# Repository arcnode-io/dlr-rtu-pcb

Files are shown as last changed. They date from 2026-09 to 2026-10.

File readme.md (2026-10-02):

# DLR RTU PCB 🌡️⚡







> Single-PCB CM4 carrier for a solar-powered, cellular-connected RTU — mounts to a transmission tower cross-arm, integrates SoM + cellular modem + IEEE 738 sensor suite + solar/LiFePO4 power management. Feeds [`dlr-rtu-firmware`](https://gitlab.com/arcnode-io/dlr-rtu-firmware).

Solar-powered remote terminal unit (RTU) deployed unattended on transmission tower cross-arms. A ~20W solar panel and ~50Wh LiFePO4 battery keep the CM4 running indefinitely with cellular PSM idle. A soldered Quectel BG770A (LTE Cat-M1) publishes sensor data and dynamic ratings to the MQTT broker — no site WiFi or wired backhaul required. The unit is designed for 30-year conductor-adjacent deployment with no scheduled maintenance.

~100x80mm 4-layer industrial carrier. Raspberry Pi CM4 (DF40 dual-connector) + Quectel BG770A LCC + FLIR Lepton 3.5 (SPI) + DHT22 (GPIO) + SI1145 (I2C) + YL-83 (analog via ADS1115). MPPT charger from PV input, LiFePO4 BMS, buck for 5V SoM rail, AP2112K LDO for 3.3V analog front-end. Conformal coated, IP55 when potted in field enclosure.

## System Context

```plantuml
rectangle transmission_tower {
  rectangle field_enclosure {
    rectangle dlr_carrier {
      rectangle cm4_som
      rectangle cellular_module
      rectangle sensors
      rectangle power_mgmt
    }
  }
  rectangle solar_panel
  rectangle lifepo4_battery
  rectangle conductor
}

queue mqtt_broker
rectangle dispatch_api

solar_panel -d- power_mgmt: PV input
power_mgmt -l- lifepo4_battery: charge / discharge
power_mgmt -d- cm4_som: 5V / 3V3
conductor -u- sensors: thermal view\n(FLIR Lepton)
sensors -r- cm4_som: SPI / I2C / GPIO
cm4_som -r- cellular_module: UART + USB2
cellular_module -r- mqtt_broker: LTE Cat-M1
mqtt_broker -r- dispatch_api: dynamic line rating\n(utility/dlr/...)
```

The carrier is the physical sensing + edge-compute layer of the DLR feedback loop. Every measurement flows through the IEEE 738 calculation in [`dlr-rtu-firmware`](https://gitlab.com/arcnode-io/dlr-rtu-firmware), which publishes the resulting dynamic line rating for `mock-derms-dispatch-api`'s DER curtailment trigger.

## Board Spec

```mermaid
graph LR
    SOLAR["Solar Panel<br/>~20W 12V"] --> MPPT["BQ24650 MPPT<br/>+ 2x DMN4035L"]
    MPPT --> BAT["LiFePO4 4S<br/>~50Wh + BMS"]
    BAT --> BUCK["Buck<br/>5V 3A"]
    BUCK --> CM4["CM4 SoM<br/>DF40 x2"]
    BUCK --> BG["Quectel BG770A<br/>Cat-M1 LCC"]
    BUCK --> LDO["AP2112K<br/>3.3V LDO"]
    LDO --> ADC["ADS1115<br/>I2C 0x48"]
    LDO --> UV["SI1145<br/>I2C 0x60"]
    CM4 --> FLIR["FLIR Lepton 3.5<br/>SPI0 + GPIO25"]
    CM4 --> DHT["DHT22<br/>GPIO4"]
    CM4 --> ADC
    CM4 --> UV
    ADC --> RAIN["YL-83<br/>Analog 0-3.3V"]

    style SOLAR fill:#dc4,stroke:#333
    style MPPT fill:#a94,stroke:#333
    style BAT fill:#a94,stroke:#333
    style BUCK fill:#a94,stroke:#333
    style LDO fill:#a94,stroke:#333
    style CM4 fill:#4a9,stroke:#333,color:#fff
    style BG fill:#49a,stroke:#333,color:#fff
    style FLIR fill:#49a,stroke:#333,color:#fff
    style DHT fill:#94a,stroke:#333,color:#fff
    style ADC fill:#94a,stroke:#333,color:#fff
    style UV fill:#94a,stroke:#333,color:#fff
    style RAIN fill:#669,stroke:#333,color:#fff
```

## CM4 Pinout

```mermaid
flowchart LR
classDef default fill:transparent,stroke:#333
classDef pwr fill:#4a9,stroke:#333,color:#fff
classDef spi fill:#49a,stroke:#333,color:#fff
classDef i2c fill:#94a,stroke:#333,color:#fff
classDef gpio fill:#a94,stroke:#333,color:#fff
classDef uart fill:#a49,stroke:#333,color:#fff
classDef usb fill:#669,stroke:#333,color:#fff

subgraph cm4 ["CM4 (DF40-100)"]
  p_5v["5V_IN"]
  p_sda["GPIO2 SDA1"]
  p_scl["GPIO3 SCL1"]
  p_g4["GPIO4"]
  p_g25["GPIO25"]
  p_mosi["GPIO10 MOSI"]
  p_miso["GPIO9 MISO"]
  p_sck["GPIO11 SCLK"]
  p_ce0["GPIO8 CE0"]
  p_txd["GPIO14 TXD"]
  p_rxd["GPIO15 RXD"]
  p_usb["USB2 D+/D-"]
end

subgraph onboard ["Carrier Components"]
  flir["FLIR Lepton 3.5"]
  dht["DHT22"]
  si["SI1145"]
  ads["ADS1115"]
  yl["YL-83"]
  bg["BG770A"]
end

p_mosi --> flir
p_miso --> flir
p_sck --> flir
p_ce0 --> flir
p_g25 --> flir
p_g4 --> dht
p_sda --> si
p_scl --> si
p_sda --> ads
p_scl --> ads
ads --> yl
p_txd --> bg
p_rxd --> bg
p_usb --> bg

class p_5v pwr
class p_mosi,p_miso,p_sck,p_ce0 spi
class p_sda,p_scl i2c
class p_g4,p_g25 gpio
class p_txd,p_rxd uart
class p_usb usb
```

## Sensor Interfaces

| Sensor | Interface | CM4 Pins | Sample Rate | Measurement | Feeds IEEE 738 Variable |
|---|---|---|---|---|---|
| FLIR Lepton 3.5 | SPI0 + VSYNC | GPIO 8, 9, 10, 11, 25 | 8.6 Hz (frame) | Conductor surface temp | $R_{thermal}$ |
| DHT22 | GPIO4 (1-Wire) | GPIO 4 | 0.5 Hz | Ambient temp + humidity | $T_{amb}$ |
| SI1145 | I2C (0x60) | GPIO 2, 3 | 10 Hz | UV / Visible / IR irradiance | $\Delta T_{solar}$ |
| YL-83 → ADS1115 | I2C (0x48) ch0 | GPIO 2, 3 | 860 SPS | Rain intensity (0–3.3V analog) | $\Delta T_{rain}$ |

Every sensor reading on this board maps to exactly one term in the IEEE 738 dynamic rating equation:

$$ I_{max} = \sqrt{\frac{q_c + q_r - q_s}{R_{ac}}} $$

## Anemometer Variants

Single PCB + single firmware binary. Variant lives in the **kit BOM** — sensor,
cable harness, PV panel, and battery differ per SKU. Both sensors speak
NMEA 0183 (`$..MWV`) over RS-485, so the firmware driver is talker-agnostic.

### Kit BOM

| Component | High-wind kit (`DLR-CRN-HW`) | Low-wind kit (`DLR-CRN-LW`) |
|---|---|---|
| PCB | `dlr-rtu-pcb-v1` (same) | `dlr-rtu-pcb-v1` (same) |
| Firmware | `dlr-rtu-firmware` (same binary) | `dlr-rtu-firmware` (same binary) |
| Sensor | Calypso ULP STD | Vaisala WMT702 |
| Sensor wire protocol | NMEA `$IIMWV` over RS-485 | NMEA `$WIMWV` over RS-485 |
| Sensor accuracy (V<2 m/s) | ±5 % + 0.2 m/s offset (1 m/s threshold) | **±0.1 m/s** (0.01 m/s threshold) |
| Sensor op temp | unspecified (consumer-grade) | -10 to +60 °C |
| Cable harness | 5 m bare-wire to M12-5P | 5 m Cannon Trident 19-way to M12-5P |
| PV panel | 20 W | **30 W** |
| Battery | 50 Wh LiFePO4 | **100 Wh LiFePO4** |
| Sticker | `HW-1.0` | `LW-1.0` |
| Kit cost (approx) | ~$650 | ~$2350 |

### When to deploy which variant

Per-site SKU pick uses NREL WIND Toolkit climatology (or customer SCADA wx
history when available). Threshold: fraction-of-year with V_w < 1 m/s
perpendicular to conductor.

| Climatology | Variant | Why |
|---|---|---|
| ≤ 15 % yr V_w < 1 m/s (ridge / coastal / open plain w/ mean ≥ 6 m/s) | high-wind | uplift slice below 1 m/s is marginal; static fallback below threshold is fine |
| > 15 % yr V_w < 1 m/s (valley / sheltered / open plain w/ mean ≤ 5 m/s) | low-wind | uplift slice is material; pay $1.7 k premium to capture it |

### Fallback policy (both variants)

When the sensor reports `void` status, times out, or has a checksum/parse
error, the driver returns `None`. The IEEE 738 layer collapses None →
`V_w = 0.0` → natural-convection-only ampacity = the conductor's static
rating. Same conservative fallback used for the icing-fallback policy.

### Variant power budget

| | High-wind | Low-wind |
|---|---|---|
| Sensor continuous draw | 1 mW | 480 mW |
| System daily energy | 29.1 Wh | 40.6 Wh |
| Winter PV harvest (worst) | 45 Wh | 67.5 Wh |
| Winter margin | 1.55× | **1.66×** |
| Battery autonomy at 0 PV | 1.58 d | **2.22 d** |

Low-wind variant's 30 W / 100 Wh upgrade absorbs the WMT702's higher draw and
restores both winter margin and 2-day autonomy.

## Power Budget

| Rail | Source | Consumer | Idle (PSM) | Typical | Peak |
|---|---|---|---|---|---|
| 5V | Buck | CM4 | 80 mA | 1400 mA | 3000 mA (boot) |
| 5V | Buck | Quectel BG770A | <1 mA | 100 mA | 250 mA (TX) |
| 5V | Buck | FLIR Lepton 3.5 | 150 mA | 150 mA | 650 mA (shutter) |
| 5V | Buck | DHT22 | 1.5 mA | 1.5 mA | 2.5 mA |
| 3.3V | AP2112K LDO | ADS1115 + SI1145 + YL-83 | 9 mA | 9 mA | 14 mA |
| | | **Total @ 5V equiv** | **240 mA** | **1660 mA** | **3920 mA** |

The 3920 mA peak is a worst-case *sum*, not a supported operating point. The LMR33630 delivers 3.375 A with worst-case silicon, so a coincident CM4-boot + Lepton-shutter + modem-TX peak browns the rail out below the CM4's 4.75 V floor — firmware sequences those loads apart (**ADR-017**, derived in `theory.ipynb` §7 and asserted in `sim/test_spice.py`). The CM4 boot peak on its own holds the rail at ~4.95 V.

Daily energy with CM4-always-on idle + 1/min sensor wake + 1/15 min cellular TX: **~29 Wh/day** (derived in `theory.ipynb`). A 50 Wh battery (90% DoD) gives ~1.6 days autonomy with no PV. A 20W panel at 2.5 sun-hours/day (winter Northeast US worst case) delivers ~45 Wh/day after MPPT η — **1.55x winter margin**, 2.5x annual avg.

That margin assumes a 120 mA CM4 idle (tuned Pi OS Lite, headless). The CM4 datasheet §5.3 quotes ~400 mA typical idle; at that figure the budget is 62.6 Wh/day and the 20 W panel does **not** carry winter (0.72x). Idle current is the single measurement that most needs a bench check before committing to the panel size.

## Environmental

| Parameter | Spec | Notes |
|---|---|---|
| Operating temp | -20°C to +85°C | CM4 commercial spec; cold-start heater required below -20°C |
| Conformal coat | Dow Corning 1-2577 | Applied post-assembly, mask connectors |
| Enclosure rating | IP55 (with field enclosure) | Board alone is not rated |
| Vibration | IEC 60068-2-6 (5–500 Hz, 2g) | Transmission tower wind loading |
| Expected service life | 30 years | Matches conductor replacement cycle |
| MTBF | >200,000 hours | Derated per MIL-HDBK-217F |
| Mounting | M3 standoffs, 4-corner | Single rigid PCB — no stack |

## Fabrication Pipeline

Fully scripted — no GUI step. KiCad's "Update PCB from Schematic" is GUI-only, so `cad/drawing/sync_pcb.py` does the same job from the SKiDL netlist: it rebuilds every footprint from the library and reassigns every pad net, which is what keeps the board honest about what the schematic says.

```
 1. uv run poe notebook         → theory.ipynb: power, signal integrity, 5V transients
 2. uv run poe build            → SKiDL netlist
 3. uv run poe schematic        → hierarchical .kicad_sch (one sheet per block)
 4. uv run poe validate-model   → ERC, 0 violations (exits non-zero otherwise)
 5. uv run poe sim / cover      → pytest: hand calcs + ngspice transients

 6. uv run poe layout-asm       → the whole board flow, in order:
      build       netlist from SKiDL
      sync-asm    footprints + pad nets  <- replaces the GUI "Update PCB from Schematic"
      place-asm   positions from cad/pcb_placement.yaml
      setup-asm   4-layer stack, design rules, net classes, GND + 5V planes
      fanout-asm  escape vias for the 0.4 mm connector, assigned before routing
      route-asm   Specctra DSN -> Freerouting -> SES import -> zone fill
      stitch-asm  vias from surface pads to their plane
      validate-asm DRC, 0 violations

    ┌──────────────────────────────────────────────────────┐
    │  HUMAN: review the render, adjust pcb_placement.yaml │
    └──────────────────────────────────────────────────────┘

 7. uv run poe generate-asm     → gerbers + drill + STEP + BOM + CPL
```

### Board status

ERC is 0. DRC is clean of clearance, short, annular-ring, hole and courtyard errors —
what is left is 7 silkscreen-overlap warnings and **2 open connections** out of 457
pads, both of them ground pins on J5 (Hirose DF40, 0.4 mm pitch):

| Net | Pad | At (mm) |
|---|---|---|
| GND | J5.20 | 197.80, 94.46 |
| GND | J5.25 | 199.00, 97.54 |

Both are redundant pins — the CM4 bonds its grounds internally — so what is missing is
return-path quality at that corner of the connector, not a broken net. It is still a
DRC error, so the gerbers in `output/` stay a preview until it closes.

**Why they are open.** It is a fanout-capacity limit, not a search failure. A row of
0.6 mm escape vias needs 0.75 mm centre to centre, so on a 0.4 mm pad pitch only every
other pin gets a via in the first row. The pins that miss out have to reach a second,
deeper row — but two 0.6 mm vias 0.75 mm apart leave a 0.15 mm slot, and a 0.2 mm trace
with 0.15 mm clearance needs 0.5 mm. **Once the first row is populated the second row is
unreachable.** Via rows have to be assigned before any routing happens; a router that
picks the nearest free site per pin always finishes one slot short.

`cad/drawing/fanout.py` does that assignment: it clears the connector's fanout band and
alternates along each pad row, one pin into the inter-row gap, the next out the back, so
same-side vias land 0.8 mm apart. It places all 39 escapes on J5 with zero clearance,
short or drill violations — the geometry works.

What is *not* done is the rebuild. Run on a board that is already routed, the pass has
to clear 223 tracks and vias to own its band, and `escape_pins` rebuilds only 23 of the
35 connections that leaves open — a net regression against the 2 here. Its place is
before Freerouting, where a full-strength router does the reconnection, which is where
`poe layout-asm` now calls it. **That path has not been run end to end yet**, so the
board in this repo is still the pre-fanout one. Closing the last two means either that
full regeneration, or 0.45 / 0.25 mm vias (JLCPCB advanced tier, and the 0.13 mm
annular-ring rule would have to come down with them), or six layers.

### Toolchain

**KiCad 10 required.** The board is KiCad 10 format (`20260206`); on KiCad 9
`poe validate-asm` says DRC could not run rather than passing silently. The CI
runner gets 10.x from Flatpak. The schematic is format `20250114`, which both
versions read.

ERC is a blocking gate in CI. DRC runs and reports but does not gate yet — the two
open ground pins above are real errors; the `|| echo` comes off once they are closed.

## Layer Stack

4-layer, 1.6 mm FR4, controlled impedance (ADR-016). Applied by `cad/drawing/board_setup.py`, so a regenerated board always has the same stack.

| Layer | Use |
|---|-----|
| F.Cu | Signal — high-speed (SPI 20MHz, USB2.0 to BG770A) |
| In1.Cu | GND plane, unbroken (reference for the USB pair and the Lepton SPI) |
| In2.Cu | 5V_RAIL plane — CM4, both LDOs and the Lepton feed off it via drops |
| B.Cu | Signal — low-speed (I2C, GPIO, UART) |

Signals are confined to F.Cu / B.Cu: the router is told the inner layers are `power` type, so nothing slices a plane. VBAT, 3V3 and 3V8 run as 0.6 mm traces (`power` net class), necked to 0.25/0.2 mm where an escape has to squeeze past a 0.4 mm-pitch pad. Every via is 0.6/0.3 mm: a 0.5/0.25 mm via would ease the DF40 fanout but leaves a 0.125 mm annular ring, under the 0.13 mm rule.

Unbroken ground plane under the Lepton is critical — SPI runs at 20 MHz and the thermal imager is noise-sensitive. USB2.0 to the BG770A is differential-routed at 90Ω matched impedance with GND directly below. Analog traces from YL-83 to ADS1115 are guard-ringed on F.Cu. Cellular antenna is 50Ω microstrip to a u.FL connector.

## Project Structure

```
├── pyproject.toml              # Dependencies and build config
├── theory.ipynb                # Power, signal integrity, 5V transient derivations
├── sim/
│   ├── constants.py            # Sourced part parameters (datasheet + edition cited)
│   ├── model.py                # Closed-form: buck current, energy, I2C/SPI/USB
│   ├── spice_bank.py           # Shared 5V output capacitor bank
│   ├── spice_ripple.py         # ngspice: open-loop switching ripple (Eq 7)
│   ├── spice_load_step.py      # ngspice: averaged current-mode boot-peak droop
│   ├── test_run.py             # Assert closed-form results match theory.ipynb
│   └── test_spice.py           # Assert ngspice results match theory.ipynb §7
├── cad/
│   ├── netlist/
│   │   ├── model.py            # Top-level SKiDL circuit (main carrier)
│   │   ├── charger.py          # Solar input + BQ24650 MPPT charger (ADR-015)
│   │   ├── power.py            # LMR33630 5V buck + AP2112K / LP5907 LDOs
│   │   ├── som.py              # CM4 DF40 connector + decoupling
│   │   ├── cellular.py         # BG770A + SIM holder + u.FL
│   │   ├── sensors.py          # FLIR (FFC), DHT22, SI1145, ADS1115, YL-83
│   │   ├── anemometer.py       # RS-485 wind sensor port (SKU-agnostic)
│   │   ├── connectors.py       # Battery + debug + USB-C commissioning
│   │   └── lepton_daughter.py  # Daughterboard SKiDL (Molex socket + FFC)
│   ├── schematic/              # Hierarchical .kicad_sch generator
│   │   ├── schematic.py        # Netlist parse, block classification, placement
│   │   ├── multi_sheet.py      # Per-block child sheets, power symbols, PWR_FLAG
│   │   ├── root_sheet.py       # Root sheet + cross-net sheet pins
│   │   └── sch_guard.py        # Fails the build on cross-net wire/pin collisions
│   ├── drawing/                # Board pipeline (system python3 — pcbnew)
│   │   ├── sync_pcb.py         # Footprints + pad nets from the netlist
│   │   ├── place_pcb.py        # Positions from pcb_placement.yaml
│   │   ├── board_setup.py      # 4-layer stack, rules, net classes, planes
│   │   ├── route_pcb.py        # DSN -> Freerouting -> SES -> fill
│   │   ├── fanout.py           # Pre-assigned escape vias for fine-pitch connectors
│   │   ├── stitch_planes.py    # Surface-pad vias into the planes
│   │   ├── close_gaps.py       # L-shaped hops across the autorouter's leftovers
│   │   ├── maze_grid.py        # Grid window shared by the escape router
│   │   ├── maze_field.py       # Analytic clearance fields (foreign copper only)
│   │   ├── maze_search.py      # Grid A*, 8-way, with via layer changes
│   │   ├── maze_escape.py      # Route + verify one connection, or tear it out again
│   │   ├── escape_pins.py      # Drives the escape router off the DRC report
│   │   ├── rip_targets.py      # Finds a stranded pin's blockers; performs the rip
│   │   └── rip_up.py           # Rip / re-route / keep-only-if-better loop
│   ├── lepton_daughter/        # Second PCB (per ADR-013) — Lepton + bracket
│   ├── assembly/               # CadQuery → GLB pipeline (build_assembly.py)
│   ├── layout_spec.yaml        # Schematic block layout
│   ├── pcb_placement.yaml      # Main-PCB component positions
│   └── drawing-sheet.kicad_wks # Title block
├── output/
│   ├── drawings/               # Schematic SVG + PDF
│   ├── gerbers/                # Fabrication files
│   └── fab/                    # BOM + CPL for assembly
└── readme.md                   # This file
```

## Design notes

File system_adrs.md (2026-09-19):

# DLR Carrier Board — Architecture Decision Records

Captures architectural and component decisions for the DLR PCB. New decisions append as ADR-NNN; supersedes are explicit. Date format ISO 8601.

## Index

| # | Decision | Class |
|---|---|---|
| 001 | Single-PCB CM4 carrier | Architecture |
| 002 | Battery — LiFePO4 4S | Architecture |
| 003 | Cellular bands — NA-only | Architecture |
| 004 | Solar panel — 20W | Architecture |
| 005 | I2C clock — 400 kHz | Architecture |
| 006 | Antenna form — u.FL + external blade | Architecture |
| 007 | 5V buck — TI LMR33630 | Component |
| 008 | MPPT charger — TI BQ24650 | Component |
| 009 | BMS — JBD-SP04S013 (on-pack) | Component |
| 010 | BG770A 3.8V LDO — TI LP5907 | Component |
| 011 | Level shifter — TI TXS0108E | Component |
| 012 | u.FL connector — Hirose U.FL-R-SMT-1(10) | Component |
| 013 | Lepton daughterboard for aim flexibility | Architecture |
| 014 | 5V buck inductor — Bourns SRN8040TA-100M | Component |
| 015 | MPPT charger support network — BQ24650 per SLUSA75B | Architecture |
| 016 | Layer stack — 4-layer SIG / GND / 5V / SIG | Architecture |
| 017 | 5V rail load sequencing — firmware constraint | Architecture |

---

## ADR-001: Single-PCB CM4 Carrier (vs Pi HAT)

**Status:** Accepted **Date:** 2026-05-08

### Context
30-yr maintenance-free transmission tower deployment, IP55 potted enclosure, IEC 60068-2-6 vibration (5–500 Hz, 2g), −20 to +85°C operating temp, solar+LiFePO4 budget. Initial readme proposed a Pi 5 HAT stack.

### Decision
Single-PCB ~100×80mm 4-layer carrier with Raspberry Pi CM4 mounted via DF40 connector pair. All cellular, sensor, and power-management circuitry on the same board.

### Rationale
- Pi 5 is consumer-grade (0–50°C) and won't survive spec'd environment
- 40-pin HAT stack is a vibration failure mode (connector fretting + lever arm)
- Stock Pi has unused HDMI/audio/USB hub circuitry burning solar budget for 30 yrs
- USB-A cellular dongles are the worst industrial connector
- Conformal-coating a Pi is messy (HDMI/USB ports = giant openings)

### Alternatives Considered
| Option | Tradeoff |
|---|---|
| Pi HAT stack | Faster iteration, fails environment spec |
| iMX6ULL or STM32MP1 SoM | More industrial pedigree, worse software ecosystem, longer integration |
| STM32H7 + PSRAM (no Linux) | Lowest power, ~6 mo firmware vs ~3 wk Python |

### Consequences
- 4-layer 1.6mm board with controlled impedance (50Ω microstrip + 90Ω diff)
- Operating temp pinned at −20 to +85°C (CM4 commercial spec)
- Cold-start heater needed below −20°C
- All schematic + layout effort owned by us

---

## ADR-002: Battery — LiFePO4 4S

**Status:** Accepted **Date:** 2026-05-08

### Context
Outdoor solar-powered RTU with 30-yr cycle life. Battery range must be compatible with downstream buck Vin.

### Decision
4S LiFePO4 pack: V_min = 10.0V, V_nom = 12.8V, V_max = 14.6V. 4 Ah cell → ~50 Wh nominal.

### Rationale
4S sits in the Vin range of common 12V-class bucks with transient margin. LiFePO4 has 90% DoD tolerance, 3000+ cycle life, and cold-temp safety (no thermal runaway risk in a sealed enclosure).

### Alternatives Considered
| Option | Tradeoff |
|---|---|
| LiFePO4 3S (9.6V nom) | Cheaper, but 7.5V cutoff below most buck Vin specs |
| Li-ion 3S | Higher energy density, worse thermal safety |
| Lead-acid | Cheap, heavy, low cycle life, poor cold-temp |

### Consequences
- Buck must accept 10.0–14.6V continuously (1.46x ratio)
- BMS must handle 4-cell balancing + 0°C low-temp charge cutoff
- 50 Wh autonomy = 1.58 days at zero PV → flagged for upgrade to 100 Wh

---

## ADR-003: Cellular Bands — NA-Only

**Status:** Accepted **Date:** 2026-05-08

### Context
Cat-M1 RTU deployment scoped to North American utility customers initially. Module SKU + antenna selection depend on band targets.

### Decision
NA-only Cat-M1 bands: B12/B13/B71/B85 (600–960 MHz LB).

### Rationale
NA-only narrows BG770A SKU choice (BG770A-NA), reduces antenna BOM (single LB element vs multiband), avoids global certification cost (FCC/IC only).

### Alternatives Considered
| Option | Tradeoff |
|---|---|
| Global multiband | Larger antenna, dual-band cert, higher cost, premature for utility scope |
| EU + NA | Splits cert effort, no current customer pull |

### Consequences
- BG770A-NA SKU only
- Antenna spec: 600–960 MHz, ~3 dBi, single-band blade
- Future global expansion = new SKU + new antenna (acceptable)

---

## ADR-004: Solar Panel — 20W

**Status:** Accepted **Date:** 2026-05-08

### Context
Daily energy budget at 1/min sampling + 1/15-min cellular TX = 29.1 Wh/day (theory.ipynb). Need PV sizing for ≥1.5x winter margin.

### Decision
20W mono panel, ~17V Vmp, ~21V Voc.

### Rationale
20W × 2.5 sun-hours × 0.90 MPPT η = 45 Wh/day winter worst case = 1.55x margin over 29 Wh/day budget. Annual avg = 2.5x. Panel envelope (~30×40 cm, ~2 kg) is mechanically reasonable for a tower cross-arm.

### Alternatives Considered
| Option | Tradeoff |
|---|---|
| 10W panel | Insufficient — winter margin <1x |
| 30–40W panel | Larger envelope, unnecessary for IEEE 738 sample rate |

### Consequences
- MPPT charger Vin range must cover 17V Vmp comfortably (5–28V is fine)
- Panel mounting hardware sized for ~2 kg + wind/ice loading
- If sample rate ever bumps to 1Hz, panel must scale to ~125W (separate ADR)

---

## ADR-005: I2C Clock — 400 kHz

**Status:** Accepted **Date:** 2026-05-08

### Context
On-board I2C bus carries ADS1115 (0x48) + SI1145 (0x60) + 2 spare slots. Pull-up sizing depends on clock rate.

### Decision
400 kHz fast mode (UM10204 Rev 7.0).

### Rationale
ADS1115 supports up to 3.4 MHz, SI1145 up to 400 kHz. Fast mode is the highest rate the slowest device supports. With 75 pF estimated C_bus and 2.2 kΩ pull-ups, rise time = 140 ns vs 300 ns spec (53% margin).

### Alternatives Considered
| Option | Tradeoff |
|---|---|
| 100 kHz standard mode | Larger pull-ups OK, but slower readings limit sensor poll rate headroom |
| 1 MHz fast-mode-plus | SI1145 exceeded; would force discrete buffer per device |

### Consequences
- 2.2 kΩ pull-ups on SDA/SCL (E24, in 967Ω–4.72kΩ range)
- C_bus budget: 75 pF (verify after layout)

---

## ADR-006: Antenna Form — u.FL + External Blade

**Status:** Accepted **Date:** 2026-05-08

### Context
Tower-top deployment needs reliable RF link to a Cat-M1 base station. Antenna choice trades cost vs gain vs durability.

### Decision
On-board u.FL connector → external pigtail (RG316) → N-female bulkhead → external blade antenna.

### Rationale
u.FL is the canonical cellular module connector; pigtail to N-female bulkhead gives mechanical robustness at the enclosure wall. External blade provides ~3 dBi at 600–960 MHz vs negative gain for an internal PCB trace antenna.

### Alternatives Considered
| Option | Tradeoff |
|---|---|
| On-board PCB trace antenna (Taoglas FXUB63) | No external connector, but gain too low for tower-top |
| MMCX/SMA on-board (no pigtail) | More robust mechanically, 10× footprint, overkill inside potted enclosure |
| Whip with magnetic base | Won't work on transmission tower (lattice, not steel) |

### Consequences
- 50Ω microstrip from BG770A ANT to u.FL (≤30 mm preferred per theory section 5)
- External antenna + pigtail are accessories, specified at integration time
- Pi-network footprint provisioned on-board for VSWR tuning during EVT

---

## ADR-007: 5V Buck — TI LMR33630ADDAR

**Status:** Accepted **Date:** 2026-05-08

### Context
Battery 10–14.6V → 5V/3A continuous + 3.92A boot inrush. Sits upstream of CM4 + BG770A LDO + sensors.

### Decision
TI LMR33630ADDAR, HSOIC-8, programmable Fsw=400 kHz, paired with 470 µF aluminum polymer bulk cap on 5V to absorb CM4 boot inrush.

### Rationale
3.8–36V Vin = huge headroom over 14.6V max. 3A integrated synchronous FETs, ~92% peak η, industrial −40 to +125°C, hand-solderable, ~$1.50.

### Alternatives Considered
| Option | Tradeoff |
|---|---|
| TI TPS62133 | Smaller QFN, but Vin tops at 15V — only 0.4V margin over V_BAT_MAX |
| TI TPS54331 | Asynchronous → ~80% light-load η, hurts PSM idle budget |
| LM2596 (legacy) | Cheap + ubiquitous, ~75% η wastes 25% of solar budget |
| MPS MP2459 | Undersized at <1A |

### Consequences
- Bulk cap on 5V rail is mandatory (boot inrush mitigation)
- Programmable Fsw lets us trade efficiency vs component size at layout time
- 92% efficiency vs 90% theory assumption gives small headroom in derivation

---

## ADR-008: MPPT Charger — TI BQ24650RVAR

**Status:** Accepted **Date:** 2026-05-08

### Context
20W panel input → 4S LiFePO4 charge. Needs true MPPT (not just input-voltage regulation) and adjustable charge profile.

### Decision
TI BQ24650RVAR, VQFN-16. R_SR = 20 mΩ for 2A charge (0.5C of 4 Ah cell). VINREG set to 16.8V (~80% of Voc). VFB divider gives 14.6V V_charge.

### Rationale
True MPPT buck charger via VINREG pin (not just CV input regulation). 5–28V Vin covers 17V Vmp + transients. Programmable charge V/I via resistor dividers. Industrial −40 to +85.

### Alternatives Considered
| Option | Tradeoff |
|---|---|
| LTC4015 | LiFePO4-aware + I²C telemetry, but 2× cost + 38-pin QFN, overkill |
| MP2731 | Cheap, designed for 1S phone use case — won't drive 4S/14.6V |
| CN3791 | Asian-market chip, sparse docs, max 8.4V output (2S only) |
| Discrete LT3652 + LTC4054 | Most flexible, but 2 ICs + more passives, harder to debug |

### Consequences
- Cell balancing + low-temp cutoff are NOT in BQ24650 → handled by separate BMS (ADR-009)
- TS pin can monitor pack NTC; partially overlaps with BMS — leave NC unless needed
- R_SR = 20 mΩ ±1% sense resistor required

---

## ADR-009: BMS — JBD-SP04S013 (On-Pack)

**Status:** Accepted **Date:** 2026-05-08

### Context
LiFePO4 4S pack needs cell balancing + per-cell over/undervoltage cutoff + low-temp charge inhibit (charging below 0°C destroys LiFePO4 cells permanently).

### Decision
JBD-SP04S013 (or equivalent commoditized 4S LiFePO4 BMS PCB), mounted **physically on the battery pack**, NOT on the carrier PCB. 15A continuous discharge, balancing, 0°C low-temp cutoff, ~150 µA quiescent, ~$8.

### Rationale
Designing a discrete BMS on the carrier multiplies layout complexity, MOSFET sourcing risk, and validation effort for a problem that's already commoditized. On-pack mounting means the carrier sees only `BAT+`/`BAT-` — drastically simpler PCB.

### Alternatives Considered
| Option | Tradeoff |
|---|---|
| Discrete on-carrier (TI BQ77216 + dual N-FETs) | ~6 ICs + 8 FETs + 30 passives added; ~3 wks of layout + validation |
| Discrete on-carrier (Analog Devices LTC6804) | Best-in-class, $15 IC, designed for EV/grid storage — massive overkill |
| No BMS | NEVER acceptable — cell imbalance kills LiFePO4 in <100 cycles |
| Bioenno BLF-1204AS (battery + BMS combined) | Zero design effort but 3× cost, locks vendor |

### Consequences
- Carrier PCB has 2-pin battery input only (no cell sense lines, no protection FETs)
- Battery is a swappable assembly serviced separately — better 30-yr maintenance story
- BMS quiescent (150 µA × 12.8V × 24h = 0.046 Wh/day) is negligible vs 29 Wh/day budget

---

## ADR-010: BG770A 3.8V LDO — TI LP5907MFX-3.8

**Status:** Accepted **Date:** 2026-05-08

### Context
BG770A VBAT spec is 3.4–4.3V (Li-ion class). Cannot power directly from 4S battery (10–14.6V) or 5V buck. Cellular RF is sensitive to LDO ripple.

### Decision
TI LP5907MFX-3.8, SOT-23-5. Fixed 3.8V output (no resistor divider), 250 mA, 6.5 µVrms ultra-low-noise, 16 µA quiescent.

### Rationale
LP5907 is the LDO Quectel's BG770A hardware design guide explicitly recommends. Fixed 3.8V SKU exactly matches Quectel's typical, no divider drift. Ultra-low noise prevents desensing the cellular receiver.

### Alternatives Considered
| Option | Tradeoff |
|---|---|
| MPS MP2161 (3.8V buck from 5V) | Higher η, but switching noise into RF chain — needs filtering, not worth it for ~0.18 Wh/day savings |
| TPS73801 (adjustable LDO) | 1A capacity, but higher quiescent + divider drift |
| AP2112-3.3 (re-use 3V3 LDO) | Below BG770A's 3.4V minimum — TX brownouts |
| Adjustable LDO from battery direct | 12V × 250mA peak = 3.6W heat, thermally infeasible |

### Consequences
- Daily energy budget already accounts for BG770A draw at 5V-equivalent (LDO η ~80%)
- LP5907 EN pin wired to a CM4 GPIO → power-cycle option for stuck cellular state
- 250 mA capacity covers TX peaks with margin

---

## ADR-011: Level Shifter — TI TXS0108E

**Status:** Accepted **Date:** 2026-05-08

### Context
CM4 GPIO is 3.3V CMOS, BG770A I/O is 1.8V CMOS. 8 lines need shifting: TXD, RXD, PWRKEY, RESET, DTR, STATUS, NETLIGHT, RING. (USB doesn't need shifting — USB 2.0 spec on both sides.)

### Decision
TI TXS0108E, TSSOP-20. 8-channel auto-direction-sensing, OD-compatible, 1.65–5.5V on either side, ~1.2 Mbps OD / 50 Mbps push-pull.

### Rationale
Mixed signal types on BG770A side (some OD outputs) — TXS0108E handles both. Single-IC vs 16 discrete transistors. Auto-direction means no DIR pin to manage. Quectel reference designs use this part.

### Alternatives Considered
| Option | Tradeoff |
|---|---|
| TI TXB0108 | Stronger push-pull drive, but fails on OD signals — risky if STATUS/NETLIGHT are OD |
| Discrete BSS138 + 10kΩ pulls | Cheapest, but 16 transistors + 16 resistors = 50× layout area |
| 4× SN74LVC1T45 single-channel | Per-channel direction control, but 4 ICs + 4 GPIOs consumed |
| Series resistor only | Will damage BG770A inputs over time via protection diodes |

### Consequences
- VccA = 1.8V (sourced from BG770A VDD_EXT, ~50 mA available)
- VccB = 3.3V (from existing AP2112K)
- OE pin → CM4 GPIO with pull-down for boot-time isolation
- 100 nF decoupling on each Vcc

---

## ADR-012: u.FL Connector — Hirose U.FL-R-SMT-1(10) + Pi-Match

**Status:** Accepted **Date:** 2026-05-08

### Context
On-board RF chain from BG770A ANT pin to external pigtail. Form-factor decision (ADR-006) selected u.FL; this ADR pins the specific connector and matching topology.

### Decision
Hirose U.FL-R-SMT-1(10) connector + 3-pad Pi-network footprint between BG770A ANT and u.FL. Default: 0Ω series jumper, NC/NC shunts. Components populated only if EVT VSWR testing requires.

### Rationale
Hirose is the canonical industry u.FL — every cellular module reference design uses it. Pi-network footprint is free in layout space and preserves tuning option without a respin.

### Alternatives Considered
| Option | Tradeoff |
|---|---|
| Molex 73412-0110 | Functionally equivalent, sometimes better-stocked, but pigtails specced for Hirose may not seat as well |
| Skip Pi-network, direct trace | One less footprint, but no recourse if VSWR is bad at EVT |
| MMCX/SMA on-board | More robust mechanically, but 10× area + 4–5× cost, overkill inside potted enclosure |

### Consequences
- 50Ω microstrip from BG770A ANT → Pi-network → u.FL center pin
- u.FL placed near board edge for pigtail clearance + 10×10mm keepout for cable bend radius
- Off-board accessories (pigtail + N-female bulkhead + blade antenna) specified at integration, not PCB design

---

## ADR-013: Lepton Daughterboard for Aim Flexibility

**Status:** Accepted **Date:** 2026-05-10

### Context
ADR-001 mandated a single-PCB carrier with all sensor, cellular, and power-management circuitry on one board, motivated by stacked-Pi-HAT vibration failures over 30-yr deployments. Cross-arm DLR deployment requires the FLIR Lepton 3.5 lens to aim at a conductor ~1.5 m below the cross-arm; with a sky-facing solar panel constraint and the lens perpendicular to the main PCB, no monolithic-board orientation satisfies both.

### Decision
Split the Lepton onto a small (~25 × 40 mm) daughterboard linked to the main PCB by a 14-pin 0.5 mm-pitch FFC. Daughterboard mounts to a sheet-metal bracket with M3 pivot + M3 arc-slot lock, allowing ±15° aim adjustment at integration time. Sealed industrial USB-C commissioning port on the main carrier provides live thermal preview to a laptop while the integrator sets aim.

### Rationale
ADR-001's spirit was to avoid stacked compute (Pi 5 HAT). A passive sensor daughterboard with no active electronics beyond the Lepton socket and decoupling is not the failure class ADR-001 was guarding against. The daughterboard inherits the 30-yr robustness of the main carrier (same conformal coat, same enclosure, same potting) and adds no compute.

### Alternatives Considered
| Option | Tradeoff |
|---|---|
| Lens out the side via vertical PCB | CM4 + cellular re-layout, vibration cantilever, antenna re-route. Overkill for an optical aim problem. |
| 45° gold folding mirror inside enclosure | Field-degradation: dust, condensation, ice, biofilm. Mirror-axis drift over 30 yrs. |
| Right-angle Lepton breakout (commercial) | Locks us to a specific vendor SKU with EOL risk; still needs a daughterboard or adapter. |
| GroupGets Lepton breakout as the daughterboard | Pre-designed, but vendor EOL risk over 30 yrs and no native FFC connection — adapter board still needed. |

### Consequences
- Two PCBs in the project: `cad/dlr_carrier.*` (main) and `cad/lepton_daughter/*` (new). Two KiCad projects, two BOM/CPL files, two Gerber sets to fab; ~+$15 marginal fab cost per unit at low volume.
- J8 footprint on main PCB changes from a 14-pin 2.54 mm THT header to a Hirose FH12-14S-0.5SH FFC connector. Pin map preserves the GroupGets 14-pin Lepton breakout signal order so the schematic on the daughterboard is reusable.
- Aim is set once at integration with lockwasher + Loctite 243; no field-accessible knob (an external knob would be an IP55 / O-ring / corrosion-over-30-yrs liability).
- Sealed industrial USB-C commissioning port (J12) is mandatory — without it the integrator can't see the live thermal frame to set aim.
- ADR-001 retains force for compute and the bulk of sensor / power circuitry; ADR-013 is a scoped exception covering only the Lepton optical chain.

---

## ADR-014: 5V Buck Inductor — Bourns SRN8040TA-100M

**Status:** Accepted **Date:** 2026-09-08 **Amends:** ADR-007 (passive selection only)

### Context
The LMR33630 datasheet (SNVSAN3F §9.2.2.4) requires the inductor saturation current to be no less than the low-side current limit I_LIMIT (4.1 A max over temperature) and ideally at least the high-side limit I_SC (5.05 A max). theory.ipynb §7 checked the placed Bourns SRN8040-100M against those numbers: Isat 3.4 A, and the peak inductor current at the rated 3 A load is already 3.41 A at V_BAT_MAX. The core saturates before the regulator can limit current.

### Decision
Bourns SRN8040TA-100M: 10 µH ±20 %, Isat 5.0 A, Irms 4.6 A, DCR 33 mΩ, AEC-Q200, same 8 × 8 × 4 mm family; KiCad footprint `Inductor_SMD:L_Bourns_SRN8040TA`.

### Rationale
Same inductance, so the ripple / transient analysis in theory.ipynb §7 is unchanged; lower DCR; Isat clears the hard rule with margin and sits within 1 % of the "ideal" I_SC bound. One footprint swap, no layout topology change.

### Alternatives Considered
| Option | Tradeoff |
|---|---|
| Keep SRN8040-100M | Violates the datasheet rule; saturates at rated load |
| Coilcraft XAL7030-103 / Würth WE-LHMI 10 µH | Higher Isat, but new footprint and vendor; not needed |
| 6.8 µH in the same family | Higher Isat at lower L, but K = 0.44 ripple ratio and a re-run of §7 |

### Consequences
- `sim/constants.py` L_BUCK_* and `sim/test_spice.py::TestInductorRating` encode the rule; the test fails the build if a future BOM change regresses it.
- The 3.92 A coincident boot peak still exceeds the worst-case-silicon I_OUT,max (3.375 A) — that is a load-sequencing requirement on firmware (ADR-017), not an inductor problem.

---

## ADR-015: MPPT Charger Support Network — BQ24650 per SLUSA75B

**Status:** Accepted **Date:** 2026-09-08 **Completes:** ADR-008

### Context
ADR-008 selected the BQ24650, but the netlist stood it up as a generic 16-pin connector symbol on an HVQFN footprint with a bootstrap cap, an inductor and a sense resistor — and nothing else. The BQ24650 is a *controller*, not a converter: it has no internal power FETs. As captured, the part had no switching devices, no feedback divider on VFB, no MPPSET divider, no VCC/VREF/REGN bypass, no bootstrap diode, no TS bias and a floating TERM_EN. It could not have charged a battery, and the pin numbering in the placeholder did not match the real device either.

### Decision
Real `Battery_Management:BQ24650` symbol on the TI VQFN-16 thermal-pad footprint, plus the support network the datasheet requires (`cad/netlist/charger.py`, split out of `power.py`):

| Function | Parts | Datasheet basis |
|---|---|---|
| Power stage | Q1/Q2 DMN4035L-7 (40 V, 4.6 A, SOT-23) | §9.2.2.4 — ≥40 V for a 20–28 V input |
| Bootstrap | C2 100 nF PH→BTST, D4 BAT54W REGN→BTST | pin table, REGN / BTST |
| Charge voltage | R20 297k / R21 49.9k (0.1%) → 14.60 V | Eq 1, V_FB = 2.1 V |
| MPPT set point | R18 130k / R19 10k → 16.8 V (~80% Voc) | Eq 2, V_MPPSET = 1.2 V |
| Charge current | R1 20 mΩ → 2 A; I_PRE = I_TERM = 0.2 A | Eq 3/4/5, 40 mV full-scale |
| Bias / bypass | R17 10 Ω + C31 on VCC, C32 VREF, C33 REGN | pin table |
| TS window | R22 10k / R23 15k from VREF → 0.60·VREF | §7.5 thresholds (V_HTF 47.5%, V_LTF 73.5%) |
| Termination | TERM_EN tied to VREF | pin table — must not float |
| Telemetry | STAT1/STAT2 → 10k pull-ups → CM4 GPIO18 / GPIO7 | §8.3.20 open-drain outputs |
| Output filter | L1 6.8 µH SRN8040TA (Isat 5.6 A) + C3 22 µF | Eq 12/13; §9.2.2.3 wants the LC pole in 12–17 kHz — 6.8 µH / 22 µF = 13.1 kHz |

### Rationale
Every one of these is load-bearing per the datasheet; none is decoration. The 0.1% divider on VFB is the one deliberate upgrade over the datasheet example: a 1% pair puts the LiFePO4 top-of-charge at ±150 mV, and over-voltage on LiFePO4 is a cell-life problem, not a rounding error.

### Alternatives Considered
| Option | Tradeoff |
|---|---|
| Keep the placeholder | Non-functional; hides the missing FETs behind a plausible-looking netlist |
| Integrated-FET charger (e.g. BQ25703) | No external FETs, but I²C-configured and 2× the pin count for no gain here |
| AO3400A (30 V) for Q1/Q2 | Cheaper and in the KiCad library, but under-rated for a 21 V Voc panel |

### Consequences
- Charger moves to its own SKiDL module and its own schematic sheet (`SOLAR MPPT CHARGER`).
- KiCad has no symbol for the DMN4035L-7; the generic `Q_NMOS_GSD` symbol carries the MPN as its value, the same convention already used for the BG770A.
- TS is biased mid-window rather than reading a pack thermistor — ADR-009 leaves low-temperature cutoff to the on-pack BMS. If a pack NTC is ever wired to the carrier, R22/R23 become the 103AT divider from the datasheet.

---

## ADR-016: Layer Stack — 4-Layer SIG / GND / 5V / SIG

**Status:** Accepted **Date:** 2026-09-08 **Formalizes:** the 4-layer intent in ADR-001

### Context
ADR-001 and the readme describe a 4-layer 1.6 mm board with an unbroken GND plane under the Lepton SPI and a 90 Ω USB pair referenced to In1 at 0.20 mm (theory.ipynb §5). The board file that was actually routed was 2-layer with F/B ground pours, so those claims were not true of the artifact, and the 0.4 mm-pitch DF40 CM4 connector left 13 nets unrouted.

### Decision
F.Cu signal / In1.Cu full GND plane / In2.Cu full 5V_RAIL plane / B.Cu signal. 1.6 mm FR4, controlled-impedance order with 0.20 mm F.Cu→In1 prepreg. VBAT, 3V3 and the other supply nets are 0.6 mm traces on the outer layers (`power` net class). `cad/drawing/board_setup.py` applies the stack, rules and planes programmatically so every regeneration produces the same board.

### Rationale
A solid GND plane is what the SPI / USB / RF analyses assume; a 5 V plane makes the highest-current, most-distributed rail (CM4, both LDOs, Lepton) a via-drop instead of a routed trace, and lets Freerouting escape the DF40 with vias to planes rather than traces between 0.4 mm pads.

### Alternatives Considered
| Option | Tradeoff |
|---|---|
| 2-layer with pours | Cheapest fab, but the readme's impedance and plane claims are false and the DF40 does not fully route |
| 4-layer GND / GND | Better for signal integrity, but 5 V distribution reverts to traces at 3–4 A |
| 6-layer | Unnecessary for ~70 parts at this density |

### Consequences
- Fab: 4-layer order with stack-up specified; ~2× bare-board cost at prototype volume.
- DRC is run with `--refill-zones` so plane fills are part of the check.
- Ground pours on F/B are kept for stitching; islands are pruned by KiCad's island removal.

---

## ADR-017: 5V Rail Load Sequencing — Firmware Constraint

**Status:** Accepted **Date:** 2026-09-08

### Context
theory.ipynb §7 and `sim/test_spice.py` (ngspice, averaged current-mode model of the LMR33630 with SNVSAN3F §7.5 current limits and the placed 470 µF polymer bank) show that the readme's coincident 3.92 A peak — CM4 boot + Lepton shutter + modem TX — exceeds the regulator's worst-case I_OUT,max of 3.375 A. The rail falls to ≈ 3.86 V and sits under the CM4's 4.75 V floor (CM4 datasheet §5.1) for ≈ 0.9 ms of every 1 ms of coincidence. The CM4 boot peak alone (3.0 A) holds ≈ 4.95 V.

### Decision
The hardware guarantees 3.0 A transients on the 5 V rail, not 3.92 A. Firmware in `dlr-rtu-firmware` must (1) keep the BG770A disabled (LP5907 EN, GPIO17) and never trigger a Lepton shutter until CM4 boot is complete, and (2) never schedule a Lepton shutter concurrently with a modem TX burst. Handed off to the embedded engineer (`/tmp/handoff_embedded-engineer_load-sequencing.md`).

### Rationale
More output capacitance cannot fix a sustained deficit — the cap only buys time (≈ 0.2 ms per 250 mV at 0.55 A). A larger regulator (4 A-class) or a second stage would add cost and board area for a peak that is entirely avoidable in software.

### Alternatives Considered
| Option | Tradeoff |
|---|---|
| 4 A-class buck (e.g. LMR36540 / TPS5450) | Solves it in hardware; larger inductor, respin of the power block, more idle loss |
| Second bulk stage (≥ 2 mF) | Only stretches the brown-out to ~2 ms; still fails a 5 ms coincidence |
| Reduce Lepton shutter current | Not controllable — FLIR module behaviour |

### Consequences
- The readme power-budget table's "Peak" column is a worst-case sum, not a supported operating point; annotated accordingly.
- The LMR33630 internal loop crossover with ~9× the recommended C_out is unpublished; bench Bode / load-step test before production is a hard requirement (SNVSAN3F §9.2.2.5).

---

## ADR-018: Finish the Routing in Code, Not in pcbnew

**Status:** Accepted **Date:** 2026-09-09

### Context
Freerouting routes ~99% of this board and `close_gaps` closes most of the remainder, but a handful of connections always survive both. Every one of them is the same shape: a pin on a 0.4 mm-pitch DF40 or a 0.5 mm-pitch VQFN/MSOP whose only exit is straight out of its own pad, past a neighbour's 0.6 mm escape via or a 0.6 mm power trace. `close_gaps` can only draw L-shapes, so it cannot express the path even when one exists; and where no path exists, the fix is to move the neighbour, which no amount of searching will do.

Hand-routing those in pcbnew works — the interactive router shoves neighbours out of the way — but it is a GUI step, and the pipeline's whole claim is that the board is regenerated from the netlist with no GUI step. A board finished by hand cannot be rebuilt after a schematic change.

### Decision
Finish the routing in code, in three layers:

* `maze_field` / `maze_search` / `maze_escape` — a windowed A* over a 0.05 mm grid on F.Cu and B.Cu with via layer changes. Clearance comes from analytic distance fields built from the copper shapes; **only copper of other nets is an obstacle**, so a pin may leave through its own pad. Each route is checked against KiCad's own connectivity and torn out again unless the two islands really joined.
* `escape_pins` — drives that off the DRC report, widest trace first (0.25 mm, then 0.2 mm).
* `rip_up` / `rip_targets` — when a pin is boxed in, delete the blocking net's copper (or the whole fanout corner) within 1.3 mm, re-run the escape router over everything that opened up, and keep the result only if DRC comes out strictly better. Every attempt is rolled back byte for byte otherwise.

### Rationale
The stranded pins are a *placement* problem disguised as a routing problem: a 0.4 mm pad pitch only fits an escape via on every other pin, so the middle pin's via has to sit in a second, deeper row. A grid search finds that automatically once the corner is cleared, because the near via sites are already taken. Encoding that as a rip-and-retry loop with DRC as the accept test means the board is never left worse than it was found, and the whole result is reproducible from `poe layout-asm`.

### Alternatives Considered
| Option | Tradeoff |
|---|---|
| Hand-route in pcbnew (shove mode) | Works, and fast for a human; unreproducible, and the next netlist change loses it |
| Re-run Freerouting with narrower net classes | Would relieve congestion globally, but rips up and re-lays 1000+ good segments to fix 3 connections |
| 0.5 / 0.25 mm signal vias to ease the DF40 fanout | Leaves a 0.125 mm annular ring, under the 0.13 mm rule; tried and reverted (see `board_setup.py`) |
| 6-layer stack | Solves the fanout outright; roughly doubles bare-board cost for a 40-pin connector |

### Consequences
- Escapes past a fine-pitch pad neck down to 0.25 / 0.2 mm, below the `power` net class's 0.6 mm. These are millimetre-scale stubs into a pin, so the current rating of the trunk is unaffected; JLCPCB's standard 4-layer process holds 0.1 mm trace and space, so 0.2 mm is well inside it.
- `rip_up` is slow — it re-runs DRC and the escape router for every candidate — but it only runs when the board is otherwise finished.
- `stitch_planes` gained a duplicate-via guard: it used to build its work list up front, so two pads whose outward step landed on the same point each added a via there, and the drill file carried the hole several times. The guard rejects a near miss as well as an exact hit — two 0.3 mm drills 0.03 mm apart break into each other, which is worse than one hole drilled twice.
- `cad/drawing/fanout.py` assigns the escape vias up front, alternating each pad row between the inter-row gap and the back of the connector so same-side vias land 0.8 mm apart. It places all 39 of J5's escapes cleanly. It has to own its band to do that, though, and on an already-routed board the 223 tracks it clears cost more than `escape_pins` can rebuild — so it belongs before Freerouting, which is where `poe layout-asm` calls it, and that path is not yet run end to end.
- Two router defects surfaced while proving it, both now fixed: `clear_band` tested only endpoints, so a trace *crossing* the band survived and blocked four via sites; and via placement used the net-aware clearance fields, which skip same-net copper on purpose — correct for traces, wrong for drills, and it stacked 14 same-net vias. Holes are now checked without regard to net, in `via_site_is_clear` and in the router's own `hole_field`.
- The tooling took the board from 5 open connections to 2, both of them redundant ground pins on the DF40, with no clearance, short, annular-ring or hole error left. The last two are a **fanout-capacity limit, not a search failure**: a row of 0.6 mm escape vias needs 0.75 mm centre to centre, so a 0.4 mm pad pitch only fits a via on every other pin, and the 0.15 mm slot left between two adjacent vias cannot pass the 0.2 mm trace (plus 0.15 mm clearance either side) that a second, deeper row would need. Via rows have to be assigned before routing, alternating gap-side and outward; a greedy per-pin router always finishes one slot short. Closing it needs a fanout pass, 0.45 / 0.25 mm vias, or six layers — see the board-status section of readme.md.

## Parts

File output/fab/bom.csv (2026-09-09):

Designator | Comment | Footprint | Quantity
C1,C3 | 22uF | Capacitor_SMD:C_1206_3216Metric | 2
C2,C6,C9,C14-C17,C19,C20,C23-C28,C30,C34,C35 | 100nF | Capacitor_SMD:C_0402_1005Metric | 18
C4 | 10uF | Capacitor_SMD:C_1206_3216Metric | 1
C5 | 220nF | Capacitor_SMD:C_0402_1005Metric | 1
C7 | 470uF | Capacitor_SMD:CP_Elec_8x10 | 1
C8 | 22uF | Capacitor_SMD:C_0805_2012Metric | 1
C10-C13,C31-C33,C36 | 1uF | Capacitor_SMD:C_0402_1005Metric | 8
C18 | 4.7uF | Capacitor_SMD:C_0402_1005Metric | 1
C21,C22 | DNP | Capacitor_SMD:C_0402_1005Metric | 2
C29 | 10nF | Capacitor_SMD:C_0402_1005Metric | 1
D1 | SS34 | Diode_SMD:D_SMA | 1
D2 | SM712-like | Package_TO_SOT_SMD:SOT-23 | 1
D3 | SMBJ24CA | Diode_SMD:D_SMB | 1
D4 | BAT54W | Package_TO_SOT_SMD:SOT-323_SC-70 | 1
F1 | 250mA | Resistor_SMD:R_1206_3216Metric | 1
J1 | PV_IN | TerminalBlock_Phoenix:TerminalBlock_Phoenix_MKDS-1,5-2-5.08_1x02_P5.08mm_Horizontal | 1
J3 | BAT | TerminalBlock_Phoenix:TerminalBlock_Phoenix_MKDS-1,5-2-5.08_1x02_P5.08mm_Horizontal | 1
J5 | CM4_J2 | Connector_Hirose_DF40:Hirose_DF40HC(3.0)-40DS-0.4V_2x20_P0.4mm | 1
J6 | U.FL | Connector_Coaxial:U.FL_Hirose_U.FL-R-SMT-1_Vertical | 1
J7 | SIM | Connector_Card:microSIM_JAE_SF53S006VCBR2000 | 1
J8 | FLIR_LEPTON_FFC | Connector_FFC-FPC:Hirose_FH12-14S-0.5SH_1x14-1MP_P0.50mm_Horizontal | 1
J9 | SI1145 | Connector_PinHeader_2.54mm:PinHeader_1x05_P2.54mm_Vertical | 1
J10 | YL-83 | Connector_PinHeader_2.54mm:PinHeader_1x04_P2.54mm_Vertical | 1
J11 | DEBUG_UART | Connector_PinHeader_2.54mm:PinHeader_1x04_P2.54mm_Vertical | 1
J12 | USBC_COMMISSIONING | Connector_USB:USB_C_Receptacle_GCT_USB4085 | 1
J13 | ANEMO_M12_5P | Connector_PinHeader_2.54mm:PinHeader_1x05_P2.54mm_Vertical | 1
L1 | 6.8uH | Inductor_SMD:L_Bourns_SRN8040TA | 1
L2 | 10uH | Inductor_SMD:L_Bourns_SRN8040TA | 1
Q1,Q2 | DMN4035L-7 | Package_TO_SOT_SMD:SOT-23 | 2
R1 | 20m | Resistor_SMD:R_1206_3216Metric | 1
R2,R6 | 100k | Resistor_SMD:R_0402_1005Metric | 2
R3 | 24.9k | Resistor_SMD:R_0402_1005Metric | 1
R5 | 0R | Resistor_SMD:R_0402_1005Metric | 1
R7-R9,R19,R22,R24,R25 | 10k | Resistor_SMD:R_0402_1005Metric | 7
R10,R11 | 2.2k | Resistor_SMD:R_0402_1005Metric | 2
R12,R13 | 5.1k | Resistor_SMD:R_0402_1005Metric | 2
R14 | 120 | Resistor_SMD:R_0402_1005Metric | 1
R15,R16 | 680 | Resistor_SMD:R_0402_1005Metric | 2
R17 | 10 | Resistor_SMD:R_0402_1005Metric | 1
R18 | 130k | Resistor_SMD:R_0402_1005Metric | 1
R20 | 297k | Resistor_SMD:R_0402_1005Metric | 1
R21 | 49.9k | Resistor_SMD:R_0402_1005Metric | 1
R23 | 15k | Resistor_SMD:R_0402_1005Metric | 1
U1 | AP2112K-3.3 | Package_TO_SOT_SMD:SOT-23-5 | 1
U2 | LP5907MFX-3.8 | Package_TO_SOT_SMD:SOT-23-5 | 1
U3 | BG770A-NA | RF_GSM:Quectel_BG95 | 1
U4 | TXS0108E | Package_SO:TSSOP-20_4.4x6.5mm_P0.65mm | 1
U5 | DHT22 | Sensor:Aosong_DHT11_5.5x12.0_P2.54mm | 1
U6 | ADS1115 | Package_SO:MSOP-10_3x3mm_P0.5mm | 1
U7 | SP3485EN | Package_SO:SOIC-8_3.9x4.9mm_P1.27mm | 1
U8 | BQ24650RVAR | Package_DFN_QFN:Texas_RVA_VQFN-16-1EP_3.5x3.5mm_P0.5mm_EP2.14x2.14mm_ThermalVias | 1
U9 | LMR33630ADDA | Package_SO:Texas_HSOP-8-1EP_3.9x4.9mm_P1.27mm_ThermalVias | 1

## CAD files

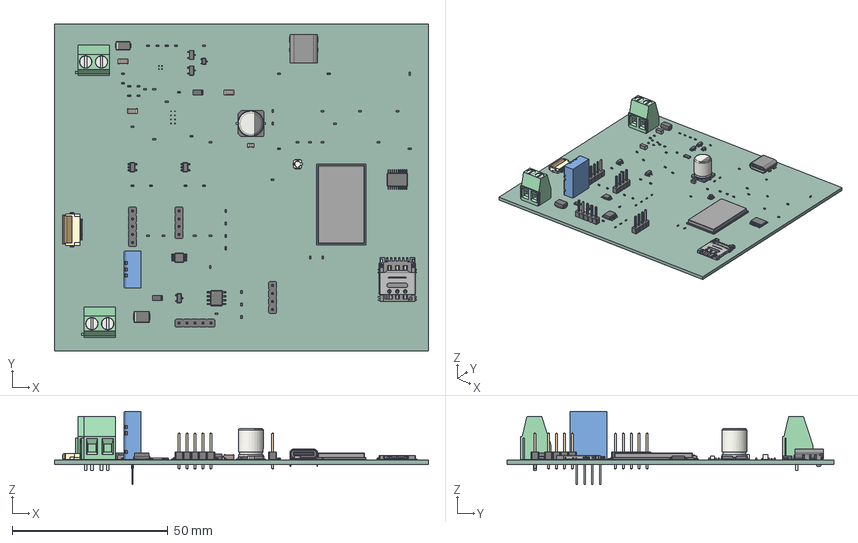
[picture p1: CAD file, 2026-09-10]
output/dlr_carrier_pcb.step
120.0 x 105.0 x 23.5 mm
C_0402_1005Metric x 31
R_0402_1005Metric x 23
C_1206_3216Metric x 3
nanoSIM_Hinged_CUI_NSIM-2-C
U.FL_Hirose_U.FL-R-SMT-1_Vertical
SOT-23-5 x 2
PinHeader_1x04_P254mm_Vertical x 2
lock
pins
SOIC-8_3.9x4.9mm_P1.27mm
C_0805_2012Metric
CP_Elec_8x10
SOT-23 x 3
TSSOP-20_4.4x6.5mm_P0.65mm
TerminalBlock_Phoenix_MKDS-1,5-2-5.08_1x02_P5.08mm_Horizontal x 2
D_SMB
R_1206_3216Metric x 2
D_SMA
USB_C_Receptacle_GCT_USB4085
ublox_SARA_LGA-96
SOT-323_SC-70
PinHeader_1x05_P254mm_Vertical x 2
Aosong_DHT11_5.5x12.0_P2.54mm
MSOP-10_3x3mm_P0.5mm
dlr_carrier_PCB

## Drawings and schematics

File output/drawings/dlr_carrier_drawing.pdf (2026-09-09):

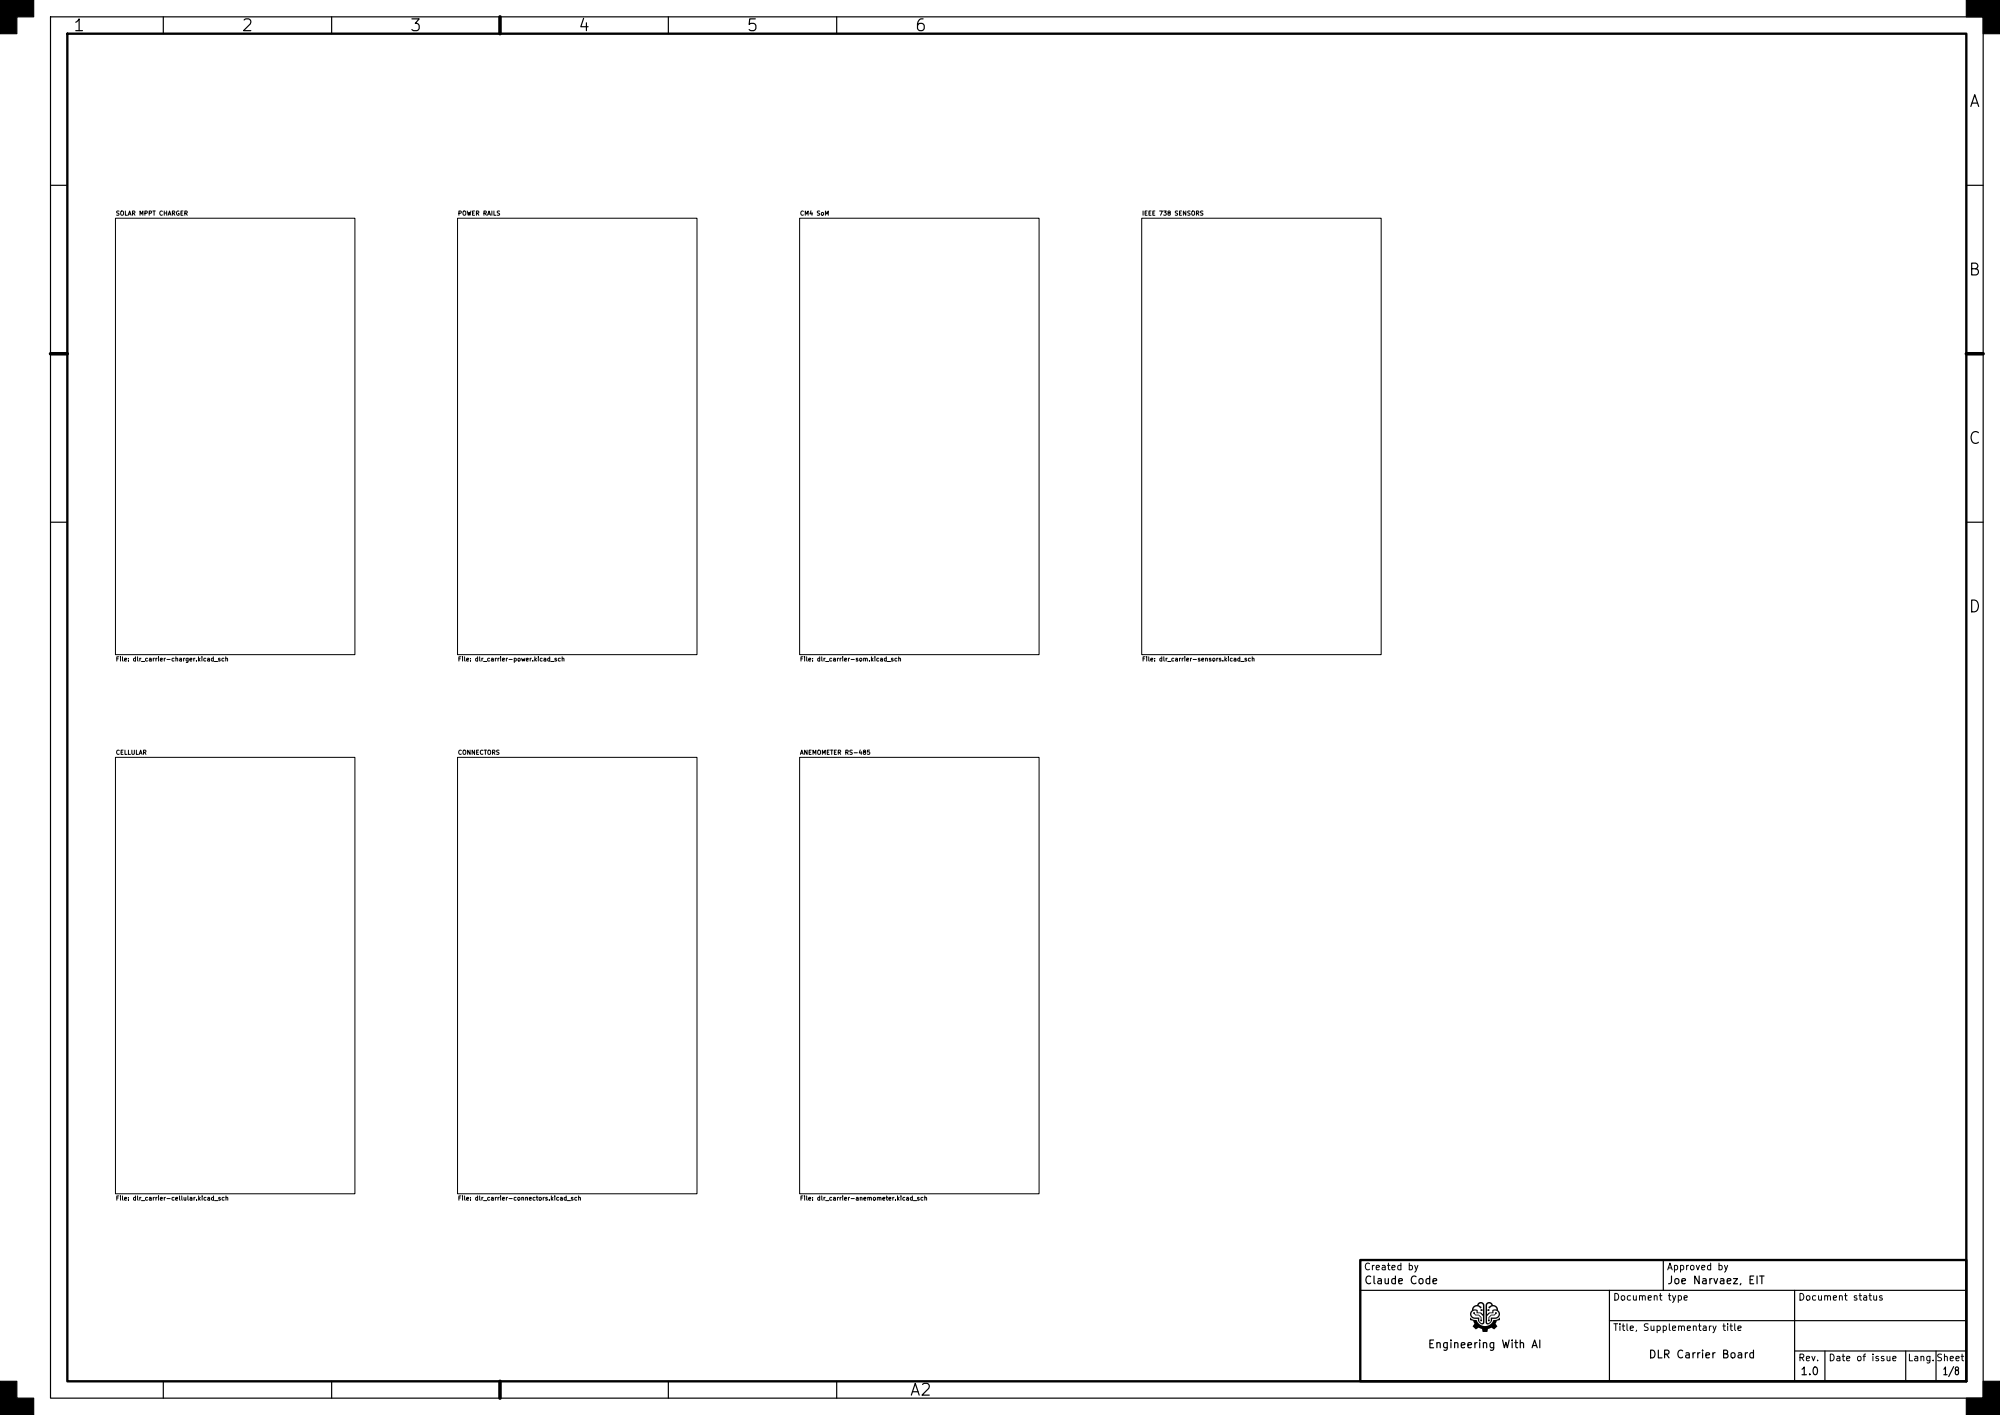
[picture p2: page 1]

Created by Claude Code | Approved by Joe Narvaez, EIT

Engineering With AI | Document type | Document status

Title, Supplementary title DLR Carrier Board

Rev. 1.0 | Date of issue | Lang. Sheet | 1/8

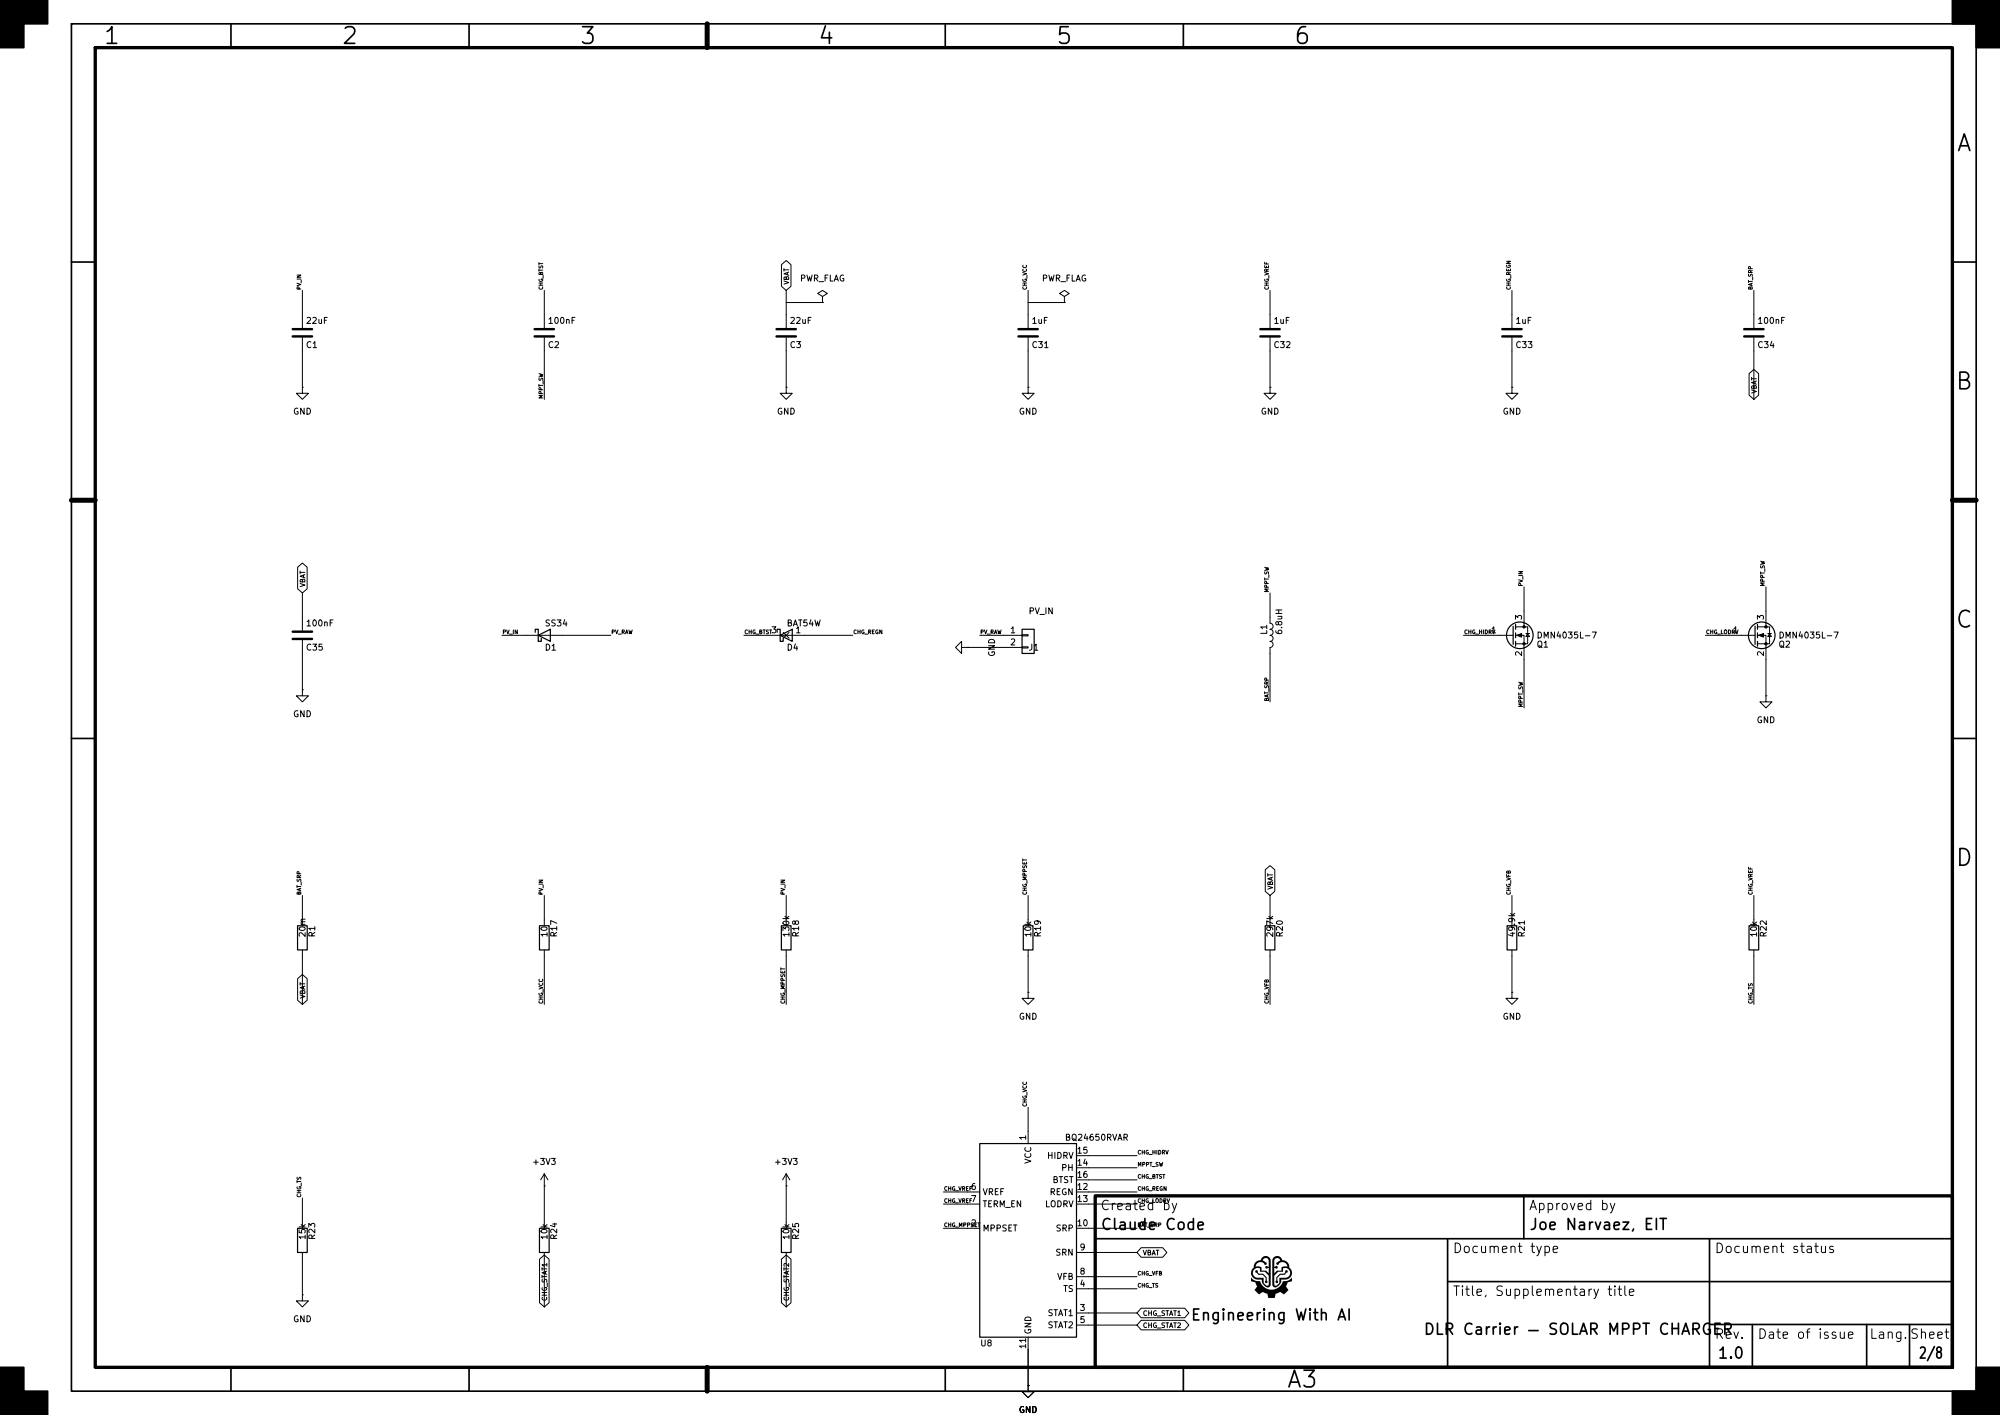
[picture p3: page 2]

Created by Claude Code | Approved by Joe Narvaez, EIT

CHG_STAT2 | Document type | Document status

Title, Supplementary title

DLR Carrier — SOLAR MPPT CHARGER

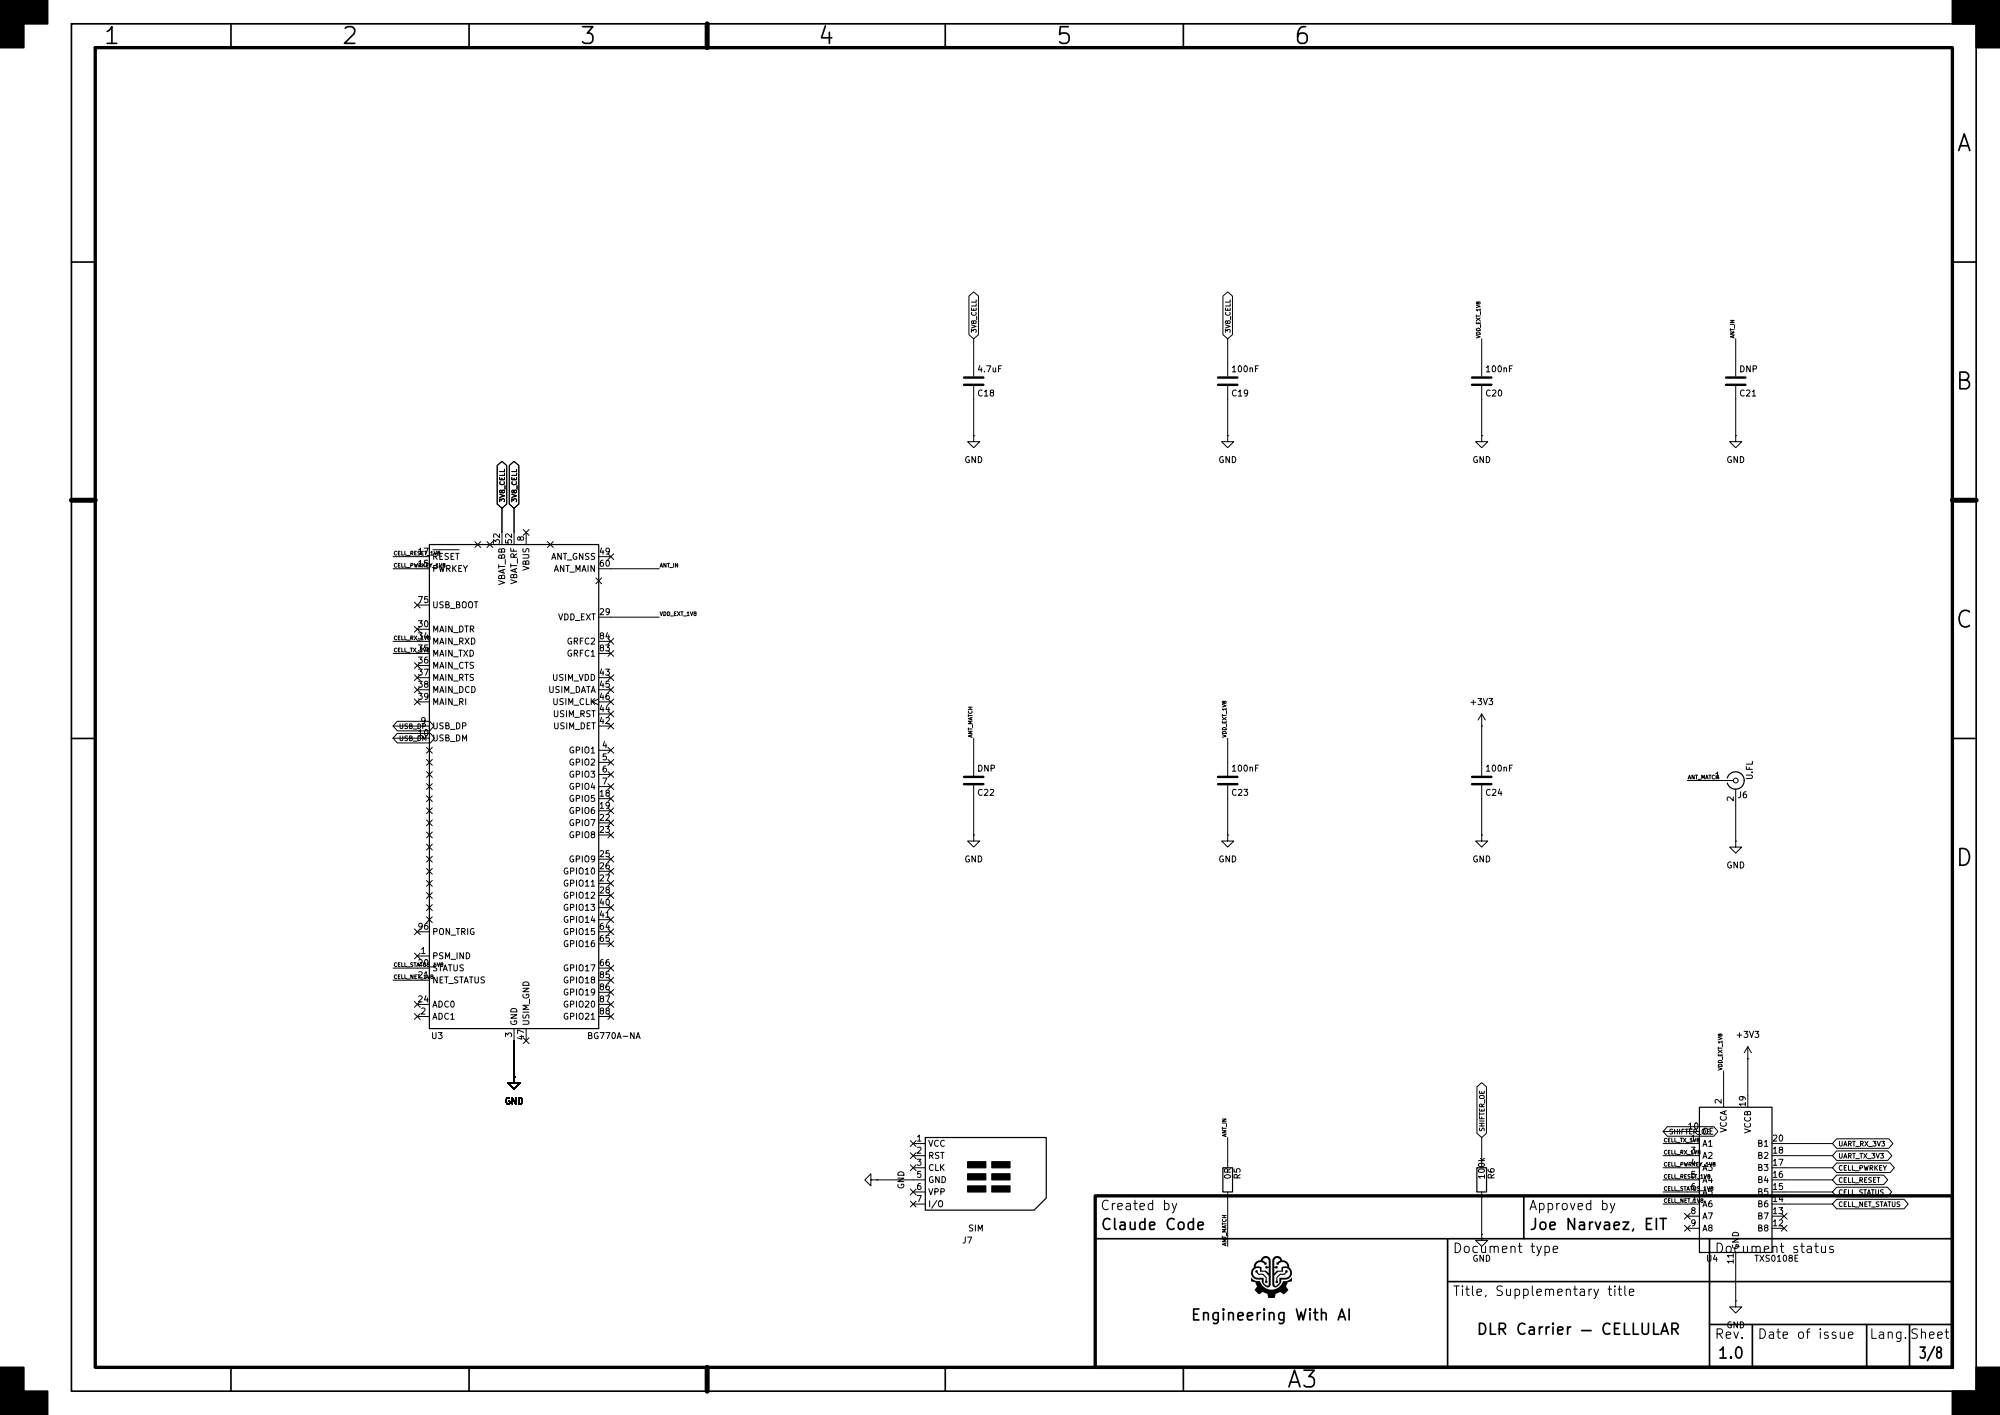
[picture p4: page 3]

VCC 1 RST 2 CLK 3 GND 5

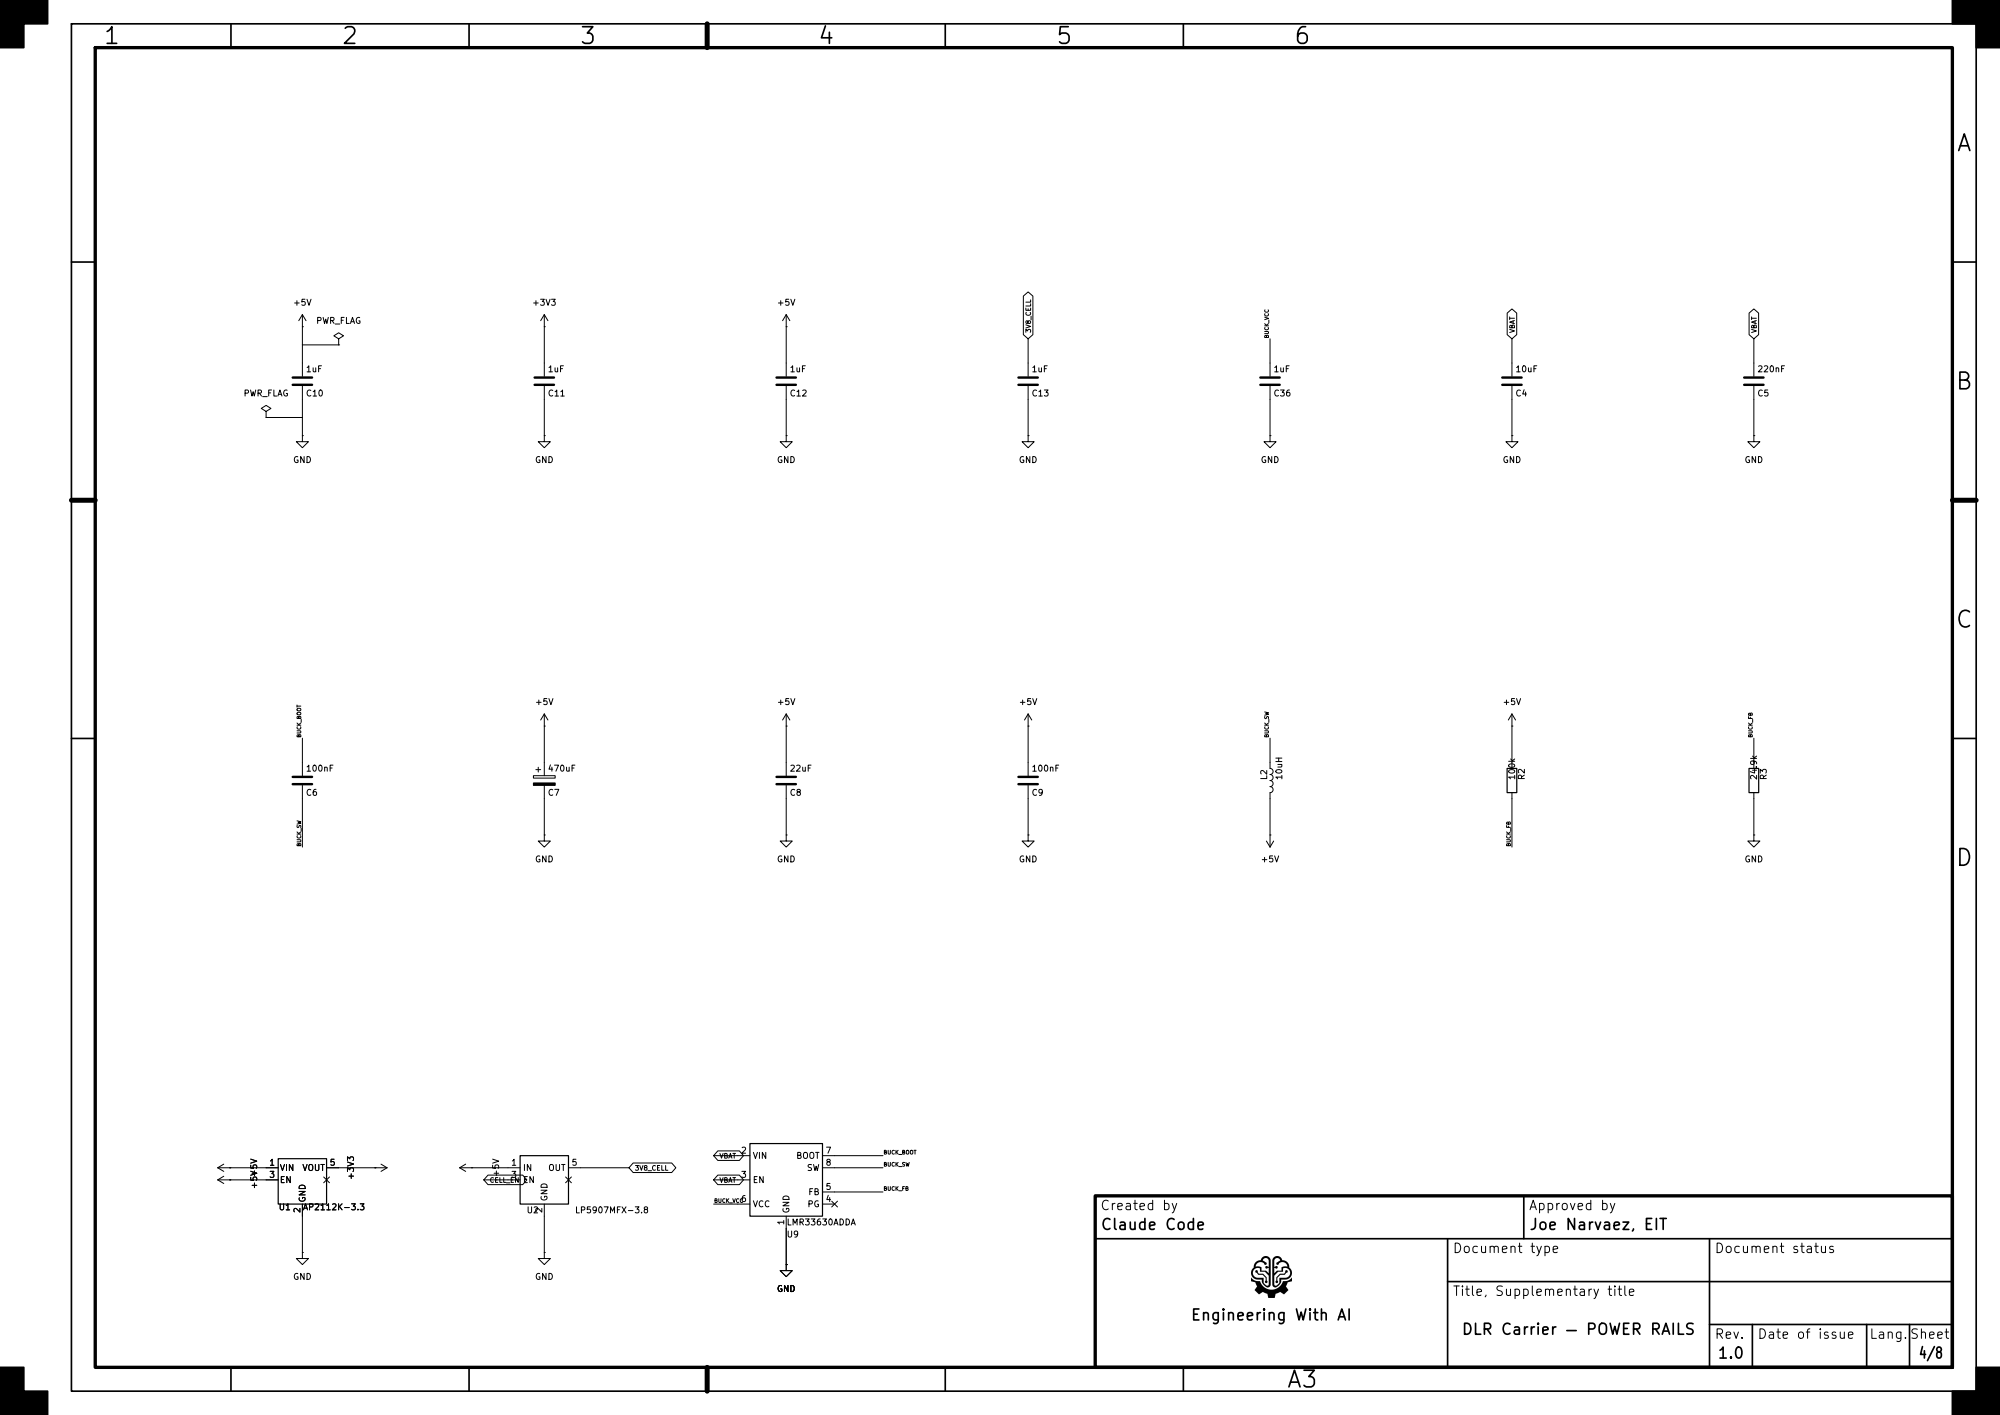
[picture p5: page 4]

Created by Claude Code | Approved by Joe Narvaez, EIT

Document type | Document status

Title, Supplementary title DLR Carrier — POWER RAILS

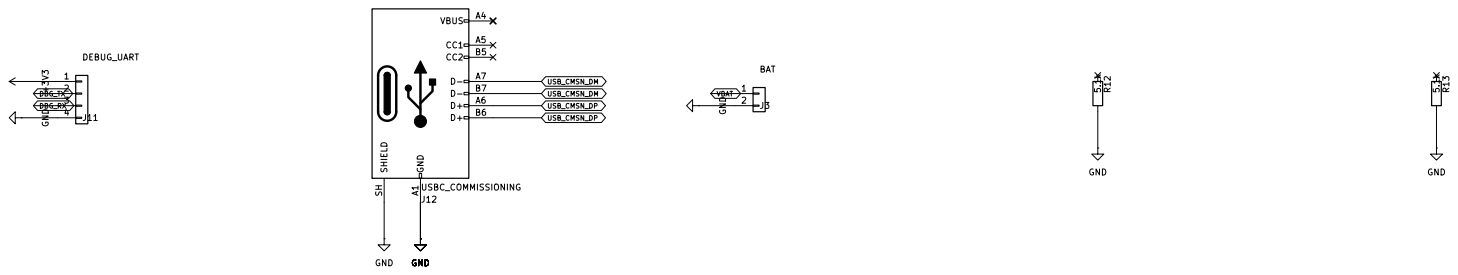
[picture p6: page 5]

Created by Claude Code | Approved by Joe Narvaez, EIT

Document type | Document status

Title, Supplementary title DLR Carrier — CONNECTORS

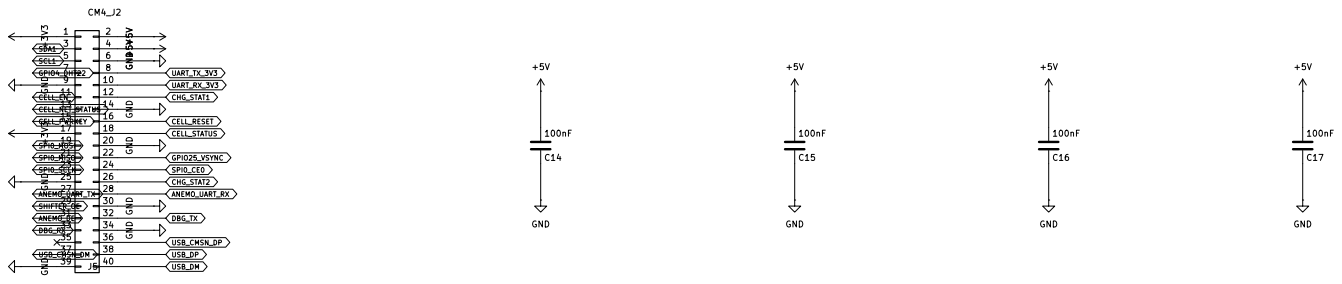
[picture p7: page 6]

Created by Claude Code | Approved by Joe Narvaez, EIT

Document type | Document status

Title, Supplementary title DLR Carrier — CM4 SoM

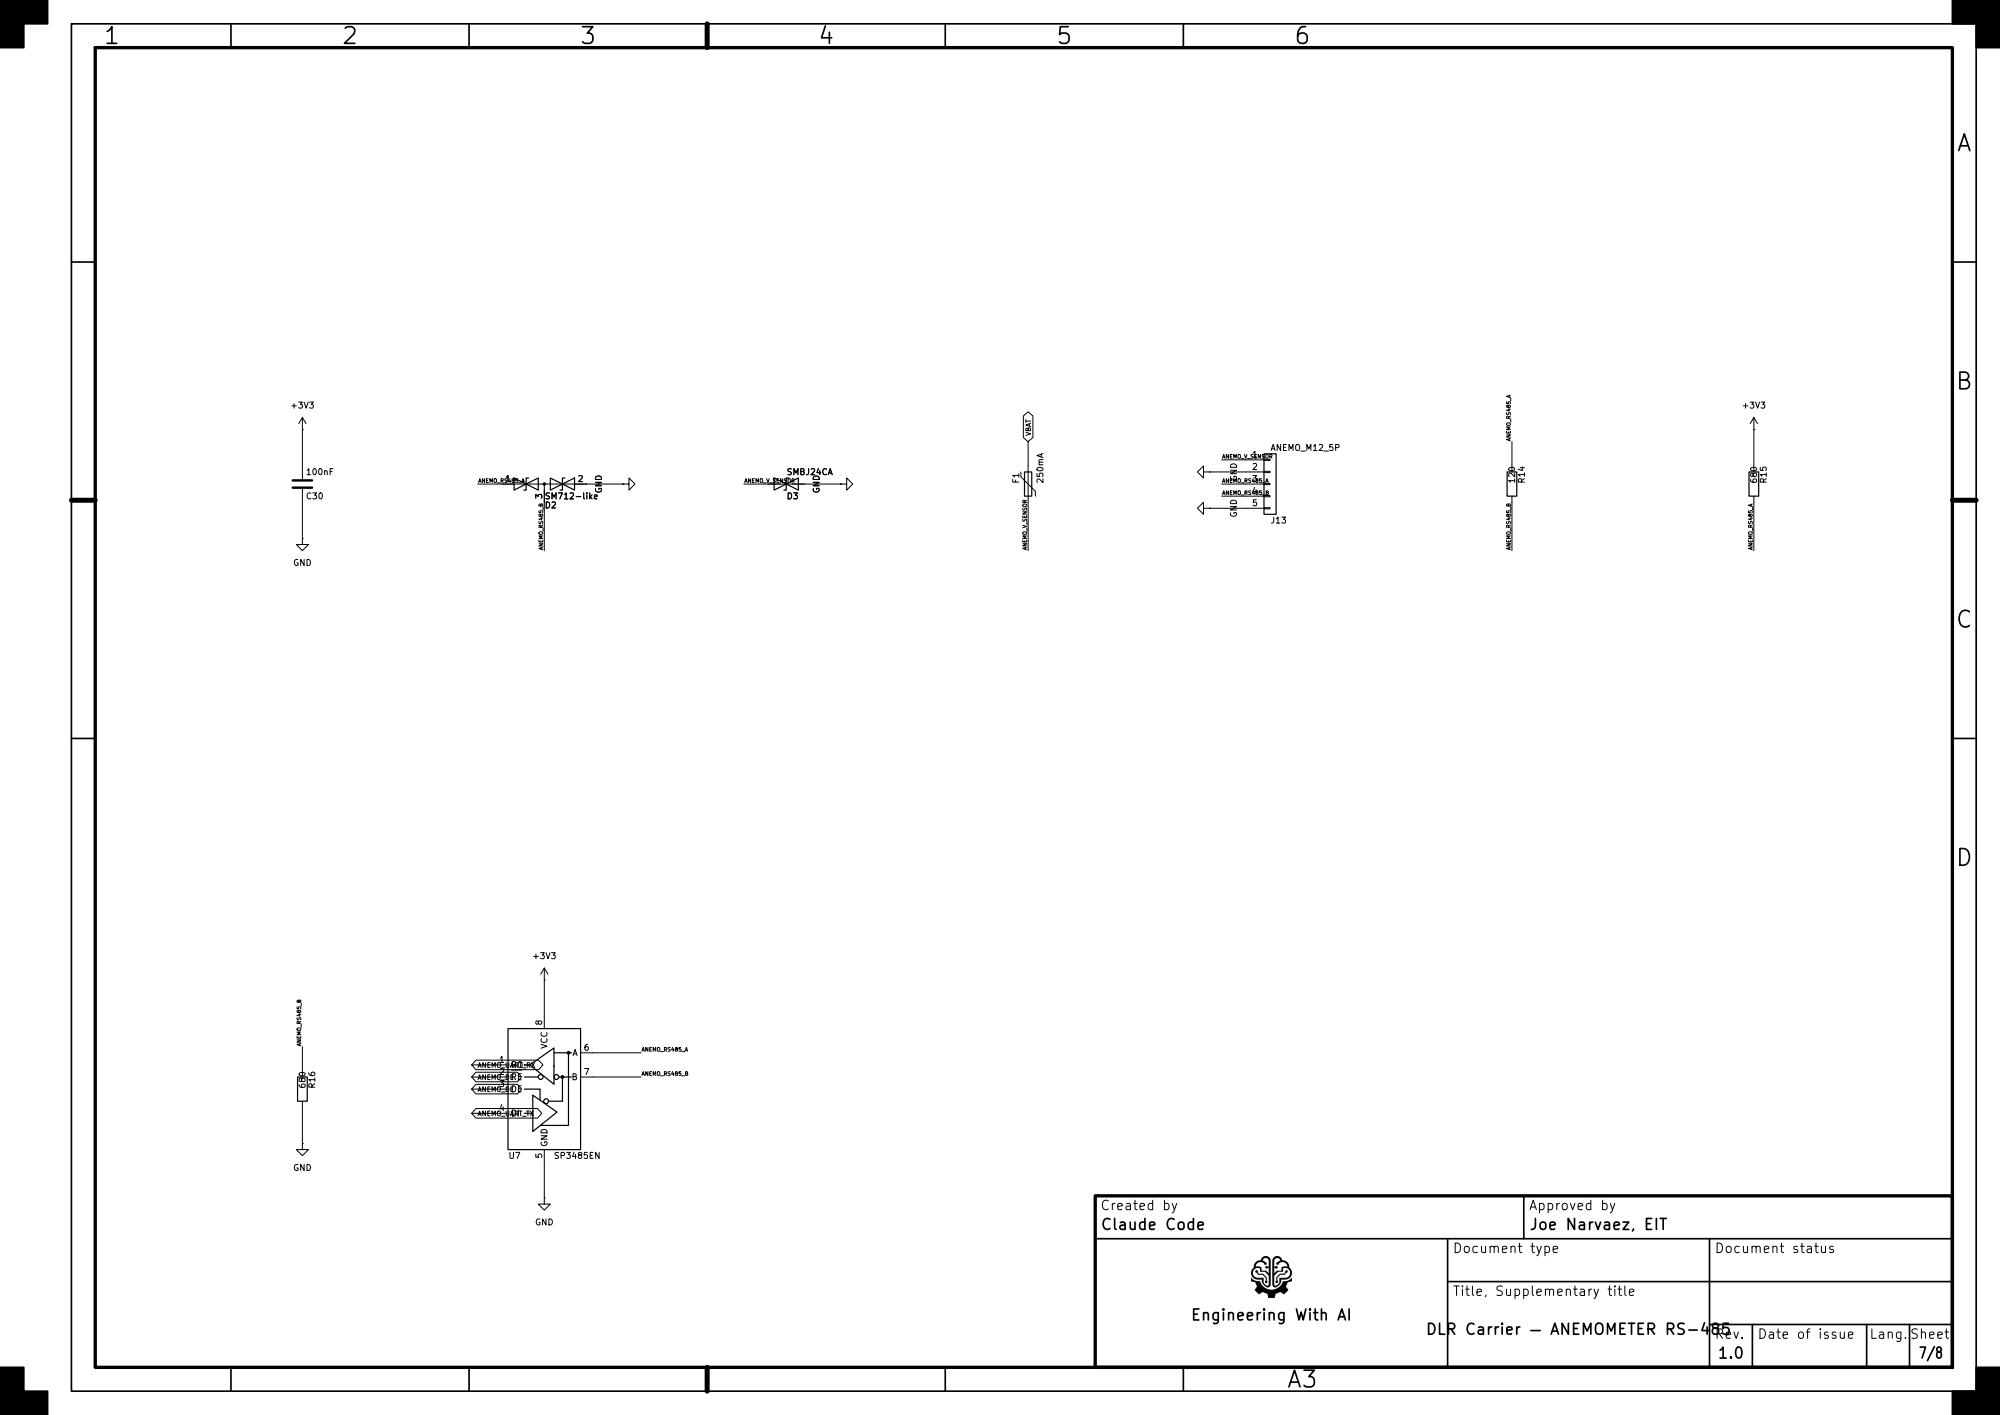
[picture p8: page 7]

Created by Claude Code | Approved by Joe Narvaez, EIT

Document type | Document status

Title, Supplementary title

DLR Carrier — ANEMOMETER RS-485

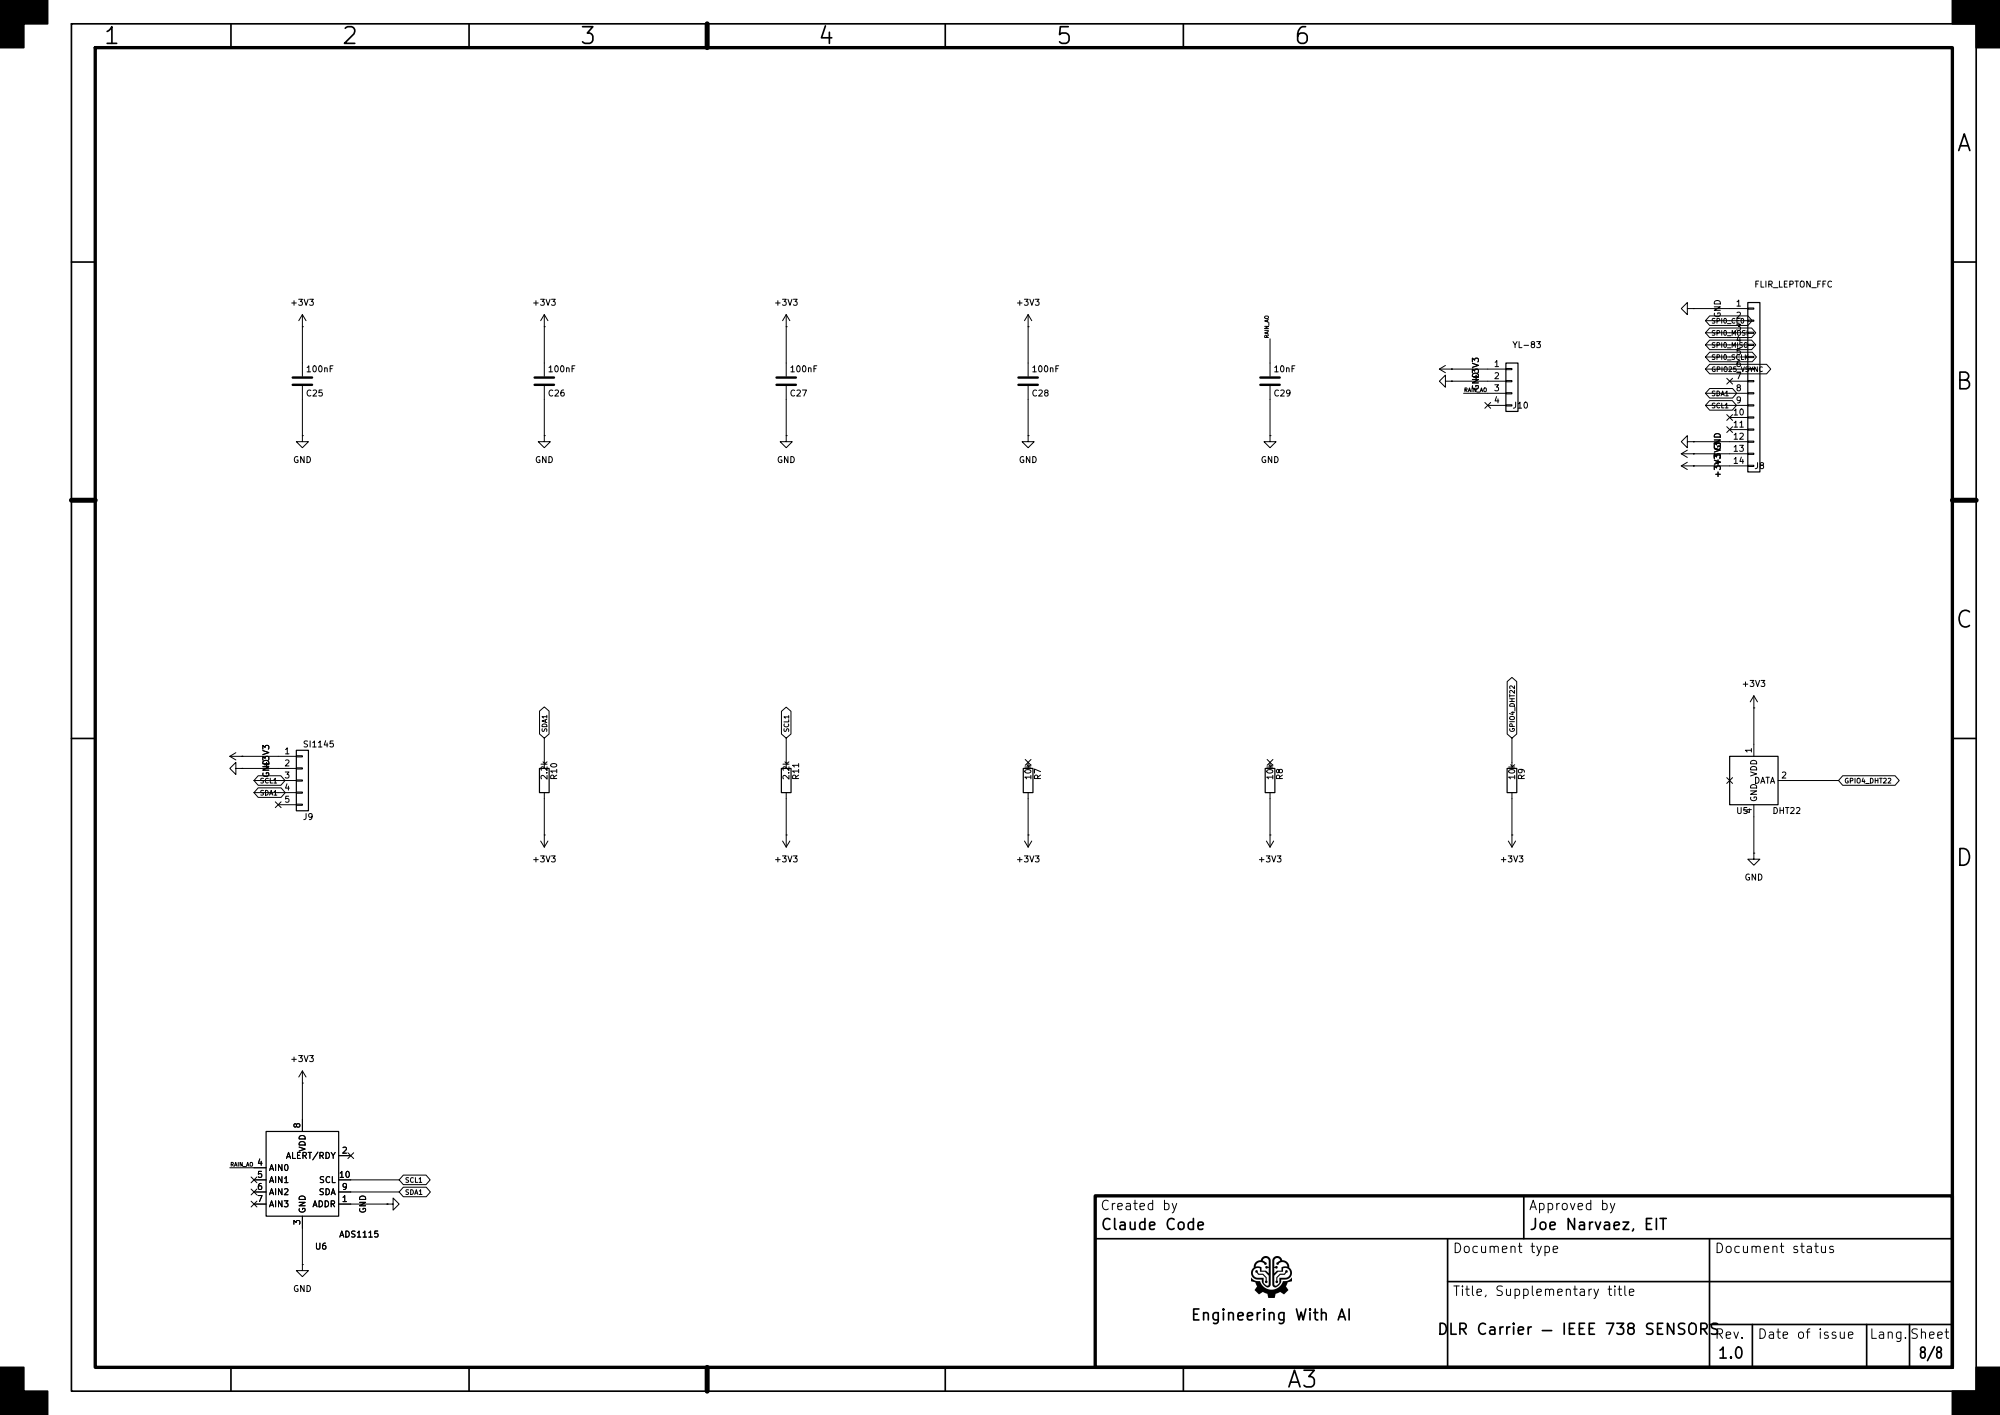
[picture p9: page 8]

Created by Claude Code | Approved by Joe Narvaez, EIT

Document type | Document status

Title, Supplementary title

DLR Carrier — IEEE 738 SENSORS

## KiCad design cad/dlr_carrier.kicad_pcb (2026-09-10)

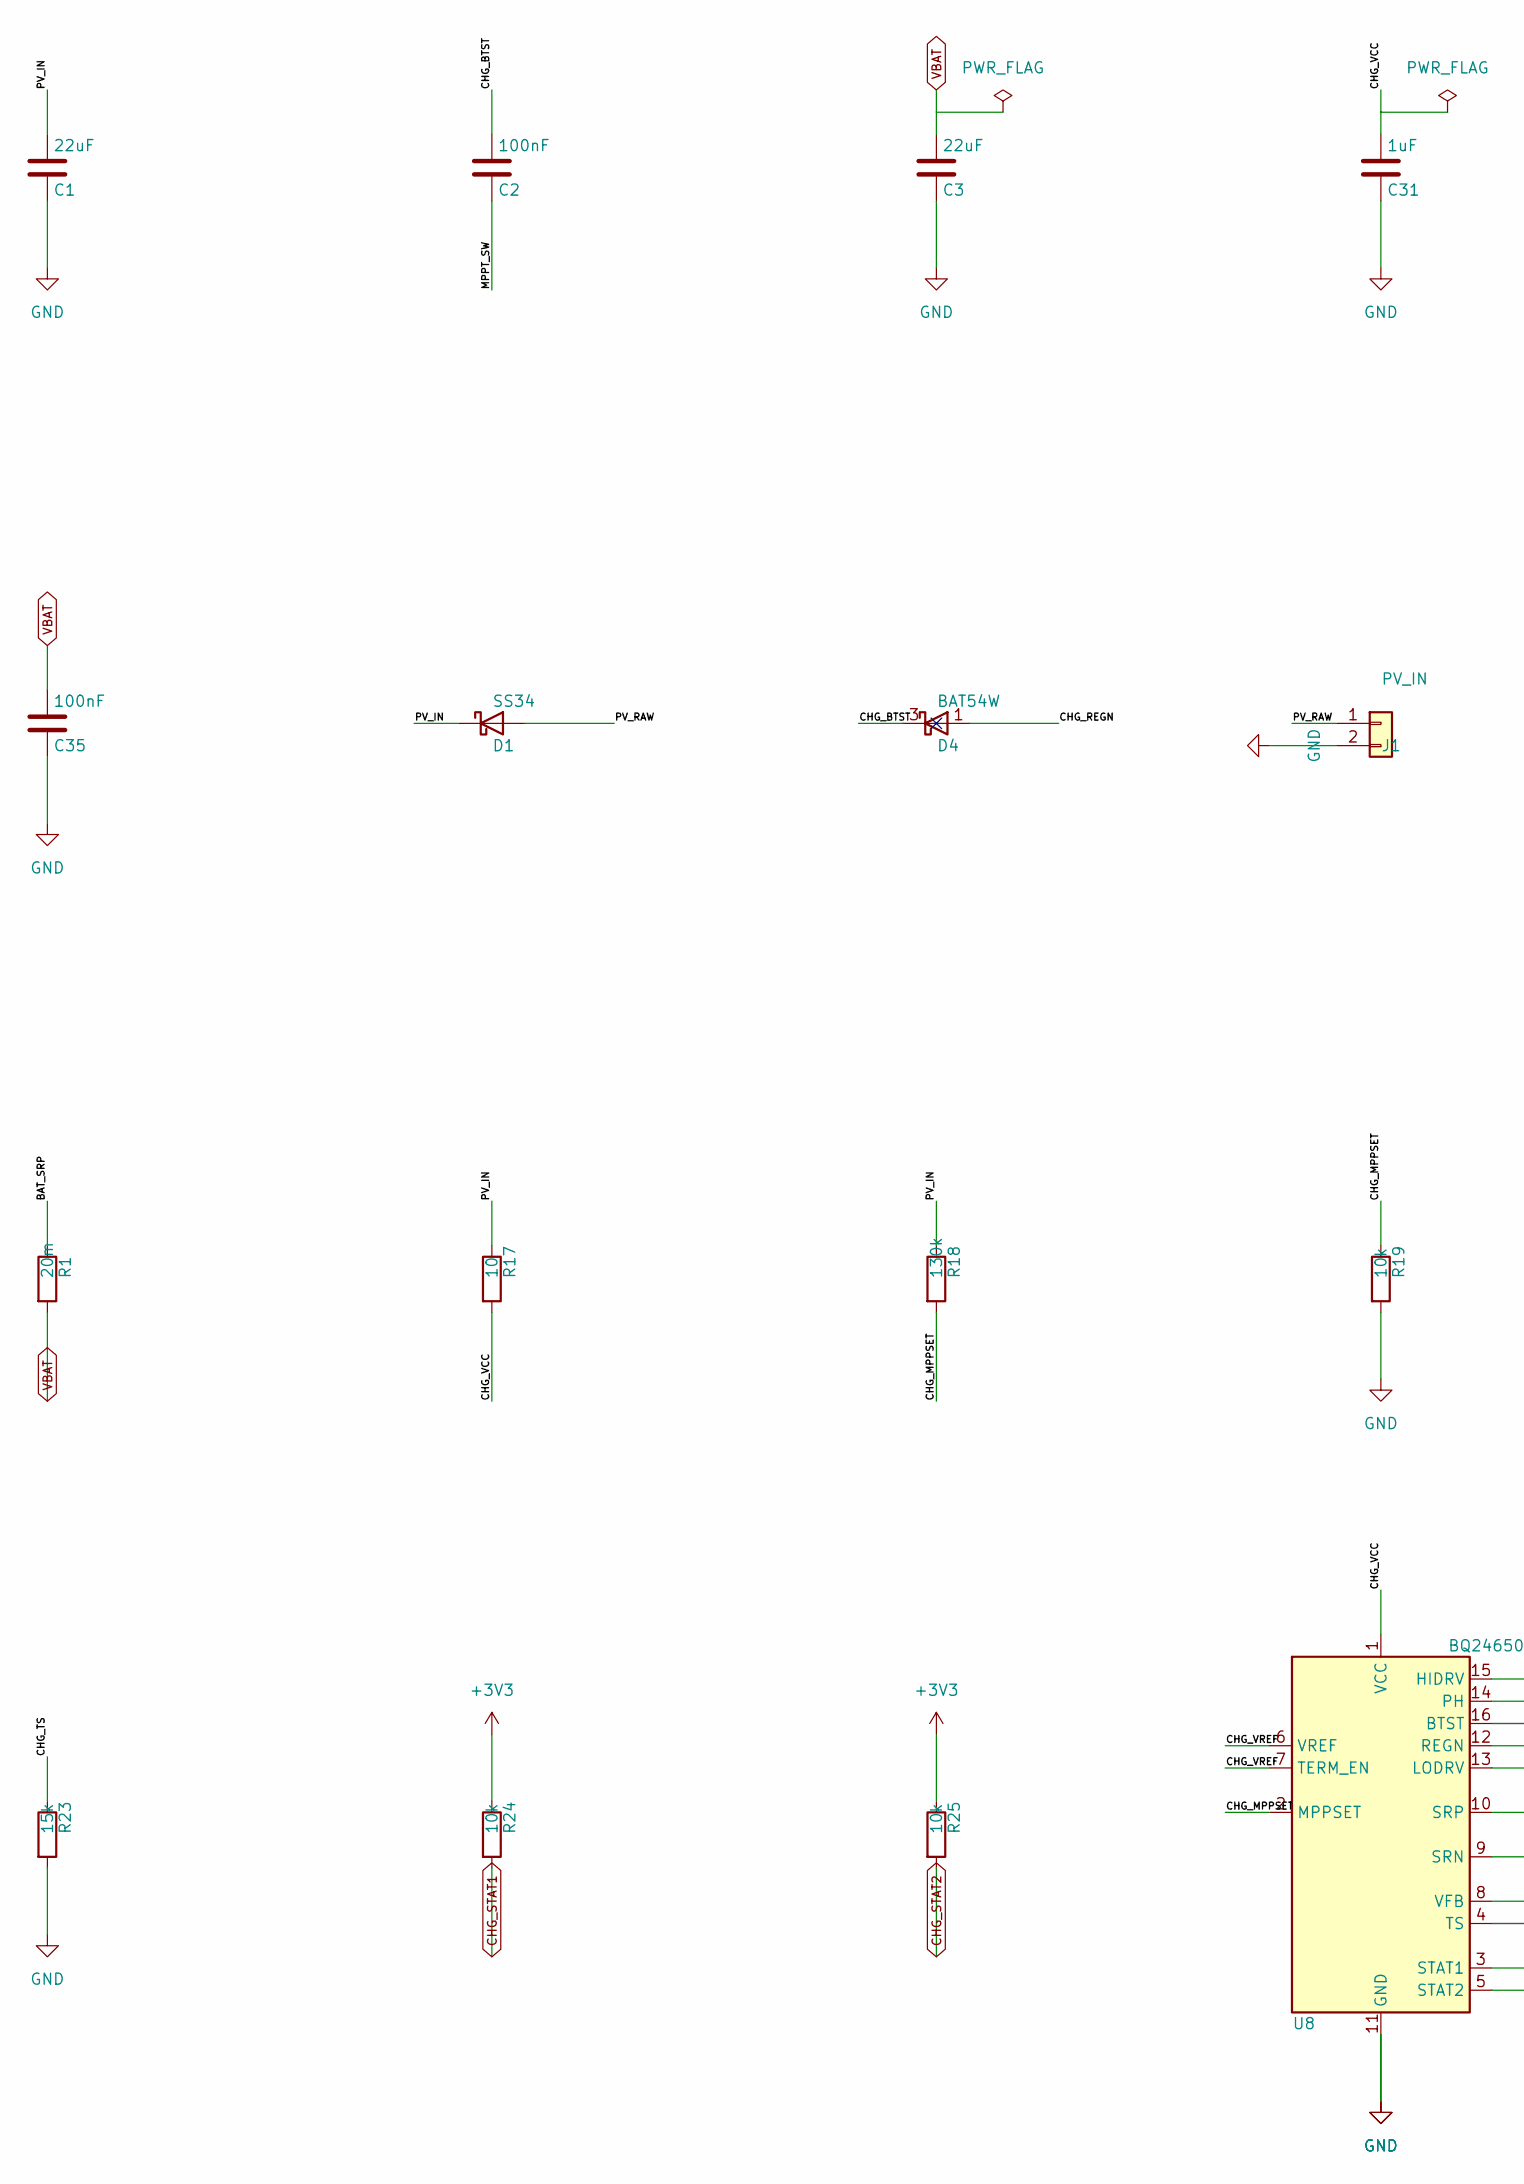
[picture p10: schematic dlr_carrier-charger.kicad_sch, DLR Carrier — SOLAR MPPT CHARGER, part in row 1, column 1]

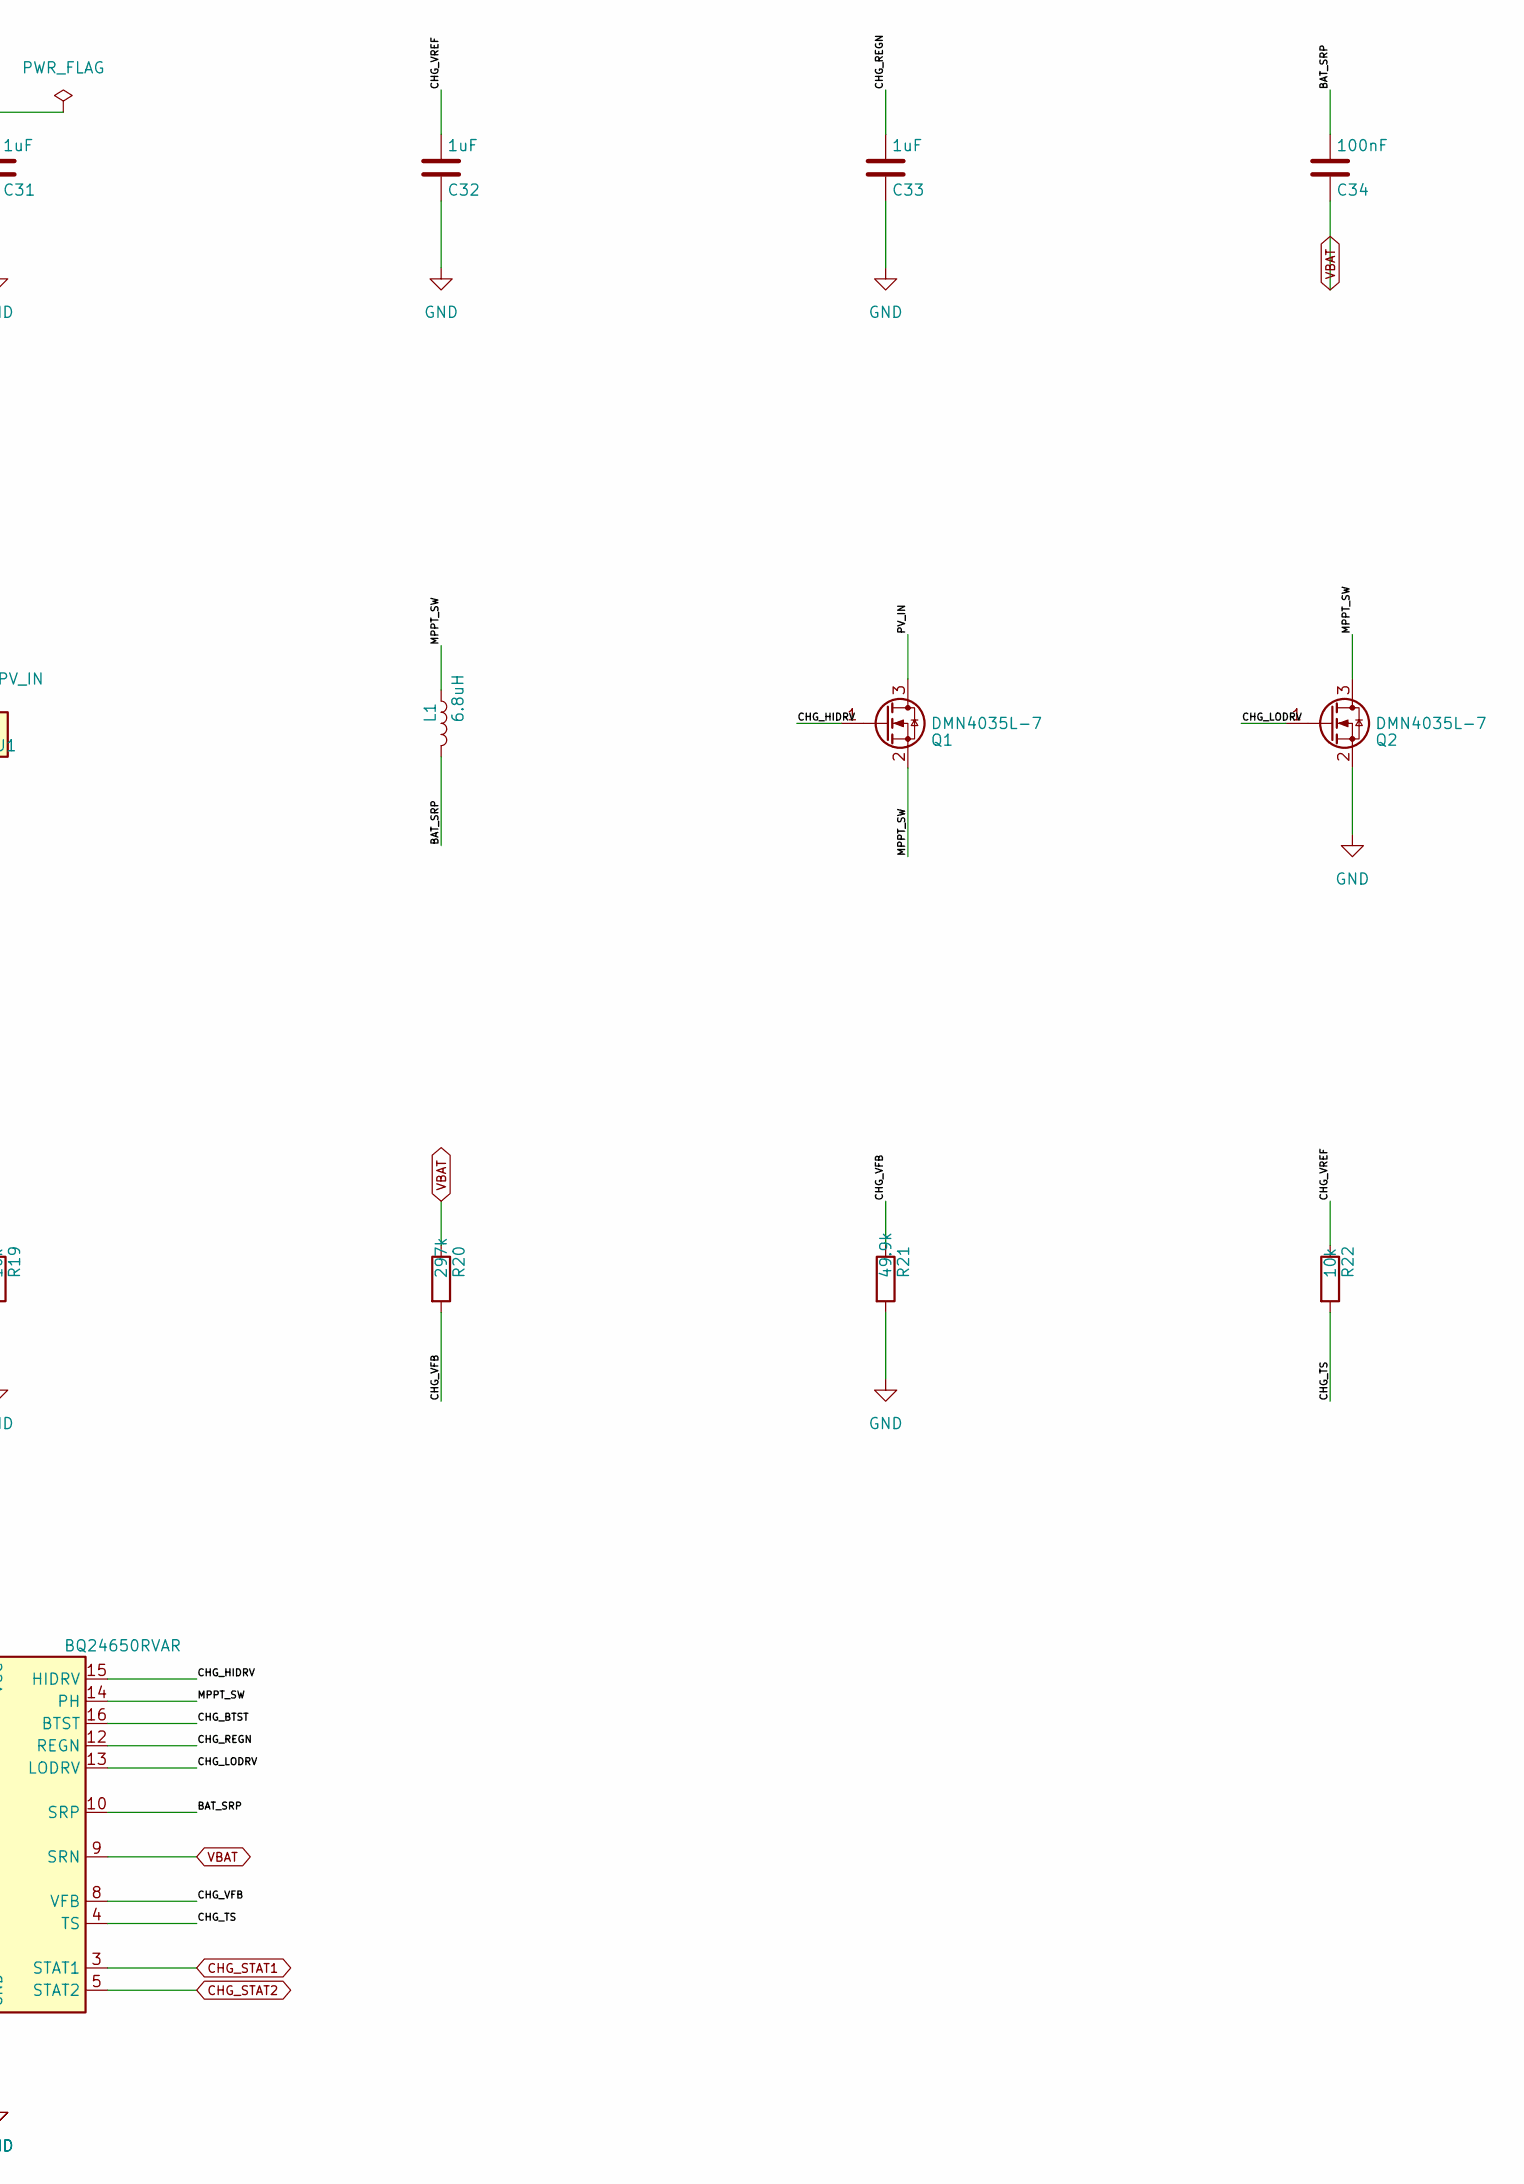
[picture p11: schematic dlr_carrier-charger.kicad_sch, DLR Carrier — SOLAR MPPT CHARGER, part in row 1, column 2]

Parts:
C1, C3: 22uF; C_1206_3216Metric
C2, C34, C35: 100nF; C_0402_1005Metric
C31, C32, C33: 1uF; C_0402_1005Metric
D1: SS34; D_SMA
D4: BAT54W; SOT-323_SC-70
J1: PV_IN; TerminalBlock_Phoenix_MKDS-1,5-2-5.08_1x02_P5.08mm_Horizont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
L1: 6.8uH; L_Bourns_SRN8040TA
Q1, Q2: DMN4035L-7; SOT-23
R1: 20m; R_1206_3216Metric
R17: 10; R_0402_1005Metric
R18: 130k; R_0402_1005Metric
R19, R22, R24, R25: 10k; R_0402_1005Metric
R20: 297k; R_0402_1005Metric
R21: 49.9k; R_0402_1005Metric
R23: 15k; R_0402_1005Metric
U8: BQ24650RVAR; Texas_RVA_VQFN-16-1EP_3.5x3.5mm_P0.5mm_EP2.14x2.14mm_Therma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

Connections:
3V3: R24.1, R25.1; also elsewhere on the board
BAT_SRP: C34.1, L1.2, R1.1, U8.10 (SRP)
CHG_BTST: C2.1, D4.3 (K), U8.16 (BTST)
CHG_HIDRV: Q1.1 (G), U8.15 (HIDRV)
CHG_LODRV: Q2.1 (G), U8.13 (LODRV)
CHG_MPPSET: R18.2, R19.1, U8.2 (MPPSET)
CHG_REGN: C33.1, D4.1 (A), U8.12 (REGN)
CHG_STAT1: R24.2, U8.3 (STAT1); also elsewhere on the board
CHG_STAT2: R25.2, U8.5 (STAT2); also elsewhere on the board
CHG_TS: R22.2, R23.1, U8.4 (TS)
CHG_VCC: C31.1, R17.2, U8.1 (VCC)
CHG_VFB: R20.2, R21.1, U8.8 (VFB)
CHG_VREF: C32.1, R22.1, U8.6 (VREF), U8.7 (TERM_EN)
GND: C1.2, C3.2, C31.2, C32.2, C33.2, C35.2, J1.2, Q2.2 (S), R19.2, R21.2, R23.2, U8.11 (GND), U8.17 (GND); also elsewhere on the board
MPPT_SW: C2.2, L1.1, Q1.2 (S), Q2.3 (D), U8.14 (PH)
PV_IN: C1.1, D1.1 (K), Q1.3 (D), R17.1, R18.1
PV_RAW: D1.2 (A), J1.1
VBAT: C3.1, C34.2, C35.1, R1.2, R20.1, U8.9 (SRN); also elsewhere on the board

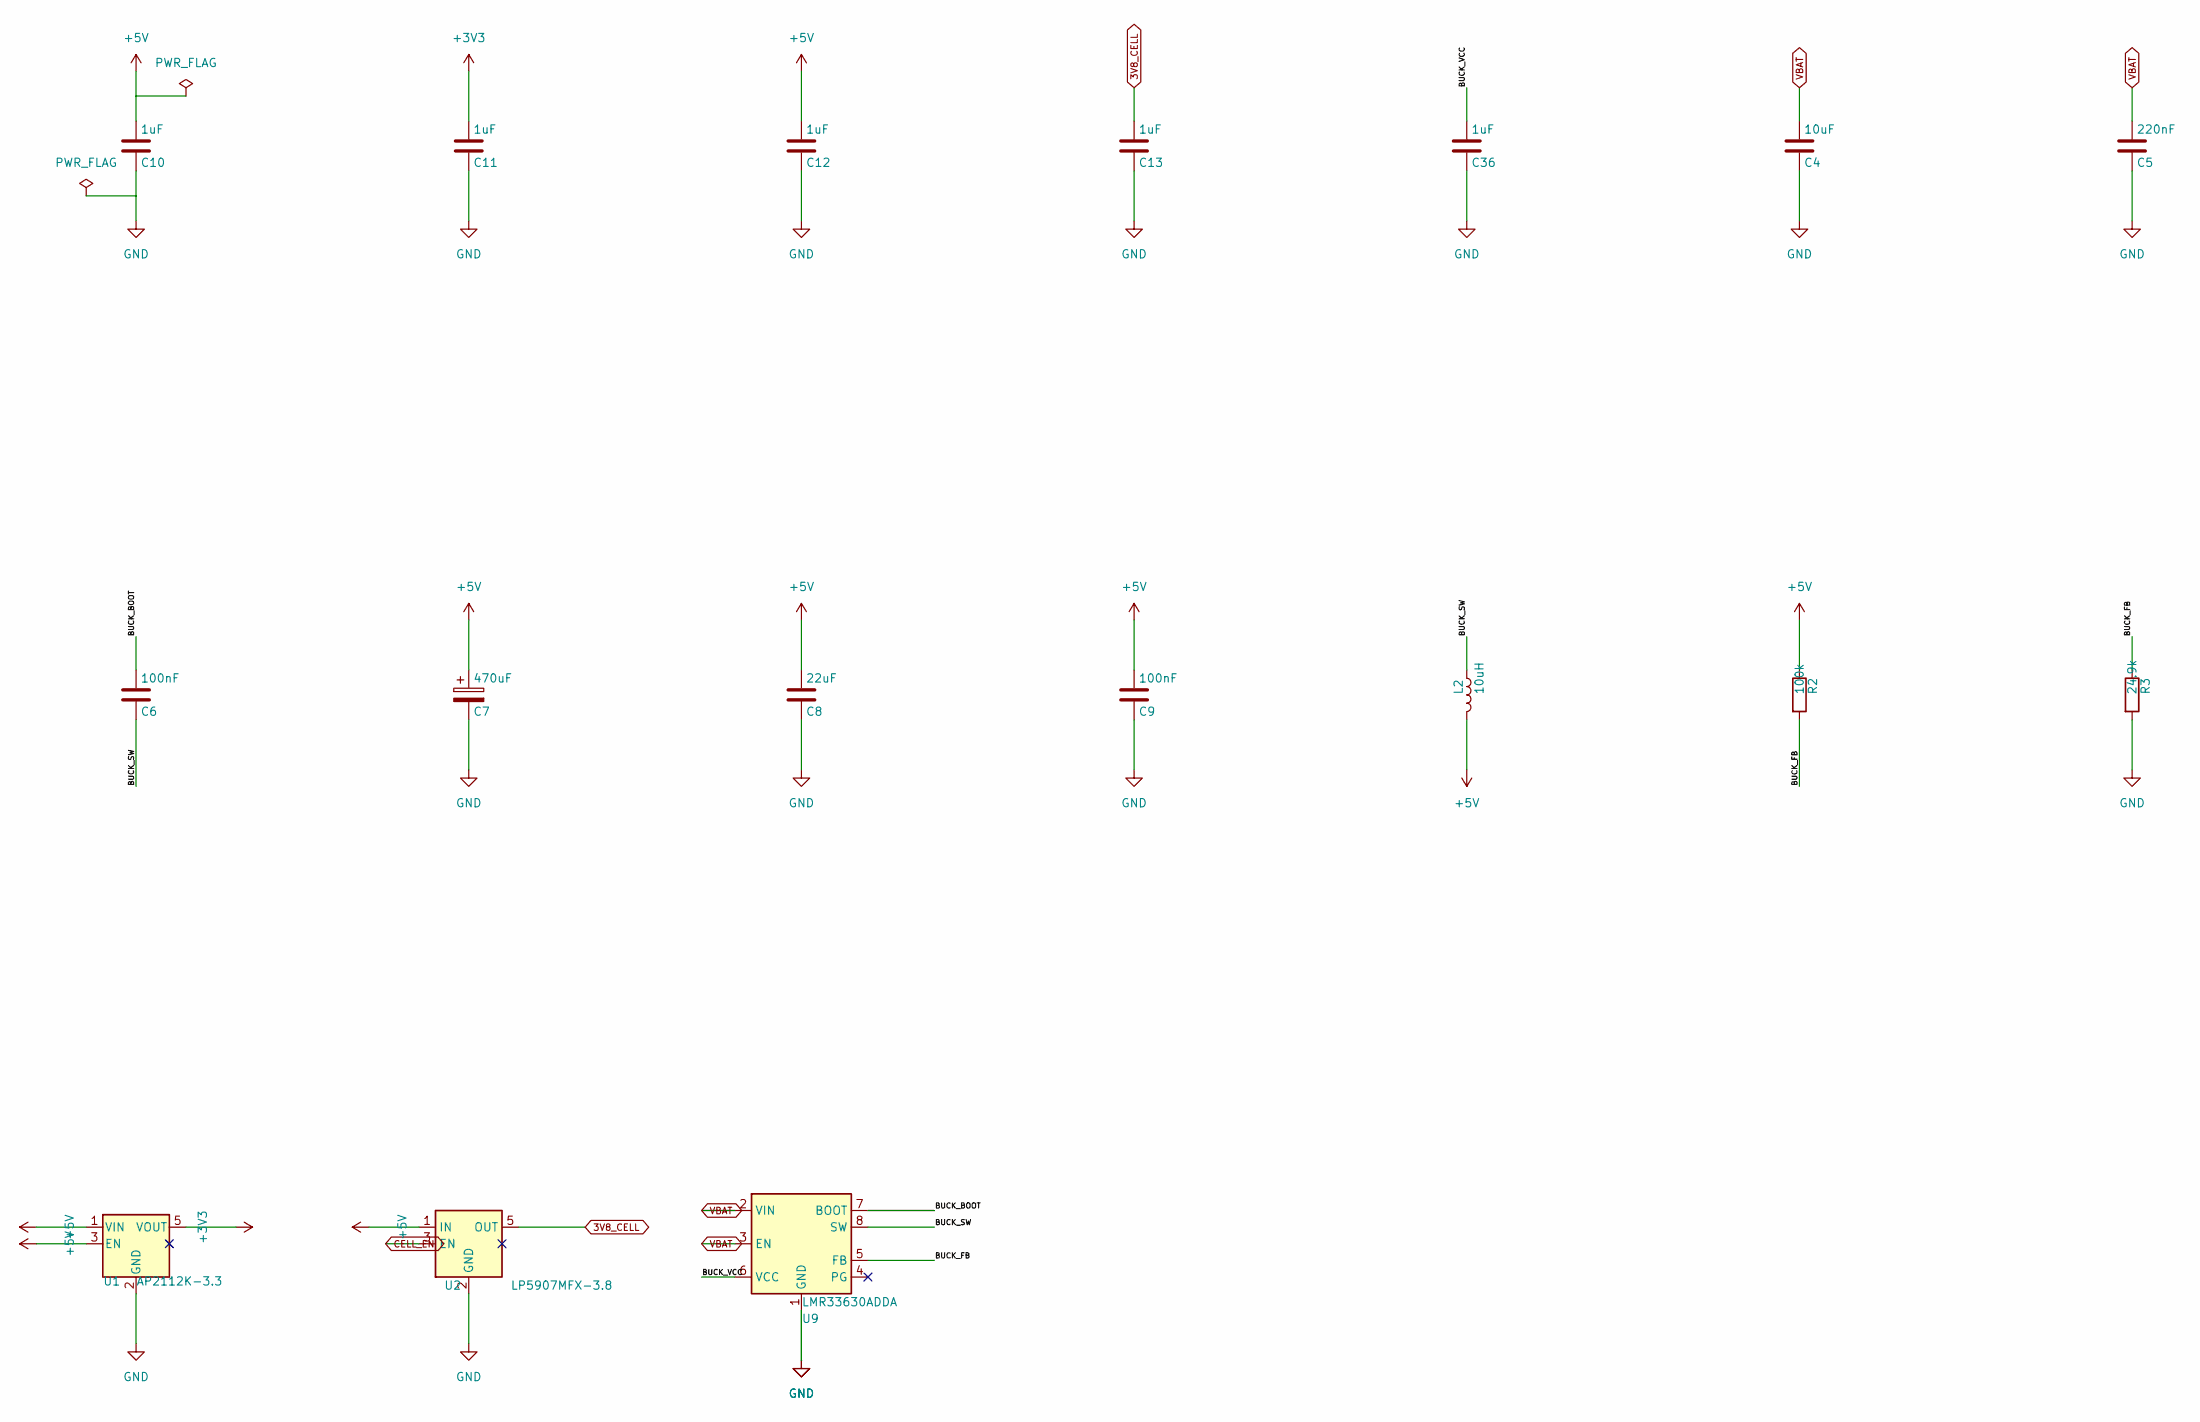
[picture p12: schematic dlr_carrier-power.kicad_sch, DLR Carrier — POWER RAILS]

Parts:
C4: 10uF; C_1206_3216Metric
C5: 220nF; C_0402_1005Metric
C6, C9: 100nF; C_0402_1005Metric
C7: 470uF; CP_Elec_8x10
C8: 22uF; C_0805_2012Metric
C10, C11, C12, C13, C36: 1uF; C_0402_1005Metric
L2: 10uH; L_Bourns_SRN8040TA
R2: 100k; R_0402_1005Metric
R3: 24.9k; R_0402_1005Metric
U1: AP2112K-3.3; SOT-23-5
U2: LP5907MFX-3.8; SOT-23-5
U9: LMR33630ADDA; Texas_HSOP-8-1EP_3.9x4.9mm_P1.27mm_ThermalVias

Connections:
3V3: C11.1, U1.5 (VOUT); also elsewhere on the board
3V8_CELL: C13.1, U2.5 (OUT); also elsewhere on the board
5V_RAIL: C7.1, C8.1, C9.1, C10.1, C12.1, L2.2, R2.1, U1.1 (VIN), U1.3 (EN), U2.1 (IN); also elsewhere on the board
BUCK_BOOT: C6.1, U9.7 (BOOT)
BUCK_FB: R2.2, R3.1, U9.5 (FB)
BUCK_SW: C6.2, L2.1, U9.8 (SW)
BUCK_VCC: C36.1, U9.6 (VCC)
CELL_EN: U2.3 (EN); also elsewhere on the board
GND: C4.2, C5.2, C7.2, C8.2, C9.2, C10.2, C11.2, C12.2, C13.2, C36.2, R3.2, U1.2 (GND), U2.2 (GND), U9.1 (GND), U9.9 (GND); also elsewhere on the board
VBAT: C4.1, C5.1, U9.2 (VIN), U9.3 (EN); also elsewhere on the board

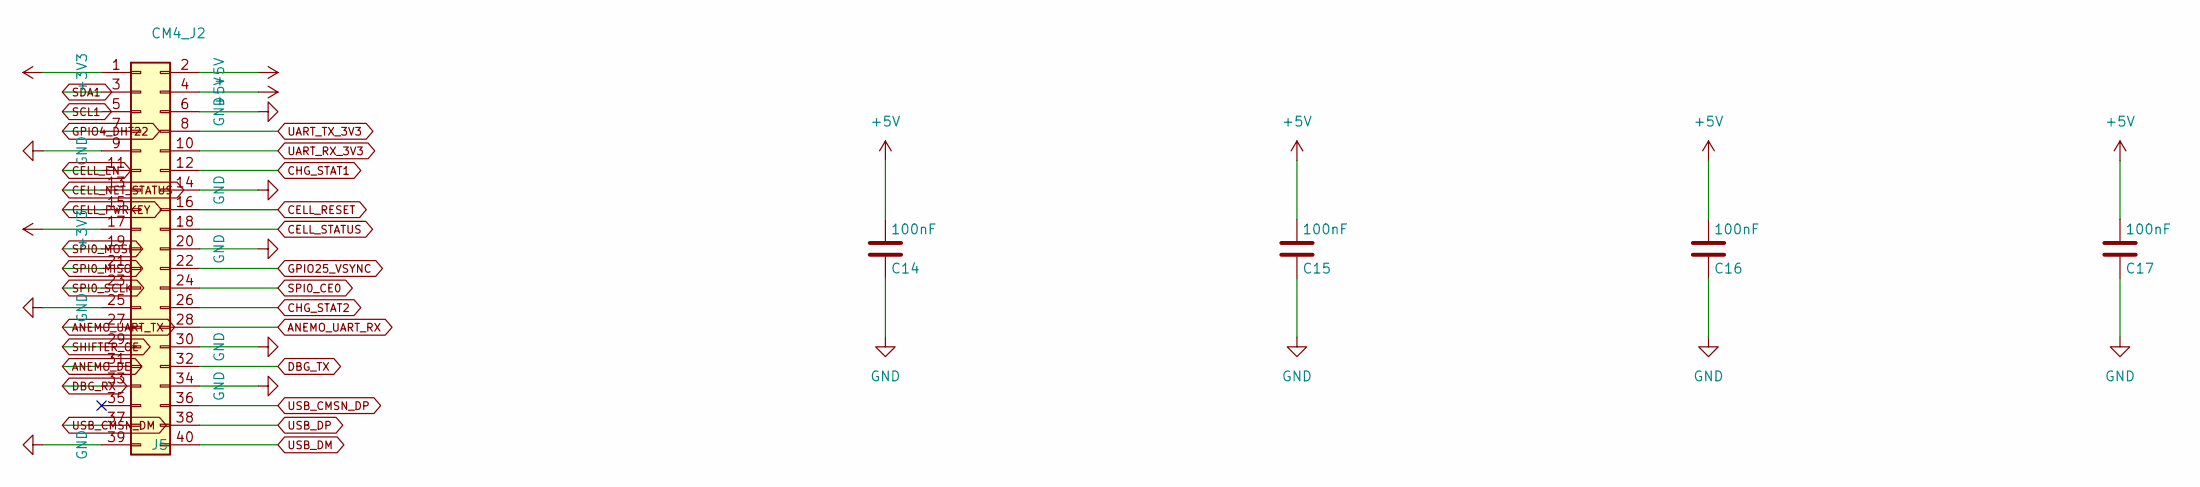
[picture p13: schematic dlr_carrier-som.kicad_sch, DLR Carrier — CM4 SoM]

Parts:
C14, C15, C16, C17: 100nF; C_0402_1005Metric
J5: CM4_J2; Hirose_DF40HC(3.0)-40DS-0.4V_2x20_P0.4mm

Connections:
3V3: J5.1, J5.17; also elsewhere on the board
5V_RAIL: C14.1, C15.1, C16.1, C17.1, J5.2, J5.4; also elsewhere on the board
ANEMO_DE: J5.31; also elsewhere on the board
ANEMO_UART_RX: J5.28; also elsewhere on the board
ANEMO_UART_TX: J5.27; also elsewhere on the board
CELL_EN: J5.11; also elsewhere on the board
CELL_NET_STATUS: J5.13; also elsewhere on the board
CELL_PWRKEY: J5.15; also elsewhere on the board
CELL_RESET: J5.16; also elsewhere on the board
CELL_STATUS: J5.18; also elsewhere on the board
CHG_STAT1: J5.12; also elsewhere on the board
CHG_STAT2: J5.26; also elsewhere on the board
DBG_RX: J5.33; also elsewhere on the board
DBG_TX: J5.32; also elsewhere on the board
GND: C14.2, C15.2, C16.2, C17.2, J5.6, J5.9, J5.14, J5.20, J5.25, J5.30, J5.34, J5.39; also elsewhere on the board
GPIO4_DHT22: J5.7; also elsewhere on the board
GPIO25_VSYNC: J5.22; also elsewhere on the board
SCL1: J5.5; also elsewhere on the board
SDA1: J5.3; also elsewhere on the board
SHIFTER_OE: J5.29; also elsewhere on the board
SPI0_CE0: J5.24; also elsewhere on the board
SPI0_MISO: J5.21; also elsewhere on the board
SPI0_MOSI: J5.19; also elsewhere on the board
SPI0_SCLK: J5.23; also elsewhere on the board
UART_RX_3V3: J5.10; also elsewhere on the board
UART_TX_3V3: J5.8; also elsewhere on the board
USB_CMSN_DM: J5.37; also elsewhere on the board
USB_CMSN_DP: J5.36; also elsewhere on the board
USB_DM: J5.40; also elsewhere on the board
USB_DP: J5.38; also elsewhere on the board

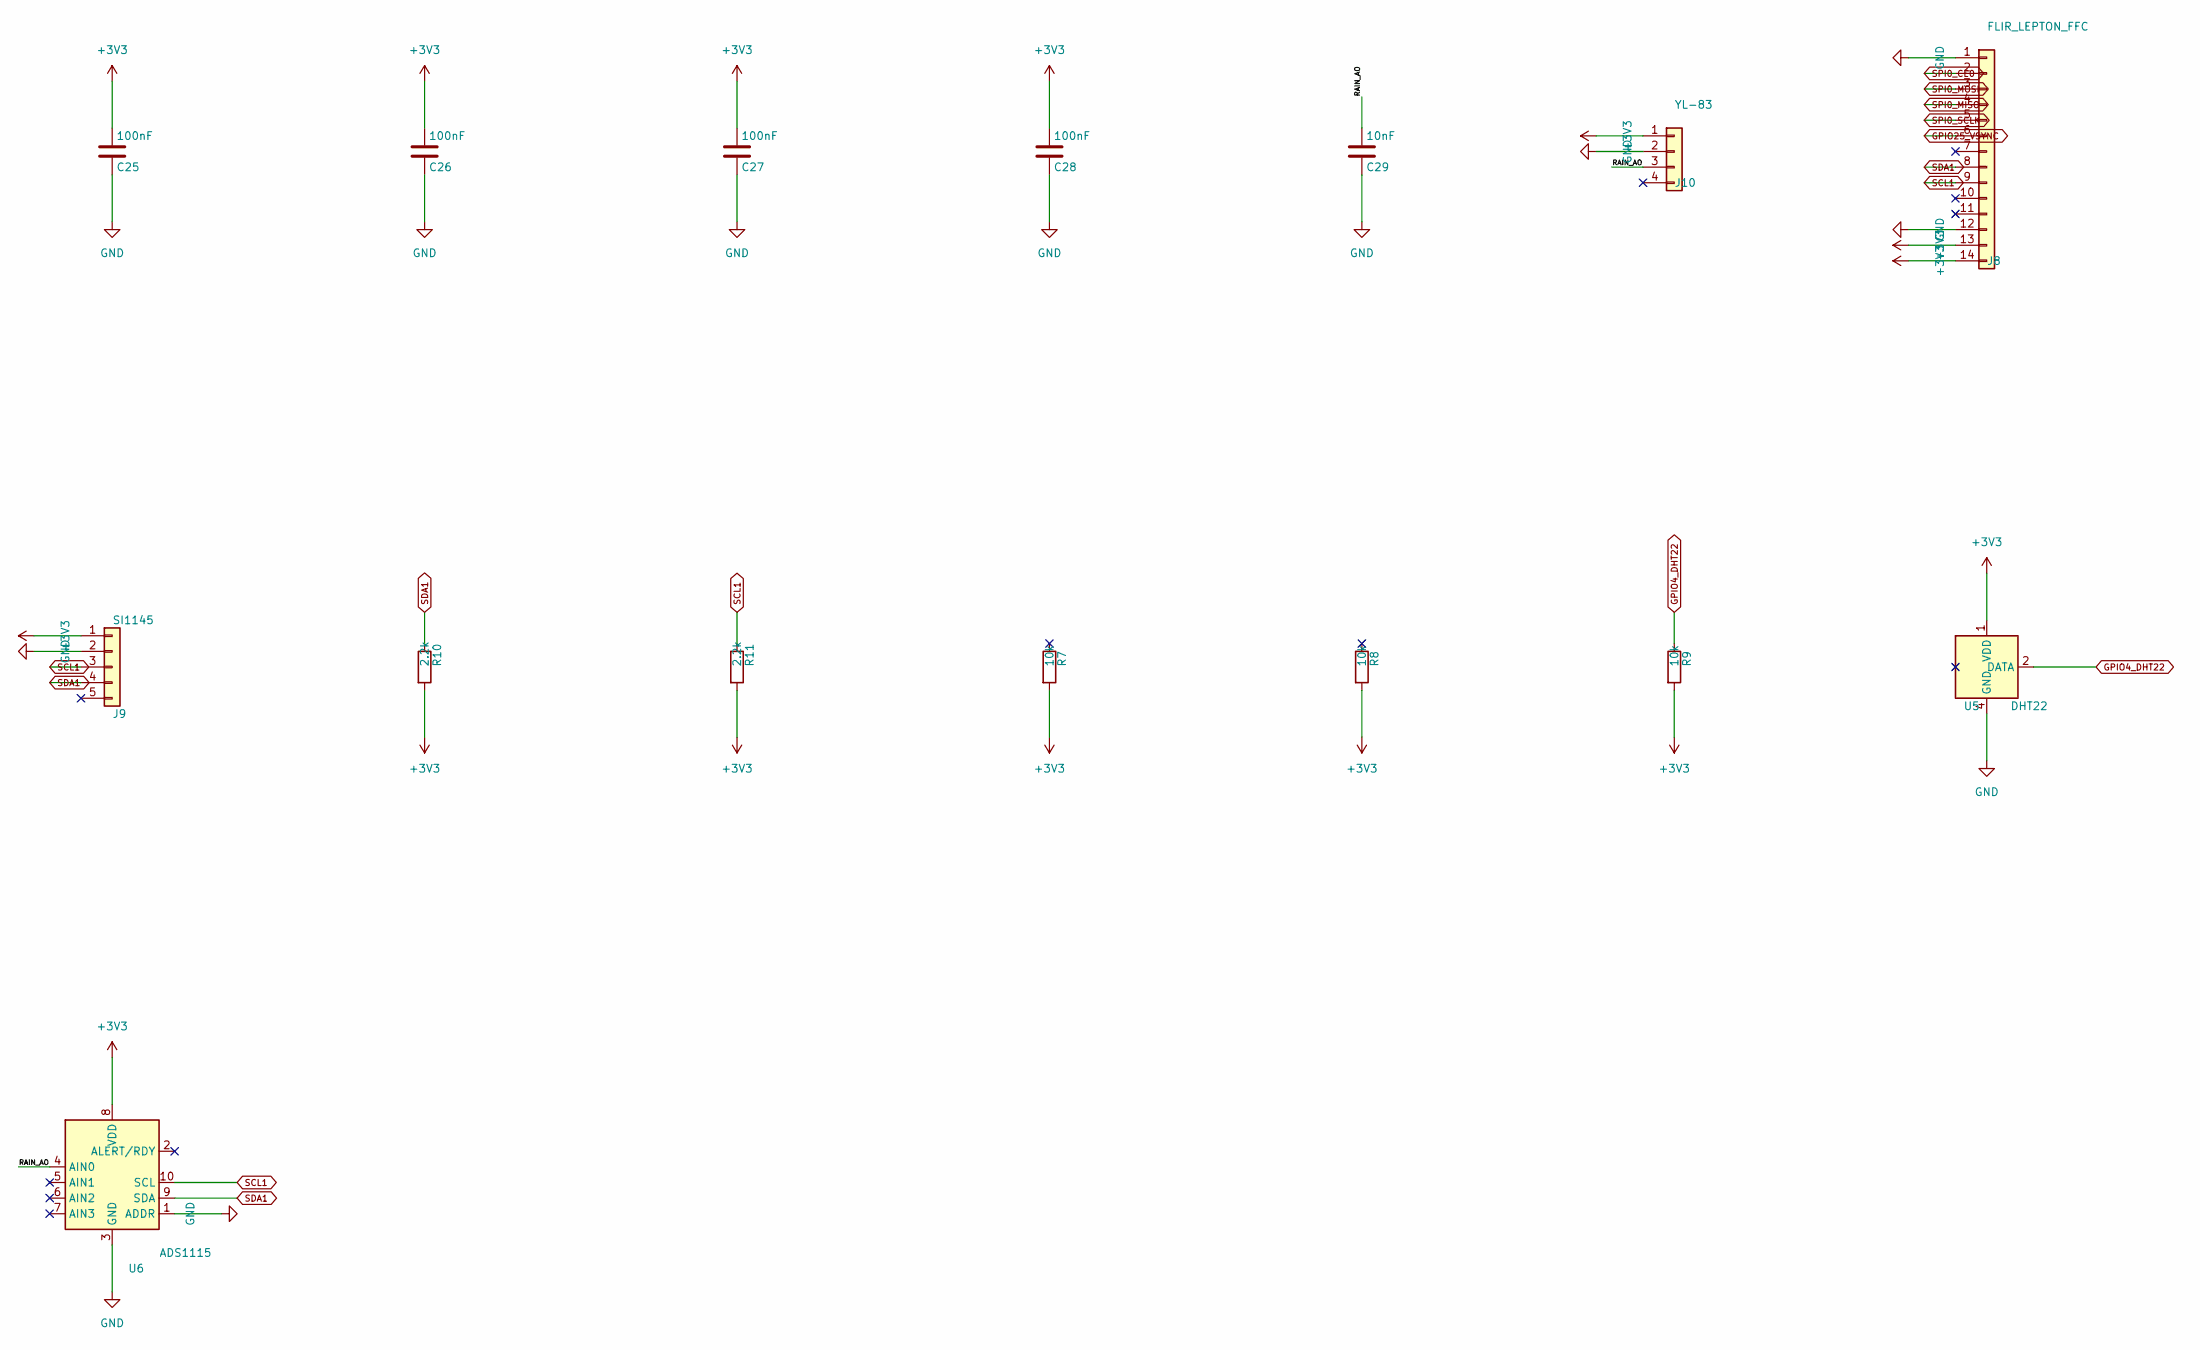
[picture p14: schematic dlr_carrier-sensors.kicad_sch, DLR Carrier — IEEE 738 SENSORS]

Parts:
C25, C26, C27, C28: 100nF; C_0402_1005Metric
C29: 10nF; C_0402_1005Metric
J8: FLIR_LEPTON_FFC; Hirose_FH12-14S-0.5SH_1x14-1MP_P0.50mm_Horizontal
J9: SI1145; PinHeader_1x05_P2.54mm_Vertical
J10: YL-83; PinHeader_1x04_P2.54mm_Vertical
R7, R8, R9: 10k; R_0402_1005Metric
R10, R11: 2.2k; R_0402_1005Metric
U5: DHT22; Aosong_DHT11_5.5x12.0_P2.54mm
U6: ADS1115; MSOP-10_3x3mm_P0.5mm

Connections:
3V3: C25.1, C26.1, C27.1, C28.1, J8.13, J8.14, J9.1, J10.1, R7.2, R8.2, R9.2, R10.2, R11.2, U5.1 (VDD), U6.8 (VDD); also elsewhere on the board
GND: C25.2, C26.2, C27.2, C28.2, C29.2, J8.1, J8.12, J9.2, J10.2, U5.4 (GND), U6.1 (ADDR), U6.3 (GND); also elsewhere on the board
GPIO4_DHT22: R9.1, U5.2 (DATA); also elsewhere on the board
GPIO25_VSYNC: J8.6; also elsewhere on the board
unnamed: J8.10, R7.1
unnamed: J8.11, R8.1
RAIN_AO: C29.1, J10.3, U6.4 (AIN0)
SCL1: J8.9, J9.3, R11.1, U6.10 (SCL); also elsewhere on the board
SDA1: J8.8, J9.4, R10.1, U6.9 (SDA); also elsewhere on the board
SPI0_CE0: J8.2; also elsewhere on the board
SPI0_MISO: J8.4; also elsewhere on the board
SPI0_MOSI: J8.3; also elsewhere on the board
SPI0_SCLK: J8.5; also elsewhere on the board

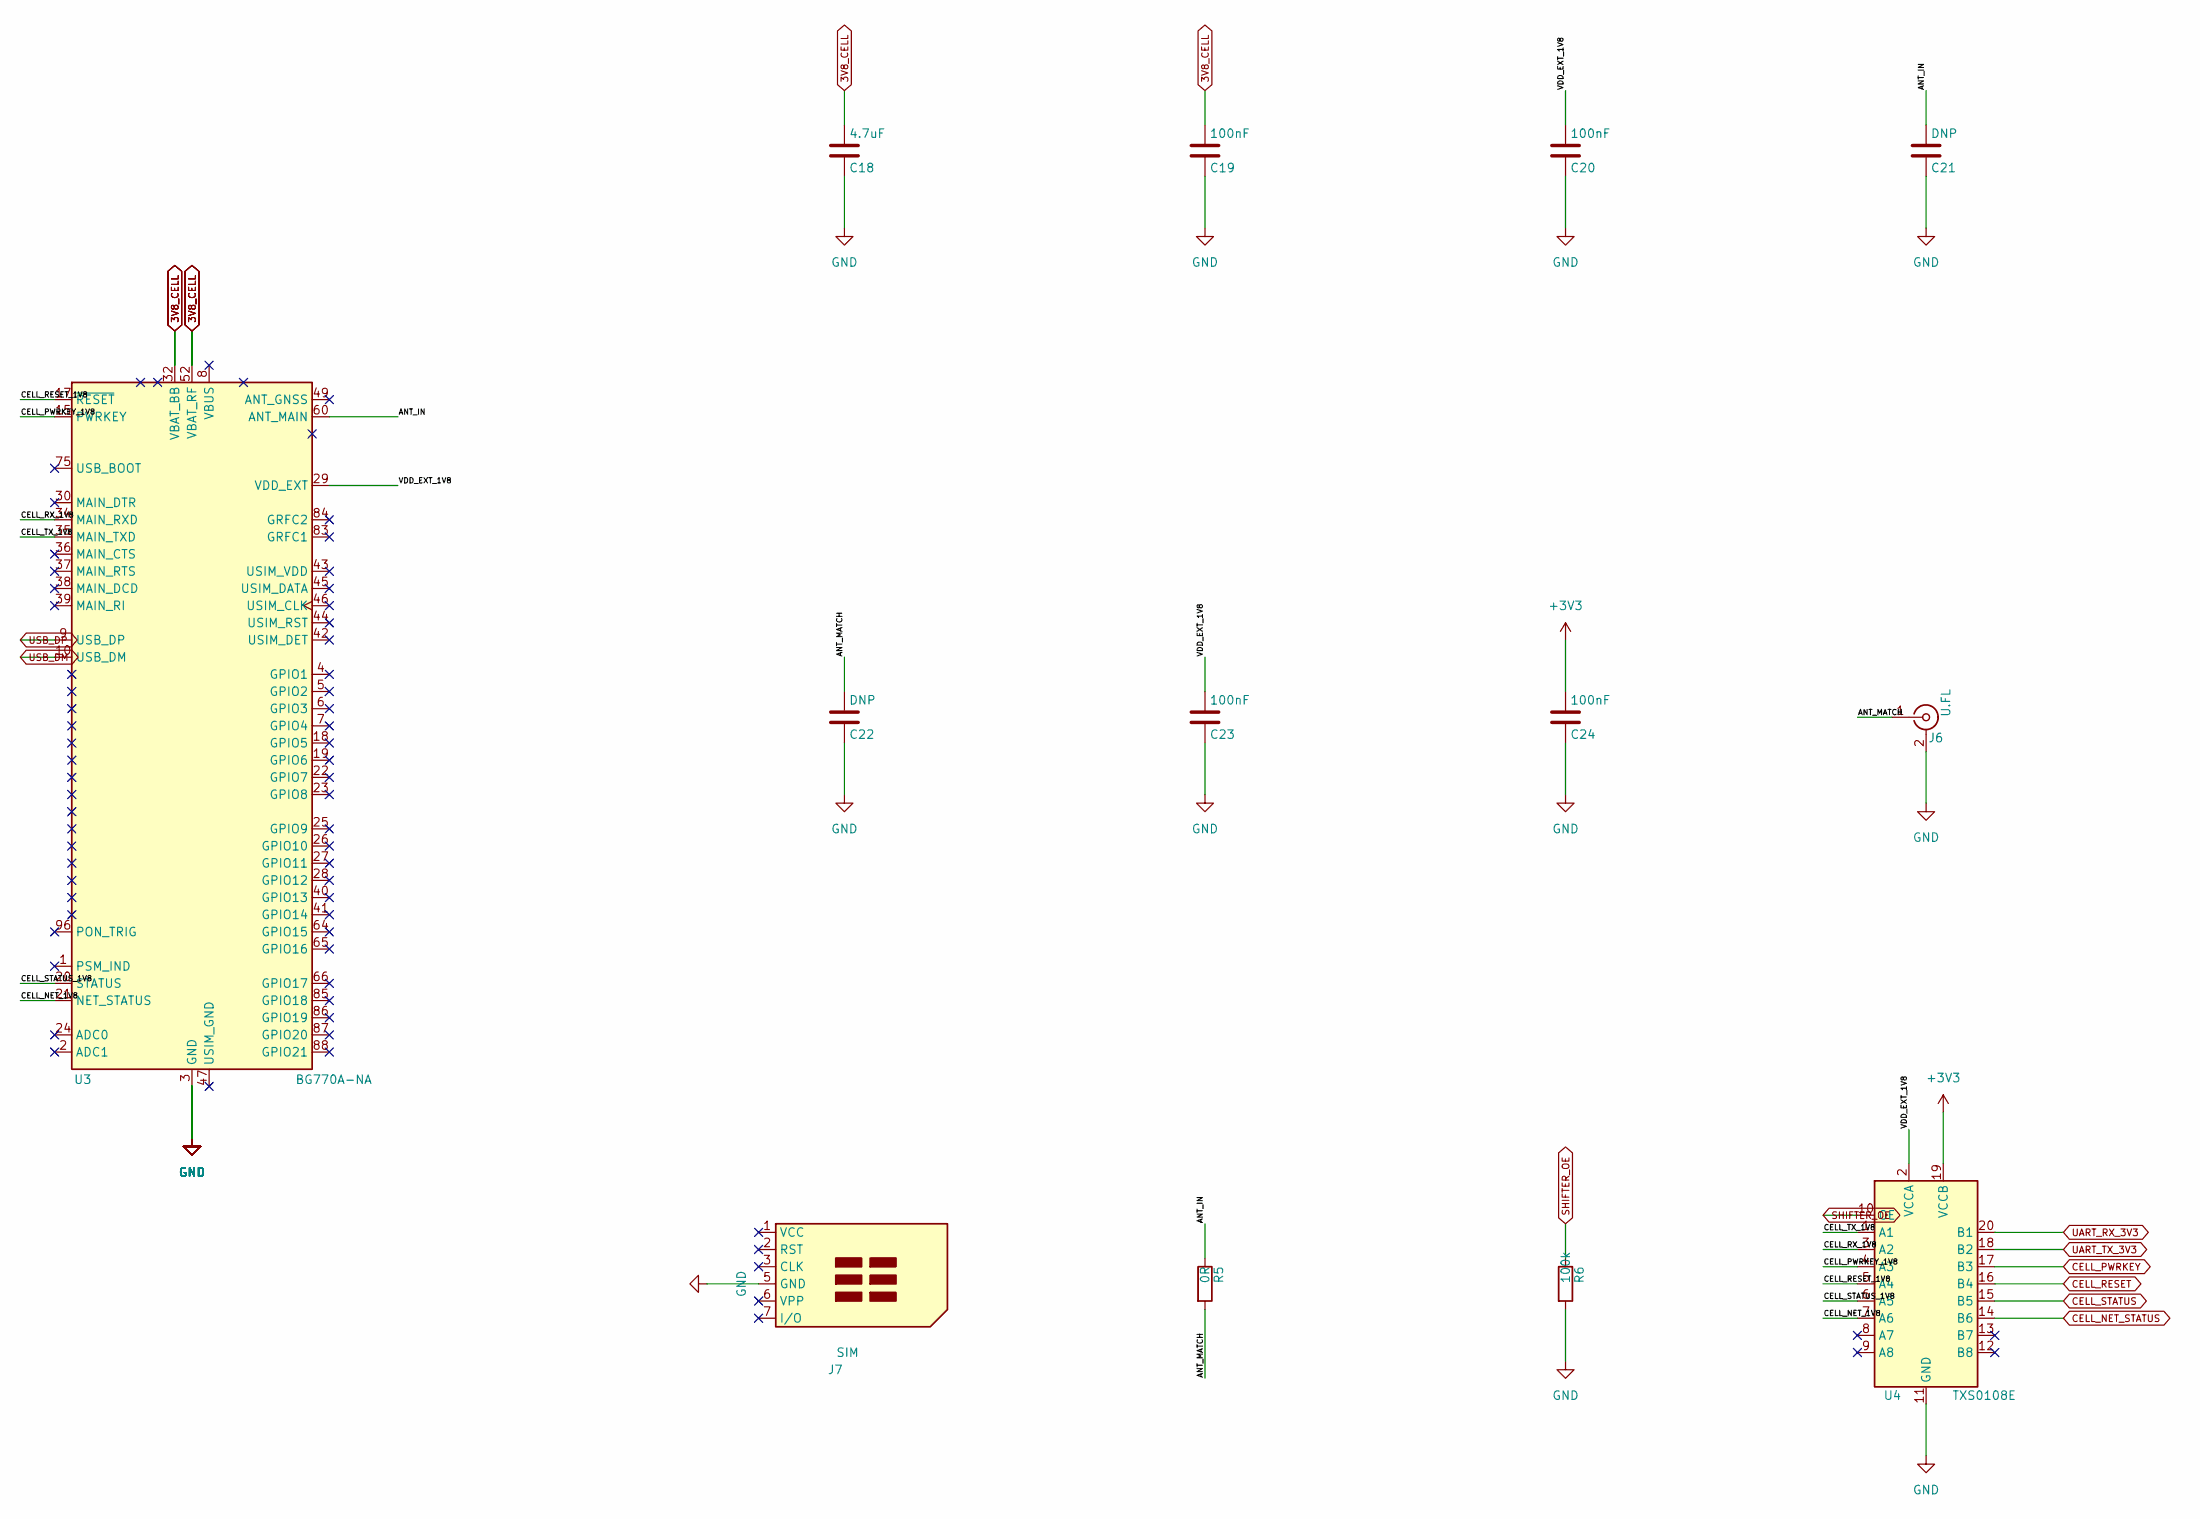
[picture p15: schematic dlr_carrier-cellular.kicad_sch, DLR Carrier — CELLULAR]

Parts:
C18: 4.7uF; C_0402_1005Metric
C19, C20, C23, C24: 100nF; C_0402_1005Metric
C21, C22: DNP; C_0402_1005Metric
J6: U.FL; U.FL_Hirose_U.FL-R-SMT-1_Vertical
J7: SIM; microSIM_JAE_SF53S006VCBR2000
R5: 0R; R_0402_1005Metric
R6: 100k; R_0402_1005Metric
U3: BG770A-NA; Quectel_BG95
U4: TXS0108E; TSSOP-20_4.4x6.5mm_P0.65mm

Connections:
3V3: C24.1, U4.19 (VCCB); also elsewhere on the board
3V8_CELL: C18.1, C19.1, U3.32 (VBAT_BB), U3.33 (VBAT_BB), U3.52 (VBAT_RF), U3.53 (VBAT_RF); also elsewhere on the board
ANT_IN: C21.1, R5.1, U3.60 (ANT_MAIN)
ANT_MATCH: C22.1, J6.1 (In), R5.2
CELL_NET_1V8: U3.21 (NET_STATUS), U4.7 (A6)
CELL_NET_STATUS: U4.14 (B6); also elsewhere on the board
CELL_PWRKEY: U4.17 (B3); also elsewhere on the board
CELL_PWRKEY_1V8: U3.15 (PWRKEY), U4.4 (A3)
CELL_RESET: U4.16 (B4); also elsewhere on the board
CELL_RESET_1V8: U3.17 (~RESET), U4.5 (A4)
CELL_RX_1V8: U3.34 (MAIN_RXD), U4.3 (A2)
CELL_STATUS: U4.15 (B5); also elsewhere on the board
CELL_STATUS_1V8: U3.20 (STATUS), U4.6 (A5)
CELL_TX_1V8: U3.35 (MAIN_TXD), U4.1 (A1)
GND: C18.2, C19.2, C20.2, C21.2, C22.2, C23.2, C24.2, J6.2 (Ext), J7.5 (GND), J7.SH, R6.2, U3.3 (GND), U3.31 (GND), U3.48 (GND), U3.50 (GND), U3.54 (GND), U3.55 (GND), U3.58 (GND), U3.59 (GND), U3.61 (GND), U3.62 (GND), U3.67 (GND), U3.68 (GND), U3.69 (GND), U3.70 (GND), U3.71 (GND), U3.72 (GND), U3.73 (GND), U3.74 (GND), U3.79 (GND), U3.80 (GND), U3.81 (GND), U3.82 (GND), U3.89 (GND), U3.90 (GND), U3.91 (GND), U3.100 (GND), U3.101 (GND), U3.102 (GND), U4.11 (GND); also elsewhere on the board
unnamed: J7.1 (VCC), U3.43 (USIM_VDD)
unnamed: J7.2 (RST), U3.44 (USIM_RST)
unnamed: J7.3 (CLK), U3.46 (USIM_CLK)
unnamed: J7.7 (I/O), U3.45 (USIM_DATA)
SHIFTER_OE: R6.1, U4.10 (OE); also elsewhere on the board
UART_RX_3V3: U4.20 (B1); also elsewhere on the board
UART_TX_3V3: U4.18 (B2); also elsewhere on the board
USB_DM: U3.10 (USB_DM); also elsewhere on the board
USB_DP: U3.9 (USB_DP); also elsewhere on the board
VDD_EXT_1V8: C20.1, C23.1, U3.29 (VDD_EXT), U4.2 (VCCA)

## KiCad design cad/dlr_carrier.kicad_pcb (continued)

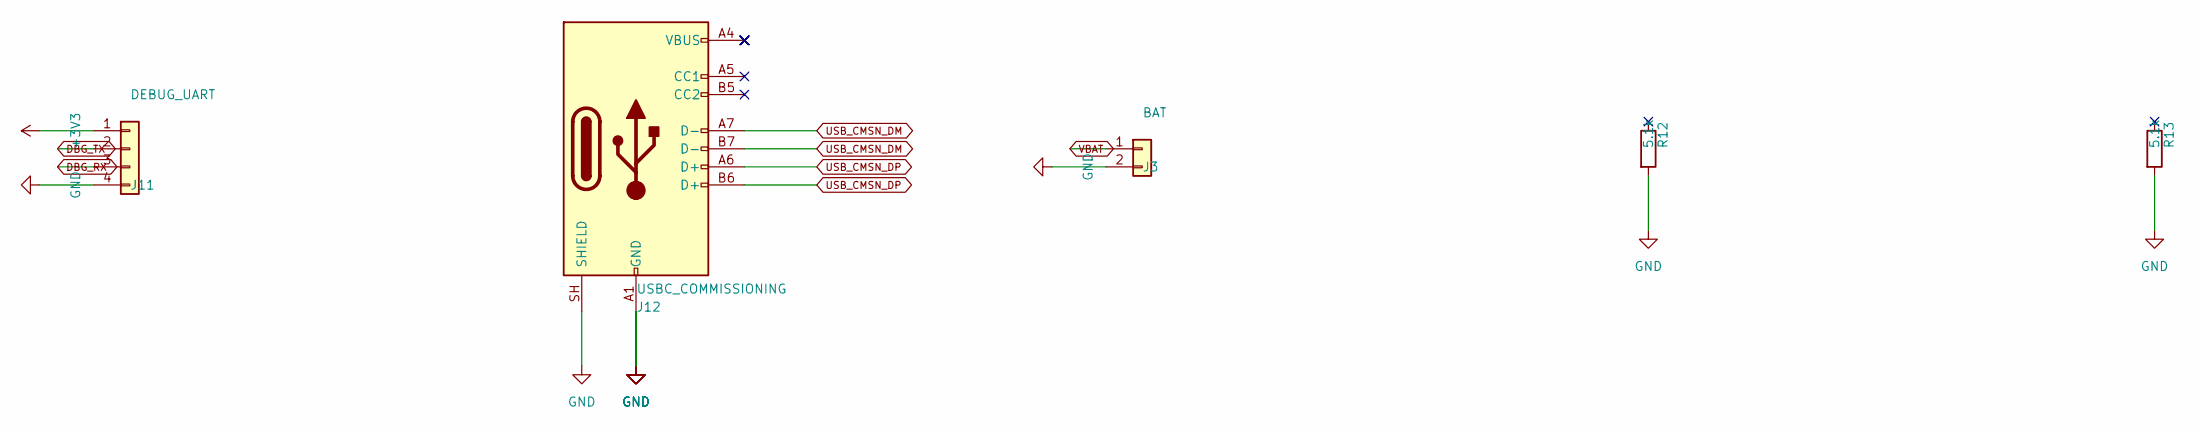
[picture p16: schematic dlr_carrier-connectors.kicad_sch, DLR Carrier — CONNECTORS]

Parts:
J3: BAT; TerminalBlock_Phoenix_MKDS-1,5-2-5.08_1x02_P5.08mm_Horizont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
J11: DEBUG_UART; PinHeader_1x04_P2.54mm_Vertical
J12: USBC_COMMISSIONING; USB_C_Receptacle_GCT_USB4085
R12, R13: 5.1k; R_0402_1005Metric

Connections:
3V3: J11.1; also elsewhere on the board
DBG_RX: J11.3; also elsewhere on the board
DBG_TX: J11.2; also elsewhere on the board
GND: J3.2, J11.4, J12.A1 (GND), J12.A12 (GND), J12.B1 (GND), J12.B12 (GND), J12.SH (SHIELD), R12.2, R13.2; also elsewhere on the board
unnamed: J12.A5 (CC1), R12.1
unnamed: J12.B5 (CC2), R13.1
USB_CMSN_DM: J12.A7 (D-), J12.B7 (D-); also elsewhere on the board
USB_CMSN_DP: J12.A6 (D+), J12.B6 (D+); also elsewhere on the board
VBAT: J3.1; also elsewhere on the board

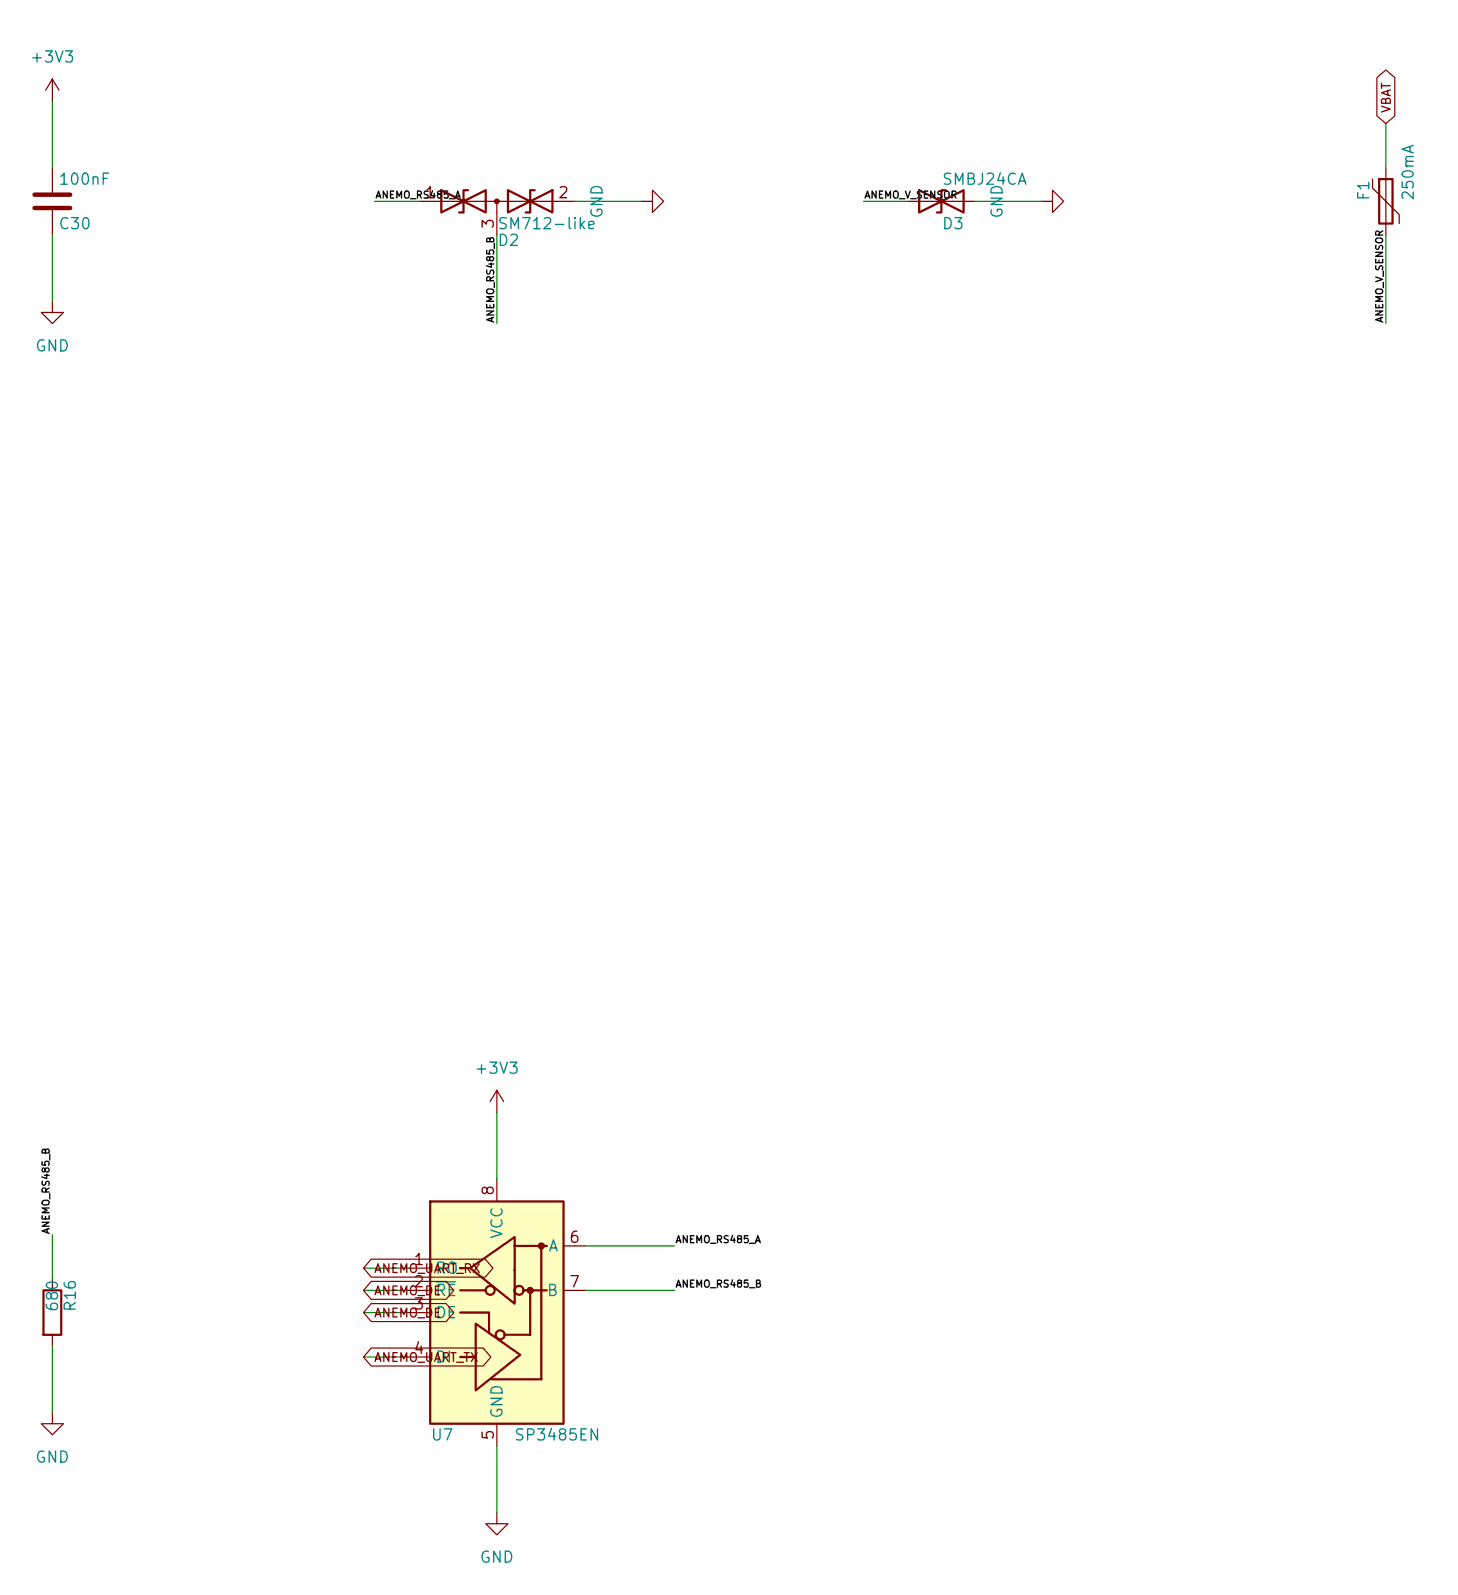
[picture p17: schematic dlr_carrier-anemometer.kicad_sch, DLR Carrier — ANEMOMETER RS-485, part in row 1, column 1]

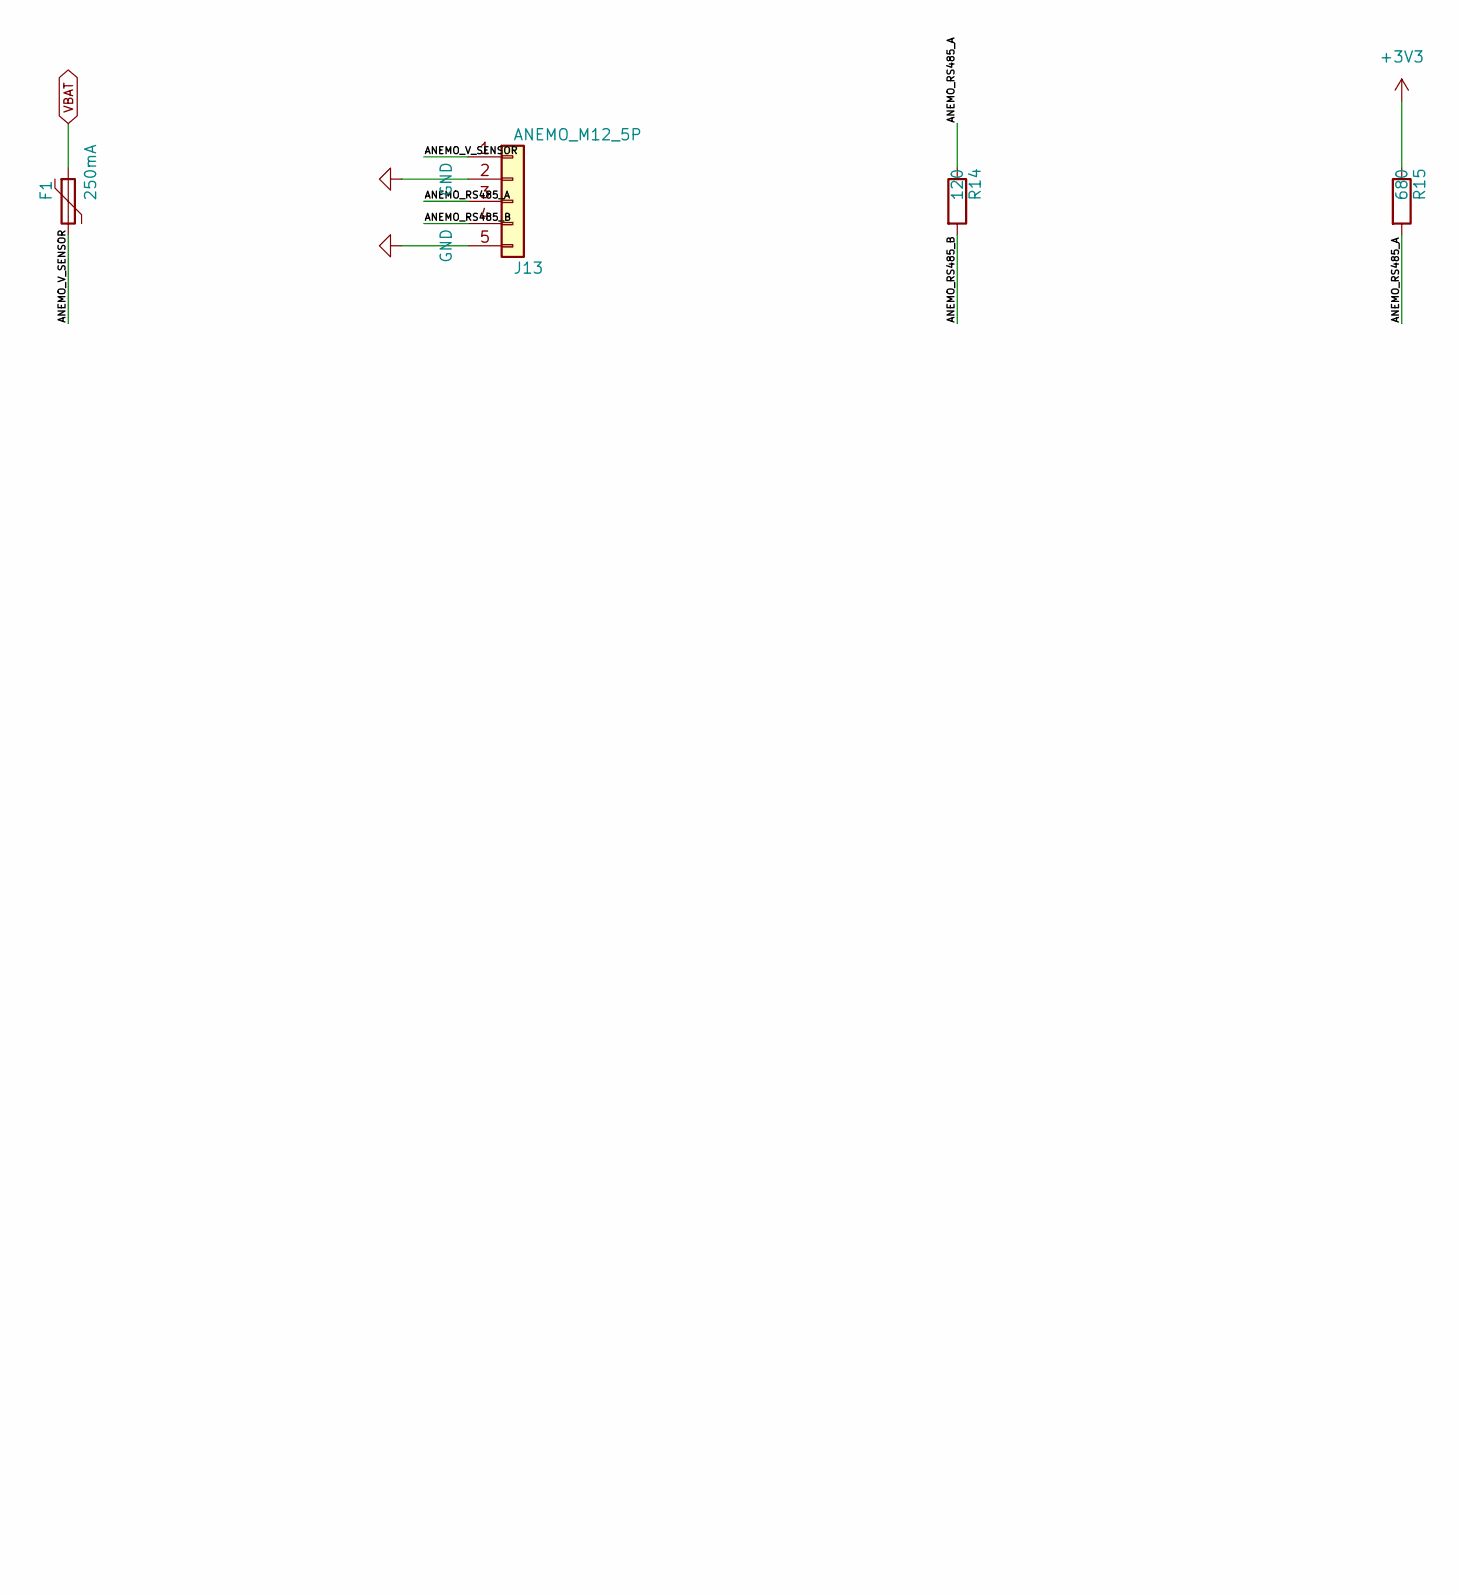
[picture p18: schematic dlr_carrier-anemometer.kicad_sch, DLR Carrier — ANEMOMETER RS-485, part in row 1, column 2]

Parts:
C30: 100nF; C_0402_1005Metric
D2: SM712-like; SOT-23
D3: SMBJ24CA; D_SMB
F1: 250mA; R_1206_3216Metric
J13: ANEMO_M12_5P; PinHeader_1x05_P2.54mm_Vertical
R14: 120; R_0402_1005Metric
R15, R16: 680; R_0402_1005Metric
U7: SP3485EN; SOIC-8_3.9x4.9mm_P1.27mm

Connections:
3V3: C30.1, R15.1, U7.8 (VCC); also elsewhere on the board
ANEMO_DE: U7.2 (~RE), U7.3 (DE); also elsewhere on the board
ANEMO_RS485_A: D2.1 (A1), J13.3, R14.1, R15.2, U7.6 (A)
ANEMO_RS485_B: D2.3 (common), J13.4, R14.2, R16.1, U7.7 (B)
ANEMO_UART_RX: U7.1 (RO); also elsewhere on the board
ANEMO_UART_TX: U7.4 (DI); also elsewhere on the board
ANEMO_V_SENSOR: D3.1 (A1), F1.2, J13.1
GND: C30.2, D2.2 (A2), D3.2 (A2), J13.2, J13.5, R16.2, U7.5 (GND); also elsewhere on the board
VBAT: F1.1; also elsewhere on the board

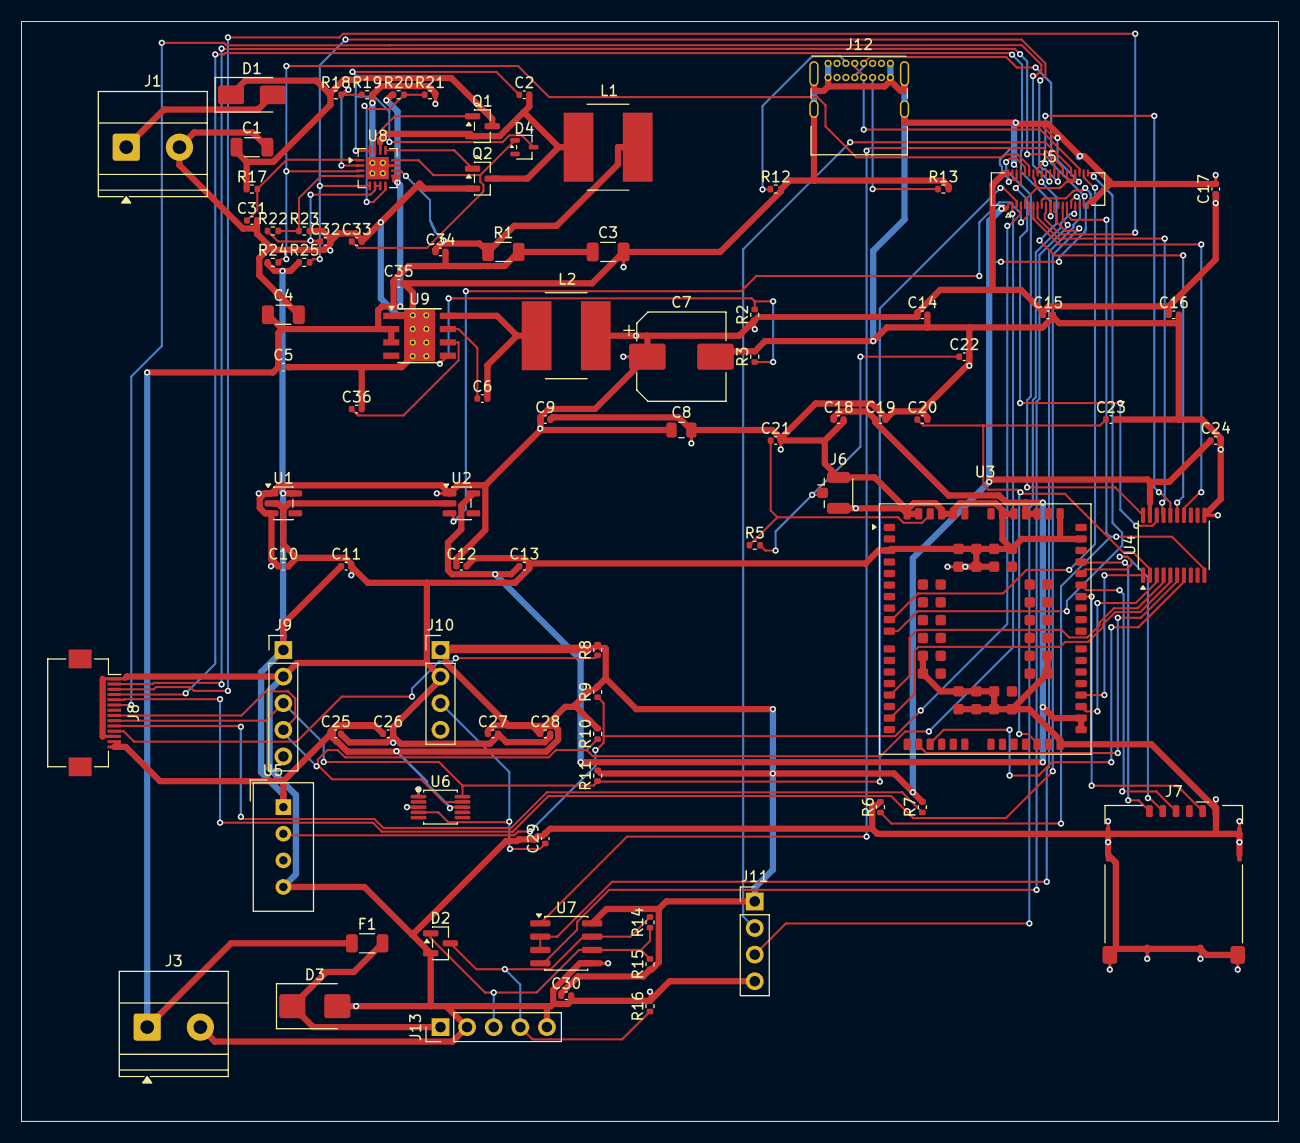
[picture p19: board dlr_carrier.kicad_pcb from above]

Board: 4 copper layers, 120.0 x 105.0 mm, 89 parts (0 on the bottom side), 70 nets.

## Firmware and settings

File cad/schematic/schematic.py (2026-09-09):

"""DLR carrier schematic generator — block-aware placement, label-based connectivity.

Reads cad/dlr_carrier.net, classifies each component into a block (power, som,
cellular, sensors, connectors, misc), places each block's components in a
sub-grid within the block's region defined in layout_spec.yaml. Inter-block
connectivity is preserved through labels and power symbols.
"""

import contextlib
import math
from pathlib import Path
from typing import Final

import sexpdata
import yaml

LAYOUT_SPEC_PATH = Path("cad/layout_spec.yaml")
NETLIST_PATH = Path("cad/dlr_carrier.net")
SCHEMATIC_PATH = "cad/dlr_carrier.kicad_sch"

LIB_BY_PART: Final = {
    "C": "Device",
    "C_Polarized": "Device",
    "R": "Device",
    "L": "Device",
    "D_Schottky": "Device",
    "D_TVS": "Device",
    "D_TVS_Dual_AAC": "Device",
    "Polyfuse": "Device",
    "Conn_Coaxial": "Connector",
    "SIM_Card": "Connector",
    "AP2112K-3.3": "Regulator_Linear",
    "LP5907MFX-3.3": "Regulator_Linear",
    "BG95-M1": "RF_GSM",
    "TXS0108EPW": "Logic_LevelTranslator",
    "ADS1115IDGS": "Analog_ADC",
    "DHT11": "Sensor",
    "SP3485EN": "Interface_UART",
    "USB_C_Receptacle_USB2.0_14P": "Connector",
    "BQ24650": "Battery_Management",
    "LMR33630ADDA": "Regulator_Switching",
    "Q_NMOS_GSD": "Transistor_FET",
    "BAT54W": "Diode",
}

# Component value -> block (catches all uniquely-named ICs and connectors)
VALUE_TO_BLOCK: Final = {
    # power
    "PV_IN": "power",
    "SS34": "power",
    "BQ24650": "power",
    "LMR33630ADDA": "power",
    "AP2112K-3.3": "power",
    "LP5907MFX-3.8": "power",
    # som
    "CM4_J2": "som",
    # cellular
    "BG770A-NA": "cellular",
    "TXS0108E": "cellular",
    "U.FL": "cellular",
    "SIM": "cellular",
    # sensors
    "FLIR_LEPTON": "sensors",
    "FLIR_LEPTON_FFC": "sensors",
    "DHT22": "sensors",
    "SI1145": "sensors",
    "YL-83": "sensors",
    "ADS1115": "sensors",
    # connectors
    "BAT": "connectors",
    "DEBUG_UART": "connectors",
    "USBC_COMMISSIONING": "connectors",
    # anemometer
    "SP3485EN": "anemometer",
    "ANEMO_M12_5P": "anemometer",
    "SM712-like": "anemometer",
    "SMBJ24CA": "anemometer",
}

# Block-specific nets (for classifying passives that don't have unique values)
BLOCK_NETS: Final = {
    "power": {
        "PV_IN",
        "PV_RAW",
        "VBAT",
        "BAT_SRP",
        "MPPT_SW",
        "MPPT_BOOT",
        "BUCK_SW",
        "BUCK_BOOT",
        "BUCK_FB",
        "BUCK_RT",
    },
    "cellular": {
        "3V8_CELL",
        "VDD_EXT_1V8",
        "ANT_IN",
        "ANT_MATCH",
        "CELL_PWRKEY",
        "CELL_RESET",
        "CELL_STATUS",
        "CELL_NET_STATUS",
        "CELL_TX_1V8",
        "CELL_RX_1V8",
        "CELL_PWRKEY_1V8",
        "CELL_RESET_1V8",
        "CELL_STATUS_1V8",
        "CELL_NET_1V8",
    },
    "sensors": {
        "RAIN_AO",
        "GPIO4_DHT22",
        "GPIO25_VSYNC",
    },
    "connectors": {"DBG_TX", "DBG_RX"},
    "anemometer": {
        "ANEMO_RS485_A",
        "ANEMO_RS485_B",
        "ANEMO_UART_TX",
        "ANEMO_UART_RX",
        "ANEMO_DE",
        "ANEMO_V_SENSOR",
        "ANEMO_SHIELD",
    },
}

POWER_SYMBOL_BY_NET: Final = {
    "GND": "power:GND",
    "5V_RAIL": "power:+5V",
    "3V3": "power:+3V3",
}


def _real_pin_position(comp, pin_num: str):
    """Pin position in sheet coords, fixing kicad-sch-api's y-inversion bug.

    kicad-sch-api computes pin_y = sym_y + pin_offset_y, but KiCad's actual
    rendering uses pin_y = sym_y - pin_offset_y (symbol coords are +y up,
    sheet coords are +y down). Reflect ksa's reported y around sym_y to get
    the position KiCad will actually draw the pin at.

    Only valid for unrotated symbols (rotation=0). All components produced
    by _place_one are placed unrotated, so this assumption holds.
    """
    pos = comp.get_pin_position(pin_num)
    if not pos:
        return None
    sym_y = comp.position.y
    return type(pos)(pos.x, 2 * sym_y - pos.y)


def _resolve_lib(part_name: str) -> str:
    if part_name in LIB_BY_PART:
        return LIB_BY_PART[part_name]
    if part_name.startswith("Conn_01x") or part_name.startswith("Conn_02x"):
        return "Connector_Generic"
    raise ValueError(f"Unknown lib for part {part_name!r}")


def _parse_netlist(path: Path) -> tuple[list[dict], list[dict]]:  # noqa: C901
    """Extract components and nets from a SKiDL-generated kicad netlist."""
    data = sexpdata.loads(path.read_text())
    components, nets = [], []

    def s(node) -> str:
        return str(node[0]) if isinstance(node, list) and node else ""

    def find_section(root, key) -> list:
        if isinstance(root, list):
            if s(root) == key:
                return root
            for child in root:
                r = find_section(child, key)
                if r:
                    return r
        return []

    for comp in find_section(data, "components")[1:]:
        info: dict = {}
        for field in comp[1:]:
            tag = s(field)
            if tag == "ref":
                info["ref"] = field[1]
            elif tag == "value":
                info["value"] = field[1]
            elif tag == "footprint":
                info["footprint"] = field[1]
            elif tag == "libsource":
                for sub in field[1:]:
                    if s(sub) == "part":
                        info["part"] = sub[1]
            elif tag == "fields":
                # Look for SKiDL's "SKiDL Line" field — source file pinpoints block
                for sub in field[1:]:
                    if s(sub) == "field":
                        # field structure: (field (name "SKiDL Line") "power.py:17")
                        for inner in sub[1:]:
                            if (
                                isinstance(inner, list)
                                and s(inner) == "name"
                                and len(inner) > 1
                                and inner[1] == "SKiDL Line"
                                and len(sub) > 2
                                and isinstance(sub[2], str)
                            ):
                                # field structure: (field (name "SKiDL Line") "power.py:17")
                                info["source"] = sub[2]
        if info.get("ref"):
            components.append(info)

    for net in find_section(data, "nets")[1:]:
        info = {"name": "", "nodes": []}
        for field in net[1:]:
            tag = s(field)
            if tag == "name":
                info["name"] = field[1]
            elif tag == "node":
                node = {}
                for sub in field[1:]:
                    if s(sub) == "ref":
                        node["ref"] = sub[1]
                    elif s(sub) == "pin":
                        node["pin"] = sub[1]
                    elif s(sub) == "pintype":
                        node["pintype"] = sub[1]
                if node:
                    info["nodes"].append(node)
        if info["name"]:
            nets.append(info)
    return components, nets


def _comp_nets_index(nets: list[dict]) -> dict[str, set[str]]:
    """Build {ref: {net_name, ...}} for all components."""
    idx: dict[str, set[str]] = {}
    for net in nets:
        for node in net["nodes"]:
            idx.setdefault(node["ref"], set()).add(net["name"])
    return idx


SOURCE_FILE_TO_BLOCK: Final = {
    "charger.py": "charger",
    "power.py": "power",
    "som.py": "som",
    "cellular.py": "cellular",
    "sensors.py": "sensors",
    "connectors.py": "connectors",
    "anemometer.py": "anemometer",
    "model.py": "connectors",  # model.py's _build_battery_connector previously
}


def _classify(comp: dict, comp_nets: set[str]) -> str:
    """Assign component to a block by SKiDL source file, then value, then nets."""
    # Best signal: SKiDL records the source file in a field
    src = comp.get("source", "")
    for fname, block in SOURCE_FILE_TO_BLOCK.items():
        if fname in src:
            return block
    val = comp.get("value", "")
    if val in VALUE_TO_BLOCK:
        return VALUE_TO_BLOCK[val]
    scores = {
        b: sum(1 for n in comp_nets if n in nets) for b, nets in BLOCK_NETS.items()
    }
    best = max(scores, key=scores.get)
    if scores[best] > 0:
        return best
    if {"5V_RAIL", "3V3"} & comp_nets:
        return "power"
    return "misc"


# Reason: a cell must hold the symbol (half-extent ≤ 10 wide / ≤ 14 tall for a
# 1x14 header) plus its 8-grid stubs on both sides, so no stub can reach a
# neighbour's pin end — that is the only way two nets ever merge on a sheet.
MIN_CELL_W: Final = 40
MIN_CELL_H: Final = 50


def _grid_for_block(n: int, w: int, h: int) -> tuple[int, int, int]:
    """Choose (cols, cell_w, cell_h) so n components fit in w x h with cells ≥ MIN_CELL."""
    if n == 0:
        return 1, w, h
    cols = max(1, min(n, w // MIN_CELL_W))
    rows = math.ceil(n / cols)
    if rows * MIN_CELL_H > h:
        raise ValueError(
            f"{n} components need {rows} rows of {MIN_CELL_H}; block is {h} tall"
        )
    return cols, w // cols, h // rows


BLOCK_TITLES: Final = {
    "charger": "SOLAR MPPT CHARGER",
    # Reason: no "/" in a sheet name — kicad-cli builds the export filename from it
    "power": "POWER RAILS",
    "som": "CM4 SoM",
    "cellular": "CELLULAR",
    "sensors": "IEEE 738 SENSORS",
    "connectors": "CONNECTORS",
    "anemometer": "ANEMOMETER RS-485",
    "misc": "MISC",
}


# Components whose symbol body is much taller than typical (multi-unit / many-pin).
# They get a dedicated column on the left of their block so their pin labels
# and body don't overflow into the grid of ordinary parts.
TALL_COMPONENT_VALUES: Final = {"BG770A-NA", "CM4_J2"}
TALL_COL_WIDTH: Final = 110  # grid units — BG770A body + stubs + label text


def _place_one(sch, comp: dict, gx: int, gy: int):
    """Instantiate a single component at (gx, gy)."""
    lib_id = f"{_resolve_lib(comp['part'])}:{comp['part']}"
    c = sch.components.add(
        lib_id, comp["ref"], comp.get("value", ""), position=(gx, gy)
    )
    if comp.get("footprint"):
        c.footprint = comp["footprint"]
    return c


def _place_block(sch, block_components: list[dict], region: dict) -> dict:
    """Place tall ICs in a left column, the rest in a deterministic sub-grid.

    No jitter: placement is a pure function of the netlist, so two runs give the
    same schematic and ERC result. Cross-net safety comes from MIN_CELL_* plus
    sch_guard.check_collisions, not from randomness.
    """
    placed: dict = {}
    ox, oy = region["origin"]
    w, h = region["width"], region["height"]

    tall = [c for c in block_components if c.get("value") in TALL_COMPONENT_VALUES]
    rest = [c for c in block_components if c.get("value") not in TALL_COMPONENT_VALUES]

    rest_ox, rest_w = ox, w
    if tall:
        row_h = h // len(tall)
        for i, comp in enumerate(tall):
            gx = ox + TALL_COL_WIDTH // 2
            gy = oy + i * row_h + row_h // 2
            placed[comp["ref"]] = _place_one(sch, comp, gx, gy)
        rest_ox = ox + TALL_COL_WIDTH
        rest_w = max(MIN_CELL_W, w - TALL_COL_WIDTH)

    n = len(rest)
    if n:
        cols, cw, ch = _grid_for_block(n, rest_w, h)
        for i, comp in enumerate(rest):
            row, col = divmod(i, cols)
            gx = rest_ox + col * cw + cw // 2
            gy = oy + row * ch + ch // 2
            placed[comp["ref"]] = _place_one(sch, comp, gx, gy)
    return placed


class PwrCounter:
    """Generates unique #PWR / #FLG references for power symbols."""

    def __init__(self):
        """Init counters."""
        self.n = 1
        self.flg = 1

    def pwr_ref(self) -> str:
        """Next unique #PWR ref."""
        ref = f"#PWR{self.n:03d}"
        self.n += 1
        return ref

    def flg_ref(self) -> str:
        """Next unique #FLG ref."""
        ref = f"#FLG{self.flg:03d}"
        self.flg += 1
        return ref


def _outward_direction(comp, pin_num: str) -> tuple[int, int]:
    """Direction the pin points outward from the symbol body (dx, dy in grid units).

    Uses the pin's own rotation attribute. Convention: kicad pin rotation 0
    means the pin LINE extends rightward INTO the symbol body, so the
    connection end (outer tip) is on the LEFT. Outward direction is the
    opposite of the pin line direction.
    """
    try:
        p = comp.get_pin(pin_num)
        if not p:
            return (-1, 0)
        rot = int(p.rotation) % 360
    except Exception:
        return (-1, 0)
    if rot == 0:
        return (-1, 0)  # pin points right into body -> outward left
    if rot == 180:
        return (1, 0)  # pin points left into body  -> outward right
    if rot == 90:
        return (0, 1)  # pin points up into body    -> outward down (+y in kicad = down)
    if rot == 270:
        return (0, -1)  # pin points down into body  -> outward up
    return (-1, 0)


def _add_nc_at_pin(sch, comp, pin_num: str) -> None:
    """Place a no-connect marker at a component pin (mm coords)."""
    try:
        pos_mm = _real_pin_position(comp, pin_num)
    except Exception:
        return
    if not pos_mm:
        return
    with contextlib.suppress(Exception):
        sch.no_connects.add(position=(pos_mm.x, pos_mm.y))


def _power_driven_nets(nets: list[dict]) -> set[str]:
    """Power nets that already have a Power-output driver (regulator output).

    A PWR_FLAG on such a net would conflict with the driver — ERC sees two
    Power-output pins on one net and reports pin_to_pin. Skip them.
    """
    driven: set[str] = set()
    for net in nets:
        for node in net["nodes"]:
            ptype = node.get("pintype", "").upper().replace("_", "-")
            if "POWER-OUT" in ptype:
                driven.add(net["name"])
                break
    return driven


def _power_input_nets(nets: list[dict]) -> set[str]:
    """Nets that feed at least one power-input pin."""
    inputs: set[str] = set()
    for net in nets:
        for node in net["nodes"]:
            ptype = node.get("pintype", "").upper().replace("_", "-")
            if ptype.startswith("POWER-IN"):
                inputs.add(net["name"])
                break
    return inputs


def flag_required_nets(nets: list[dict]) -> frozenset[str]:
    """Nets ERC will call undriven: they reach a power-input pin with no power-output pin.

    Reason: a rail fed through a passive — VBAT out of the battery connector, the
    charger's VCC through its 10 ohm filter — has no Power-output pin anywhere, so
    KiCad reports power_pin_not_driven until a PWR_FLAG declares it a source.
    """
    return frozenset(_power_input_nets(nets) - _power_driven_nets(nets))


def build_schematic() -> None:
    """Top-level — emit hierarchical multi-sheet schematic.

    Root .kicad_sch holds one sheet symbol per functional block; each block
    becomes its own dlr_carrier-<block>.kicad_sch child file.
    """
    from cad.schematic.multi_sheet import build_child_sheet, cross_block_nets
    from cad.schematic.root_sheet import build_root_sheet

    spec = yaml.safe_load(LAYOUT_SPEC_PATH.read_text())
    components, nets = _parse_netlist(NETLIST_PATH)
    comp_nets = _comp_nets_index(nets)

    by_block: dict[str, list[dict]] = {}
    for comp in components:
        block = _classify(comp, comp_nets.get(comp["ref"], set()))
        by_block.setdefault(block, []).append(comp)

    cross_nets = cross_block_nets(by_block, nets)
    # Every undriven rail needs exactly one PWR_FLAG in the hierarchy. The three
    # global power nets are flagged on the POWER sheet; a local rail (VBAT, CHG_VCC)
    # is flagged on whichever sheet owns it — first sheet to route it wins.
    flag_nets = flag_required_nets(nets)
    global_flags = frozenset(set(POWER_SYMBOL_BY_NET) & flag_nets)
    local_flags = flag_nets - set(POWER_SYMBOL_BY_NET)
    flagged: set[str] = set()
    root_path = Path(SCHEMATIC_PATH)
    block_sheets: list[tuple[str, str]] = []

    block_order = [
        "charger",
        "power",
        "som",
        "sensors",
        "cellular",
        "connectors",
        "anemometer",
        "misc",
    ]
    for block_name in block_order:
        comps = by_block.get(block_name, [])
        if not comps:
            continue
        child_filename = f"{root_path.stem}-{block_name}.kicad_sch"
        child_path = str(root_path.parent / child_filename)
        build_child_sheet(
            block_name,
            comps,
            nets,
            cross_nets,
            child_path,
            flag_nets=(global_flags if block_name == "power" else frozenset())
            | local_flags,
            flagged=flagged,
        )
        block_sheets.append((block_name, child_filename))

    build_root_sheet(block_sheets, str(root_path), spec["title"])


if __name__ == "__main__":
    build_schematic()
    print(f"Schematic: {SCHEMATIC_PATH}")

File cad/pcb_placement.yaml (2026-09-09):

# Component placement for cad/drawing/place_pcb.py — DLR carrier (mm from board origin, rotation deg)
#
# Layout on the 120x105 board:
#   Top-left:      SOLAR MPPT CHARGER (PV terminal, BQ24650 + FETs + 6.8uH, sense)
#   Left-middle:   5V buck (LMR33630 + 10uH + 470uF) and the 3V3 / 3V8 LDOs
#   Top-centre:    USB-C commissioning port (board edge, next to CM4 USB pins)
#   Top-right:     SoM (CM4 Hirose connector)
#   Mid-left:      SENSORS (FLIR FFC at left edge, DHT, SI, YL, ADS)
#   Mid-right:     CELLULAR (BG770A modem, TXS shifter, SIM, U.FL)
#   Bottom-left:   BAT terminal
#   Bottom-centre: ANEMOMETER RS-485 (SP3485 + M12 header at bottom edge) + DEBUG_UART
board_size: [120, 105]
board_origin: [100, 80]

blocks:
  charger:
    components:
      J1:  [10, 12, 0]      # PV terminal (5.08mm screw), left edge
      D1:  [22, 7,  0]      # SS34 reverse-polarity diode
      C1:  [22, 12, 0]      # 22uF/50V PV input bulk
      R17: [22, 16, 0]      # 10R VCC filter
      C31: [22, 19, 0]      # 1uF VCC
      R18: [30, 7,  0]      # 130k MPPSET top
      R19: [33, 7,  0]      # 10k MPPSET bottom
      R20: [36, 7,  0]      # 297k VFB top (0.1%)
      R21: [39, 7,  0]      # 49.9k VFB bottom (0.1%)
      U8:  [34, 14, 0]      # BQ24650RVAR
      C32: [29, 21, 0]      # 1uF VREF
      C33: [32, 21, 0]      # 1uF REGN
      R22: [24, 20, 0]      # 10k TS top
      R23: [27, 20, 0]      # 15k TS bottom
      R24: [24, 23, 0]      # 10k STAT1 pull-up
      R25: [27, 23, 0]      # 10k STAT2 pull-up
      Q1:  [44, 10, 0]      # DMN4035L-7 high-side
      Q2:  [44, 15, 0]      # DMN4035L-7 low-side
      C2:  [48, 7,  0]      # 100nF bootstrap PH-BTST
      D4:  [48, 12, 0]      # BAT54W bootstrap REGN->BTST
      L1:  [56, 12, 0]      # SRN8040TA-6R8M
      # Reason: SLUSA75B §11.1 — keep the sense resistor and its filter next to the
      # SRP/SRN pins. R1 previously sat 32 mm away with the sense pair crossing the
      # whole charger block, which is also where the router ran out of room.
      R1:  [46, 22, 0]      # 20m sense (1206), close to U8 pins 9/10
      C34: [40, 22, 0]      # 100nF SRP-SRN differential
      C35: [36, 25, 0]      # 100nF SRN-GND common-mode
      C3:  [56, 22, 0]      # 22uF/50V charger output

  power:
    components:
      C4:  [25, 28, 0]      # 10uF/50V buck input (1206)
      C5:  [25, 33, 0]      # 220nF/50V buck input HF
      U9:  [38, 30, 0]      # LMR33630ADDA
      C36: [32, 37, 0]      # 1uF VCC (internal LDO, §9.2.2.8)
      C6:  [44, 36, 0]      # 100nF BOOT
      L2:  [52, 30, 0]      # SRN8040TA-100M
      C7:  [63, 32, 0]      # 470uF polymer bulk
      C8:  [63, 39, 0]      # 22uF buck output
      C9:  [50, 38, 0]      # 100nF buck output
      R2:  [70, 28, 90]     # 100k FB top
      R3:  [70, 32, 90]     # 24.9k FB bottom
      U1:  [25, 46, 0]      # AP2112K-3.3 LDO
      U2:  [42, 46, 0]      # LP5907-3.8 LDO
      C10: [25, 52, 0]      # AP2112K Cin
      C11: [31, 52, 0]      # AP2112K Cout
      C12: [42, 52, 0]      # LP5907 Cin
      C13: [48, 52, 0]      # LP5907 Cout

  commissioning_usb:
    components:
      J12: [77, 4, 0]       # USB-C receptacle, opening 3mm back from the top edge
      R12: [72, 16, 0]      # CC1 5.1k Rd
      R13: [88, 16, 0]      # CC2 5.1k Rd

  som:
    components:
      # Reason: the DF40's 0.4 mm pitch needs a clear fan-out channel on both sides;
      # the decoupling caps sat 10 mm below and closed off the southern escape.
      J5:  [98, 16, 0]      # CM4_J2 Hirose (12x5mm)
      C14: [86, 28, 0]      # CM4 5V decoupling
      C15: [98, 28, 0]
      C16: [110, 28, 0]
      C17: [114, 16, 90]

  cellular:
    components:
      U3:  [92, 58, 0]      # BG770A-NA modem (22x26)
      U4:  [110, 50, 90]    # TXS0108E shifter
      J6:  [78, 45, 0]      # U.FL antenna
      J7:  [110, 82, 0]     # microSIM — library courtyard is 12x15, keep clear of U3
      C18: [78, 38, 0]      # 4.7uF VBAT_BB bulk
      C19: [82, 38, 0]      # 100nF VBAT_BB
      C20: [86, 38, 0]      # 100nF VDD_EXT_1V8
      C21: [72, 40, 0]      # ANT_IN DNP shunt
      C22: [90, 32, 0]      # ANT_MATCH DNP shunt
      C23: [104, 38, 0]     # USB_EXT_1V8
      C24: [114, 40, 0]     # 3V3 deco
      R5:  [70, 50, 0]      # ANT 0R series
      R6:  [82, 75, 90]     # OE pull-down
      R7:  [86, 75, 90]     # spare network resistor
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

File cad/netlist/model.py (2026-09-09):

"""DLR carrier board top-level netlist.

Wires power chain (solar -> MPPT -> battery -> buck -> LDOs) to:
  - CM4 SoM (som.py)
  - Cellular interface (cellular.py): BG770A + TXS0108E + u.FL
  - IEEE 738 sensors (sensors.py): FLIR + DHT22 + SI1145 + ADS1115/YL-83
  - Off-board connectors (connectors.py): battery + debug UART + USB-C commissioning
"""

import os

_SYM_DIR = "/usr/share/kicad/symbols"
for v in (
    "KICAD_SYMBOL_DIR",
    "KICAD6_SYMBOL_DIR",
    "KICAD7_SYMBOL_DIR",
    "KICAD8_SYMBOL_DIR",
    "KICAD9_SYMBOL_DIR",
):
    os.environ[v] = _SYM_DIR

import skidl  # noqa: E402

from cad.netlist.anemometer import build_anemometer  # noqa: E402
from cad.netlist.cellular import build_cellular  # noqa: E402
from cad.netlist.charger import build_mppt_charger, build_solar_input  # noqa: E402
from cad.netlist.connectors import (  # noqa: E402
    build_battery_connector,
    build_commissioning_usbc,
    build_debug_header,
)
from cad.netlist.power import build_buck_5v, build_ldo_3v3, build_ldo_3v8  # noqa: E402
from cad.netlist.sensors import build_sensors  # noqa: E402
from cad.netlist.som import build_cm4  # noqa: E402

NETLIST_PATH = "cad/dlr_carrier.net"


def build_netlist() -> None:
    """Define DLR carrier board in SKiDL and generate KiCad netlist."""
    # Power rails
    pv_in = skidl.Net("PV_IN")
    vbat = skidl.Net("VBAT")
    v5_rail = skidl.Net("5V_RAIL")
    v3v3 = skidl.Net("3V3")
    v3v8 = skidl.Net("3V8_CELL")
    gnd = skidl.Net("GND")

    # CM4 GPIO buses
    sda = skidl.Net("SDA1")
    scl = skidl.Net("SCL1")
    spi_mosi = skidl.Net("SPI0_MOSI")
    spi_miso = skidl.Net("SPI0_MISO")
    spi_sck = skidl.Net("SPI0_SCLK")
    spi_ce0 = skidl.Net("SPI0_CE0")
    uart_tx = skidl.Net("UART_TX_3V3")
    uart_rx = skidl.Net("UART_RX_3V3")
    gpio4 = skidl.Net("GPIO4_DHT22")
    gpio25 = skidl.Net("GPIO25_VSYNC")
    cell_en = skidl.Net("CELL_EN")
    usb_dp = skidl.Net("USB_DP")
    usb_dm = skidl.Net("USB_DM")
    # Reason: second USB pair from CM4 J1 OTG → sealed commissioning port (ADR-013)
    cmsn_dp = skidl.Net("USB_CMSN_DP")
    cmsn_dm = skidl.Net("USB_CMSN_DM")
    pwrkey = skidl.Net("CELL_PWRKEY")
    reset_n = skidl.Net("CELL_RESET")
    status = skidl.Net("CELL_STATUS")
    net_status = skidl.Net("CELL_NET_STATUS")
    shifter_oe = skidl.Net("SHIFTER_OE")
    dbg_tx = skidl.Net("DBG_TX")
    dbg_rx = skidl.Net("DBG_RX")
    anemo_uart_tx = skidl.Net("ANEMO_UART_TX")
    anemo_uart_rx = skidl.Net("ANEMO_UART_RX")
    anemo_de_n = skidl.Net("ANEMO_DE")
    chg_stat1 = skidl.Net("CHG_STAT1")
    chg_stat2 = skidl.Net("CHG_STAT2")

    # Power chain
    build_solar_input(pv_in, gnd)
    build_mppt_charger(pv_in, vbat, gnd, v3v3, chg_stat1, chg_stat2)
    build_battery_connector(vbat, gnd)
    build_buck_5v(vbat, v5_rail, gnd)
    build_ldo_3v3(v5_rail, v3v3, gnd)
    build_ldo_3v8(v5_rail, v3v8, cell_en, gnd)

    # SoM + consumers
    build_cm4(
        v5_in=v5_rail,
        v3v3=v3v3,
        gnd=gnd,
        sda=sda,
        scl=scl,
        spi_mosi=spi_mosi,
        spi_miso=spi_miso,
        spi_sck=spi_sck,
        spi_ce0=spi_ce0,
        uart_tx=uart_tx,
        uart_rx=uart_rx,
        gpio4=gpio4,
        gpio25=gpio25,
        cell_en=cell_en,
        usb_dp=usb_dp,
        usb_dm=usb_dm,
        cmsn_dp=cmsn_dp,
        cmsn_dm=cmsn_dm,
        pwrkey=pwrkey,
        reset_n=reset_n,
        status=status,
        net_status=net_status,
        shifter_oe=shifter_oe,
        dbg_tx=dbg_tx,
        dbg_rx=dbg_rx,
        anemo_uart_tx=anemo_uart_tx,
        anemo_uart_rx=anemo_uart_rx,
        anemo_de_n=anemo_de_n,
        chg_stat1=chg_stat1,
        chg_stat2=chg_stat2,
    )
    build_cellular(
        v3v8=v3v8,
        v3v3=v3v3,
        gnd=gnd,
        usb_dp=usb_dp,
        usb_dm=usb_dm,
        uart_tx_cm4=uart_tx,
        uart_rx_cm4=uart_rx,
        pwrkey=pwrkey,
        reset_n=reset_n,
        status=status,
        net_status=net_status,
        shifter_oe=shifter_oe,
    )
    build_sensors(
        v3v3=v3v3,
        gnd=gnd,
        sda=sda,
        scl=scl,
        spi_mosi=spi_mosi,
        spi_miso=spi_miso,
        spi_sck=spi_sck,
        spi_ce0=spi_ce0,
        gpio4=gpio4,
        gpio25=gpio25,
    )
    build_debug_header(v3v3, gnd, dbg_tx, dbg_rx)
    # Commissioning USB-C — sealed industrial port for live thermal preview
    # during integrator aim of the Lepton daughterboard tilt (ADR-013)
    build_commissioning_usbc(gnd, cmsn_dp, cmsn_dm)
    # Anemometer RS-485 — sensor-agnostic port. UART2 on GPIO0/1 (CM4
    # dtoverlay=uart2), DE on GPIO6. Supports high-wind (Calypso ULP STD)
    # and low-wind (Vaisala WMT702 / Gill WO65) SKUs from the same PCB.
    build_anemometer(
        vbat=vbat,
        v3v3=v3v3,
        gnd=gnd,
        uart_tx=anemo_uart_tx,
        uart_rx=anemo_uart_rx,
        de_n=anemo_de_n,
    )

    skidl.generate_netlist(file_=NETLIST_PATH, tool=skidl.KICAD8)


if __name__ == "__main__":
    build_netlist()
    print(f"Netlist: {NETLIST_PATH}")

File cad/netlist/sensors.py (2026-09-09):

"""IEEE 738 sensor suite: FLIR Lepton 3.5, DHT22, SI1145, ADS1115 + YL-83.

FLIR Lepton represented as a 14-pin breakout header (GroupGets module pinout).
DHT22 uses the DHT11 symbol (same physical layout) + 10k pull-up on data line.
SI1145 + YL-83 use generic module headers (Adafruit-style breakouts).
ADS1115IDGS reads YL-83 analog out on AIN0; I2C ADDR tied LOW for 0x48.
"""

import skidl

FP_C_0402 = "Capacitor_SMD:C_0402_1005Metric"
FP_R_0402 = "Resistor_SMD:R_0402_1005Metric"
FP_HEADER_2_54 = "Connector_PinHeader_2.54mm:PinHeader_1x{n}_P2.54mm_Vertical"


def _cap(ref: str, value: str, fp: str, n1: skidl.Net, n2: skidl.Net) -> None:
    c = skidl.Part("Device", "C", ref=ref, value=value, footprint=fp)
    n1 += c[1]
    n2 += c[2]


def _res(ref: str, value: str, fp: str, n1: skidl.Net, n2: skidl.Net) -> None:
    r = skidl.Part("Device", "R", ref=ref, value=value, footprint=fp)
    n1 += r[1]
    n2 += r[2]


def _module_header(ref: str, n_pins: int, label: str) -> skidl.Part:
    """Single-row 2.54mm pin header for off-board sensor breakout modules."""
    p = skidl.Part(
        "Connector_Generic",
        f"Conn_01x{n_pins:02d}",
        ref=ref,
        footprint=FP_HEADER_2_54.format(n=f"{n_pins:02d}"),
    )
    p.value = label
    return p


def build_flir_lepton(
    v3v3: skidl.Net,
    gnd: skidl.Net,
    sda: skidl.Net,
    scl: skidl.Net,
    spi_mosi: skidl.Net,
    spi_miso: skidl.Net,
    spi_sck: skidl.Net,
    spi_ce0: skidl.Net,
    vsync: skidl.Net,
) -> None:
    """FLIR Lepton 3.5 SPI/I2C link via 14-pin FFC to off-board daughterboard.

    Per ADR-013: Lepton mounts on a separate daughterboard so its lens can be
    aimed at the conductor below the cross-arm independently of the main PCB.
    This function adds the Hirose FH12-14S-0.5SH FFC connector on the main
    carrier; the daughterboard (separate KiCad project under cad/lepton_daughter/)
    hosts the Molex 32-pin Lepton socket.

    Pin map preserves the GroupGets 14-pin breakout signal order so the same
    Lepton breakout schematic is reusable on the daughterboard.

    1=GND  2=CS   3=MOSI  4=MISO  5=SCK   6=VSYNC  7=GPIO3
    8=SDA  9=SCL  10=PWR_DN_L  11=RESET_L  12=GND  13=3V3  14=VIN
    """
    j = skidl.Part(
        "Connector_Generic",
        "Conn_01x14",
        ref="J8",
        footprint=(
            "Connector_FFC-FPC:" "Hirose_FH12-14S-0.5SH_1x14-1MP_P0.50mm_Horizontal"
        ),
    )
    j.value = "FLIR_LEPTON_FFC"
    gnd += j[1]
    spi_ce0 += j[2]
    spi_mosi += j[3]
    spi_miso += j[4]
    spi_sck += j[5]
    vsync += j[6]
    skidl.Net("LEPTON_GPIO3") & j[7]
    sda += j[8]
    scl += j[9]
    # PWR_DN_L and RESET_L pulled high through FFC (active-low, default-deasserted)
    _res("R7", "10k", FP_R_0402, j[10], v3v3)
    _res("R8", "10k", FP_R_0402, j[11], v3v3)
    gnd += j[12]
    v3v3 += j[13]
    v3v3 += j[14]  # VIN tied to 3V3 (daughterboard powered from main 3V3 rail)
    _cap("C25", "100nF", FP_C_0402, v3v3, gnd)


def build_dht22(v3v3: skidl.Net, gnd: skidl.Net, gpio4: skidl.Net) -> None:
    """DHT22 ambient temp/humidity — 4-pin module + 10k pull-up on data line."""
    u = skidl.Part(
        "Sensor", "DHT11", ref="U5", footprint="Sensor:Aosong_DHT11_5.5x12.0_P2.54mm"
    )
    u.value = "DHT22"
    v3v3 += u["VDD"]
    gnd += u["GND"]
    gpio4 += u["DATA"]
    _res("R9", "10k", FP_R_0402, gpio4, v3v3)
    _cap("C26", "100nF", FP_C_0402, v3v3, gnd)


def build_si1145(
    v3v3: skidl.Net, gnd: skidl.Net, sda: skidl.Net, scl: skidl.Net
) -> None:
    """SI1145 UV/visible/IR sensor — Adafruit-style 5-pin breakout.

    1=VIN  2=GND  3=SCL  4=SDA  5=INT (NC)
    """
    j = _module_header("J9", 5, "SI1145")
    v3v3 += j[1]
    gnd += j[2]
    scl += j[3]
    sda += j[4]
    skidl.Net("SI1145_INT") & j[5]
    _cap("C27", "100nF", FP_C_0402, v3v3, gnd)


def build_ads1115_yl83(
    v3v3: skidl.Net, gnd: skidl.Net, sda: skidl.Net, scl: skidl.Net
) -> None:
    """ADS1115 ADC + YL-83 rain sensor on AIN0. ADDR=LOW -> I2C 0x48."""
    u_ads = skidl.Part(
        "Analog_ADC",
        "ADS1115IDGS",
        ref="U6",
        footprint="Package_SO:MSOP-10_3x3mm_P0.5mm",
    )
    u_ads.value = "ADS1115"

    rain_ao = skidl.Net("RAIN_AO")
    v3v3 += u_ads["VDD"]
    gnd += u_ads["GND"]
    sda += u_ads["SDA"]
    scl += u_ads["SCL"]
    gnd += u_ads["ADDR"]  # LOW -> I2C address 0x48
    rain_ao += u_ads["AIN0"]
    skidl.Net("NC_ADS_AIN1") & u_ads["AIN1"]
    skidl.Net("NC_ADS_AIN2") & u_ads["AIN2"]
    skidl.Net("NC_ADS_AIN3") & u_ads["AIN3"]
    skidl.Net("NC_ADS_ALERT") & u_ads["ALERT/RDY"]
    _cap("C28", "100nF", FP_C_0402, v3v3, gnd)
    _cap("C29", "10nF", FP_C_0402, rain_ao, gnd)  # anti-aliasing on analog input

    # YL-83 rain sensor 4-pin module: VCC, GND, AO, DO
    j = _module_header("J10", 4, "YL-83")
    v3v3 += j[1]
    gnd += j[2]
    rain_ao += j[3]
    skidl.Net("YL83_DO") & j[4]


def build_sensors(
    v3v3: skidl.Net,
    gnd: skidl.Net,
    sda: skidl.Net,
    scl: skidl.Net,
    spi_mosi: skidl.Net,
    spi_miso: skidl.Net,
    spi_sck: skidl.Net,
    spi_ce0: skidl.Net,
    gpio4: skidl.Net,
    gpio25: skidl.Net,
) -> None:
    """All four IEEE 738 sensors on the carrier."""
    build_flir_lepton(v3v3, gnd, sda, scl, spi_mosi, spi_miso, spi_sck, spi_ce0, gpio25)
    build_dht22(v3v3, gnd, gpio4)
    build_si1145(v3v3, gnd, sda, scl)
    build_ads1115_yl83(v3v3, gnd, sda, scl)

    # I2C pull-ups — 2.2k to 3V3 (per theory section 3, ADR-005)
    _res("R10", "2.2k", FP_R_0402, sda, v3v3)
    _res("R11", "2.2k", FP_R_0402, scl, v3v3)

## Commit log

2026-09-09 ⚡ fix(power): real BQ24650 charger + LMR33630 buck, sourced parts
    The charger was a placeholder: a generic 16-pin connector symbol on an HVQFN
    footprint with a bootstrap cap, an inductor and a sense resistor. The BQ24650 has
    no internal FETs, so as captured it had no switching devices, no VFB or MPPSET
    divider, no VCC/VREF/REGN bypass, no bootstrap diode, a floating TERM_EN and pin
    numbers that did not match the real device. It could not have charged a battery.
    Charger now follows SLUSA75B (ADR-015): 2x DMN4035L-7 (40 V for a 21 V Voc panel),
    BAT54W bootstrap, 297k/49.9k 0.1% VFB -> 14.60 V, 130k/10k MPPSET -> 16.8 V,
    20 mOhm sense -> 2 A, TS biased inside its valid window, STAT1/STAT2 to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
    [anemometer.py, cellular.py, charger.py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]
2026-09-09 🧪 feat(sim): ngspice transient models for the 5V rail
    PySpice was a dependency with conventions documented in CLAUDE.md but no caller —
    every "simulation" in the repo was closed-form algebra. Two real transient models
    now run under ngspice against the exact passives the netlist places:
    * spice_ripple: open-loop switching stage, checks SNVSAN3F Eq 7 output ripple
    * spice_load_step: averaged current-mode converter with the datasheet current
    limits and the inductor's di/dt limit, driven through the CM4 boot peak
    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
2026-09-09 🗺 feat(cad): scripted schematic + board pipeline, 4-layer stack
    The committed board had almost every pad on +3V3 — no 5V_RAIL, VBAT or SDA1 net
    existed on it at all — so the gerbers in output/ were never a valid board. Cause:
    "Update PCB from Schematic" is GUI-only, so nothing kept the board honest, and the
    schematic generator itself was merging nets.
    Schematic generator:
    * power stubs now run along the pin direction; they used to be forced up or down
    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
    [bom.csv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]
2026-09-09 👷 fix(ci): gate ERC on errors, report DRC without gating
    The first run of the new ERC gate went red for the wrong reason. A runner with no
    KiCad library tables configured cannot resolve symbol or footprint links, and
    reports each one as a warning — 332 of them — while --exit-code-violations counts
    warnings as well as errors. There were zero actual ERC errors.
    ERC now runs with --severity-error, so it gates on real violations and passes on a
    bare runner. DRC runs with --refill-zones and reports, but does not gate yet: the
    board still carries the 5-connection punch list in readme.md, and those are genuine
    errors. The "|| true" comes off once they are routed.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
2026-09-09 👷 fix(ci): decide ERC/DRC pass-fail from the report, not the exit code
    --exit-code-violations counts warnings as violations, and its exit codes differ
    between kicad-cli builds — the runner returned 1 where this machine returns 5, and
    --severity-error did not filter there either. Both gates now count "; error" lines
    in the report file, which behaves the same on any build and cannot be fooled by a
    runner that lacks KiCad's library tables (every symbol link becomes a warning there:
    332 on a bare environment, still zero errors).
    Verified both ways locally: ERC errors 0 with libraries configured and with a bare
    HOME; DRC errors 5, matching the punch list in readme.md.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
2026-09-09 👷 chore(ci): log the KiCad version and keep the ERC/DRC reports
    The ERC gate passes locally and fails on the runner with 117 errors, and the counts
    alone do not say which rule fires. Log kicad-cli version and archive both reports so
    the difference is diagnosable from the job rather than by guesswork.
    Claude-Session: https://claude.ai/code/session_011xr7VCL7rkJj2WE2uQF7sF
2026-09-09 🩺 fix(schematic): repair the sheet hierarchy metadata
    ERC was clean on KiCad 10 here and reported 117 errors on the CI runner's KiCad
    9.0.2 — 60 dangling labels and 57 sheet pins with "no matching hierarchical label".
    The names all matched; the hierarchy itself was malformed:
    * the root's sheet instances were serialized as `(project None ...)`, a literal
    Python None where the project name belongs
    * every child declared `(sheet_instances (path "/" (page "1")))`, so each one
    claimed to be the root page instead of carrying its own instance path
    KiCad 10 tolerates both and resolves the hierarchy anyway; KiCad 9 cannot, and then
    reports every cross-sheet connection as broken. l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
    [dlr_carrier-anemometer.kicad_sch, dlr_carrier-cellular.kicad_sch, dlr_carrier-charger.kicad_sch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]
2026-09-09 🩺 fix(schematic): match hierarchical label type to the sheet pin
    The 117 KiCad 9 errors were a type mismatch, not the hierarchy metadata: every
    child hierarchical label was written as `(shape input)` while the root's sheet pins
    are bidirectional. KiCad's hier_label_mismatch check compares electrical type as
    well as name, so on KiCad 9 every cross-sheet net failed, and the root labels then
    read as dangling. KiCad 10 tolerates the mismatch, which is why it passed here.
    kicad-sch-api 0.5.6 accepts a shape argument on add_hierarchical_label and ignores
    it — the third serialization bug worked around in this generator — so the shape is
    rewritten in the saved sheet.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
    [dlr_carrier-anemometer.kicad_sch, dlr_carrier-cellular.kicad_sch, dlr_carrier-charger.kicad_sch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]
2026-09-09 🩺 refactor(schematic): cross-sheet nets via global labels, no sheet pins
    Three attempts at making the hierarchical sheet-pin mechanism pass KiCad 9 failed
    (project name, instance paths, label type), so the mechanism goes. Cross-sheet nets
    now connect by name through global labels on the child sheets; the root carries
    sheet symbols only — no pins, no stub wires, no labels.
    That removes the whole hier_label_mismatch / label_dangling class rather than
    chasing it, and it matches the connectivity style the generate-schematic skill
    already prescribes for this project ("all inter-block connections use net labels").
    kicad-sch-api's add_global_label still does not serialize, so the labels are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
    [dlr_carrier-anemometer.kicad_sch, dlr_carrier-cellular.kicad_sch, dlr_carrier-charger.kicad_sch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]
2026-09-09 👷 fix(ci): say when DRC cannot run instead of reporting nothing
    The DRC step printed "DRC errors:" with an empty count and the job passed. It was
    not passing a check: the runner's KiCad 9.0.2 cannot open a KiCad 10 board file
    (version 20260206), so no report was written and the count was empty. A check that
    silently verifies nothing is worse than no check.
    validate-asm now distinguishes the two cases — no report means "DRC DID NOT RUN"
    with the offending kicad-cli version, a report means a real error count. The readme
    records which tool version each artifact needs, and why cross-sheet nets use global
    labels rather than hierarchical sheet pins.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
2026-09-09 📝 docs(readme): board status and toolchain, history dropped
    Keep what is true now — the 5-connection punch list, and that the board needs
    KiCad 10 (the runner gets it from Flatpak). The KiCad 9 vs 10 narrative belongs in
    git history, not the readme.
    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
2026-09-10 📋 chore(docs): record the devops role and the commit/CI rules
    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
2026-09-10 🧭 feat(pcb): finish the routing in code with an A* escape router
    Freerouting and close_gaps always leave a few pins on the 0.4 mm DF40 and the
    0.5 mm VQFN/MSOP whose only exit is straight out of the pad and then around
    several obstacles. close_gaps can only draw L-shapes, so it cannot express the
    path even where one exists; hand-routing them in pcbnew works but is a GUI step
    the pipeline is supposed to have none of.
    maze_grid/maze_field/maze_search/maze_escape are a windowed A* over a 0.05 mm
    grid on F.Cu and B.Cu with via layer changes. Clearance comes from analytic
    distance fields, and only copper of *other* nets is an obstacle — a pin may
    leave through its own pad, which is what the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
2026-09-10 🩺 fix(pcb): close three fine-pitch escapes and the duplicate drill hits
    The escape router and the rip-up loop take the board from 5 open connections to
    2: U6.8 (MSOP-10 3V3), U8.10 (VQFN BAT_SRP) and J5.17 (DF40 3V3) are routed, and
    the plane-net trunks that ran through the DF40 fanout band are gone — GND now
    drops into In1.Cu where those trunks used to fence the pad rows in.
    Five vias that shared a hole, and two more whose 0.3 mm drills sat 0.03 mm apart
    and would have broken into each other, are removed. DRC is now clean of
    clearance, short, annular-ring, hole and courtyard errors; 7 silkscreen-overlap
    warnings and the 2 open pins are all that is left.
    Both open pins are DF40 ground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
    [dlr_carrier-B_Courtyard.gbr, dlr_carrier-B_Cu.gbl, dlr_carrier-B_Fab.gbr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]
2026-09-10 🧩 feat(pcb): assign fine-pitch escape vias before anything routes them
    A 0.4 mm pad pitch cannot give every pin a via in one row — two 0.6 mm vias need
    0.75 mm between centres, so only every other pin fits. The pins that miss out
    have to reach a second, deeper row, and two adjacent vias in the first row leave
    a 0.15 mm slot where a 0.2 mm trace with 0.15 mm either side needs 0.5 mm. Once
    the first row exists the second is unreachable, so a router that takes the
    nearest free site per pin always strands somebody however hard it searches. That
    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
2026-09-18 🏷️ chore(repo): rename dlr-pcb to dlr-rtu-pcb
    GitLab (origin) and GitHub (mirror) projects renamed via glab/gh.
    Updates package name, mirror push target, badges, and BOM SKU refs
    to match; regenerates uv.lock for the new project name.
2026-09-19 📝 docs(claude): update DLR/DER repo references for rename
    dlr-operating-envelope -> dlr-rtu-firmware, dlr-pst-sim -> dlr-tap-regulator-sim,
    dlr-pcb -> dlr-rtu-pcb (catching an earlier incomplete sweep).
    Claude-Session: https://claude.ai/code/session_01CtABAPEShKJhC6HoFGDHbj
2026-10-02 📝 docs: dlr-tap-regulator-sim renamed to dlr-line-loading-sim
    Name updated only -- the diagram's "tap adjustment commands" edge
    still describes the old (now-removed) tap-control behavior, which is
    a separate content-accuracy follow-up, not done here.
    Claude-Session: https://claude.ai/code/session_01G9oodV6qNjghBfbi7qXfrt
